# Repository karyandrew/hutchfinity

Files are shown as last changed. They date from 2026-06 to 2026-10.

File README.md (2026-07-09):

---
sensitivity: public
version: 1.0.0
---

# hutchfinity

A parametric, modular drawer chest system built around gridfinity-extended tubs at **half-pitch**.

## What

- **Tubs** = drawer pans, sized in cells (X × Y × Z) at user-chosen pitch
- **Casings** = single-piece enclosures that house one tub each; back + sides + top, no bottom, no front
- **Pegs** = press-fit dowels that link stacked casings vertically
- **Knobs** = optional glue-on pulls with broad, thin glue bases
- **Magnets** = optional press-fit retention + extended-warning detent

Tubs slide drawer-style on the top of the casing below (or on a footer / tabletop for the bottom-most). Casings stack into chests of arbitrary height. Same flat casing footprint = stackable; varying heights are fine. Multi-column chest assembly is a v2 goal.

## Why half-pitch

Gridfinity's standard pitch (42mm XY, 7mm Z) is too coarse for many small-parts organization use cases. The hutchfinity system uses **21mm XY / 3.5mm Z** — half of standard on each axis — for denser packing of small bins while preserving compatibility with standard gridfinity bin foot geometry. Bins printed for one pitch system can sit alongside bins printed for the other.

## Status

Pre-1.0. Architecture spec converged; SCAD and STL deliverables are being authored.

- **License**: GNU GPL v3.0 only; see `LICENSE` and `THIRD_PARTY_NOTICES.md`
- **Source**: OpenSCAD, built on top of [Gridfinity Extended OpenSCAD](https://github.com/ostat/gridfinity_extended_openscad)

## Credits

Gridfinity was created by **Zack Freedman** ([Hack Smith Industries](https://hackaday.io/project/180371-hack-smith-industries)). This project extends the gridfinity ecosystem; it isn't affiliated with the original creator.

## Contributing

Issues and PRs welcome.

## Repository map

- `wiki/` - evergreen implementation notes and validated recipes.
- `adr/` - architecture decision records.

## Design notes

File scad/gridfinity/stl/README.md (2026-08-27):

# Gridfinity STL files

For new tub and baseplate prints, use:

- `tub-mini.stl`
- `tub-regular.stl`
- `tub-mega.stl`
- `baseplate-mini.stl`
- `baseplate-regular.stl`
- `baseplate-mega.stl`

## Deprecated cropped baseplates

The following files are retained for historical comparison only and are not part of the current print set. Do not use them for new prints:

- `baseplate-mini-cropped.stl`
- `baseplate-regular-cropped.stl`
- `baseplate-mega-cropped.stl`

Height-specific tub variants and bin STLs elsewhere in this directory are unaffected by this deprecation.

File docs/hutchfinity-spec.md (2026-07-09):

---
version: 0.18.7
sensitivity: public
---

# Hutchfinity system spec

This technical spec translates `docs/chest-prd.md` into module contracts for the authored Hutchfinity SCAD parts. The chest PRD remains the product authority; this page defines the first casing interface so `casing.scad` can exist without silently deciding the provisional magnet and peg recipes.

## Casing contract

`scad/casing.scad` emits one drawer-slot casing in print orientation: the casing top is on the build plate and the side/back walls rise upward. The physical part has a top, left side, right side, and back; it has no front and no bottom. The current prototype cuts flat-wall stack sockets and provisional casing-side magnet wells by default.

The casing module is tub-agnostic. It accepts direct slot dimensions rather than importing `tub.scad` or deriving from tub cell count, pitch, or wall thickness. Assembly-level files such as `scad/hutchfinity-assembly.scad` choose casing slot dimensions that match a tub or preview target.

The target enclosed slot range is 200-450mm wide, 200-450mm deep, and 25-450mm tall. The current representative casing uses width for left/right across the drawer opening and depth for front/back drawer travel. For the regular tub, casing width spans the tub width, while casing depth uses the shared 16-cell front-to-back tub dimension. Stacked casings use the same flat casing footprint and prototype peg/socket geometry.

## Files

| File | Role |
|---|---|
| `scad/casing.scad` | Standalone casing shell with flat-wall stack peg sockets and provisional casing magnet wells. No tub import, no footer mode. |
| `scad/tub.scad` | Mini/regular/mega tub wrappers that import the current tub STLs and cut provisional bottom magnet wells. |
| `scad/peg.scad` | Prototype laid-down hex peg. |
| `scad/knob.scad` | Optional glue-on tub pull with a broad, thin flared base. |
| `scad/hutchfinity-assembly.scad` | Preview/assembly caller that can place casing, tub, knob, and pegs together. |
| `scad/casing-fit-test.scad` | Fit-test caller that maps current tub-source dimensions and named clearance candidates to a casing slot. |
| `scad/testbed/peg_socket_fit_testbed.scad` | Cheap coupon for provisional peg/socket clearance and chamfer checks. |
| `scad/testbed/hex_peg_set.scad` | Seven loose hex pegs for one representative casing stack interface. |
| `scad/testbed/peg_stack_interface_testbed.scad` | Rejected stack-land coupon retained only as a failed design reference. |
| `scad/testbed/casing_mouth_fit_gauge.scad` | Shallow front-mouth gauge for checking tub entry and top clearance before printing a full casing. |
| `scad/testbed/full_magnetic_drawer_inspection_set.scad` | Installed-coordinate inspection exports for aligned casing/tub magnet-interface and slot-fit checks. |
| `scad/testbed/magnet_well_shape_inspection.scad` | Real-CAD face coupons showing the current 5mm tub and 6mm casing magnet-well profiles. |
| `scad/testbed/mini_regular_mega_print_set.scad` | Selector source for the mini/regular/mega casing, magnetic tub, knob, and peg print packet. |
| `scad/testbed/build-mini-regular-mega-print-set.sh` | Builds the mini/regular/mega print packet and copies the matching committed grid baseplates. |
| `scad/testbed/casing-fit-trial-01.md` | Planned physical validation log for the #20 casing fit and peg/socket coupon print. |

No shared `hutchfinity-dimensions.scad` file is part of this pass.

## Coordinate convention

| Axis | Meaning |
|---|---|
| X | Left/right across the drawer opening. |
| Y | Front/back; `Y=0` is the open front, the back wall is at maximum Y. |
| Z | Print Z. `Z=0` is the bed-facing top surface; walls rise in +Z from the top slab. |

This convention keeps the STL in the intended no-support print orientation. In installed use, the bed-facing slab is the upper riding surface and the open side opposite it is the missing bottom. Documentation should name whether a dimension is a print-coordinate value or an installed-use value when ambiguity matters.

Socket face naming is deliberately explicit: installed-top sockets open on print `Z=0` through the top slab, while installed-bottom sockets open on the print `Z=print_z` wall-foot faces. The casing still has no bottom plate.

The PRD requires flat side and back exterior faces. External stack lands, pads, bosses, lugs, ribs, or other protrusions on the casing sides/back are rejected even if they would give peg sockets more material.

## Dimensional formulas

Default values are intentionally conservative fit-test numbers, not final ergonomic values. The current representative XY target is a thick-wall regular 12 x 16 tub with `256.4mm` left/right width and `340.4mm` front/back length from `docs/gridfinity-system-prd.md`. The fit-test caller maps that tub to a `258.4 x 340.9 x 85.24mm` slot: `1.0mm` side clearance per side, `0.5mm` closed-back clearance, and `1.0mm` top clearance. The current source tub height is 23u body height, so the tub exterior height is `23 * 3.5 + 3.74 = 84.24mm`, matching the rounded `84.2mm` total Z listed in `docs/gridfinity-system-prd.md`. The earlier PR #19 `73.74mm` value was a 20u representative casing target, not the current regular tub source height.

Thickness requirements are not finalized here. The printed part will not behave like a solid-wall analytical beam: slicer wall loops, sparse infill density/pattern, material, nozzle, and layer height all matter. This spec therefore keeps thicknesses as named prototype parameters rather than deriving them from a structural formula.

`scad/casing-fit-test.scad` is the physical-fit caller for issue #20. It separates three concepts that should not be conflated:

| Concept | Where it belongs | Notes |
|---|---|---|
| Tub source dimensions | `docs/gridfinity-system-prd.md` and tub build scripts | Current regular tub source is 23u total height with `2.2mm` walls, not the PR #19 20u casing target. |
| Casing slot clearance | `scad/casing-fit-test.scad` / assembly mapping | Geometry clearance around the printed tub; side, back, and top clearances are named separately. |
| Slicer contour compensation | Slicer/process profile and trial notes | The observed `+0.6mm` contour-compensation result was tub-print process evidence. It is not a casing wall-thickness formula. |

| Term | Formula / default | Notes |
|---|---|---|
| `slot_width` | `258.4mm` in the fit caller | Direct enclosed slot width: left/right across the drawer opening; tub width plus side clearance. |
| `slot_depth` | `340.9mm` in the fit caller | Direct enclosed slot depth: front/back drawer travel; shared tub front/back length plus closed-back clearance. |
| `slot_height` | `85.24mm` in the fit caller | Direct enclosed slot height for the current 23u source tub plus top clearance. |
| `outer_x` | `slot_width + 2 * side_thickness` | Includes left and right walls. |
| `outer_y` | `slot_depth + back_thickness` | Includes back wall; no front wall. |
| `print_z` | `top_thickness + slot_height` | Top slab plus wall height in print orientation. |
| `peg_axis_intervals_between` | `max(1, ceil((end - start) / peg_spacing))` | Derived; not an argument. |
| `peg_count` | length of perimeter socket positions | Derived from one `peg_spacing`; not an argument. |

There is no `bottom_thickness` term. The casing has no floor/bottom plate.

## Parameters

| Parameter | Default | Status |
|---|---:|---|
| `slot_width`, `slot_depth`, `slot_height` | `256.4, 340.4, 84.24` in `casing.scad`; `258.4, 340.9, 85.24` in the regular fit caller | Casing stays slot-dimension based; assembly/fit callers add tub clearance. |
| `side_thickness` | `25` | Prototype side wall value. |
| `back_thickness` | `25` | Prototype back wall value. |
| `top_thickness` | `10` | Prototype ceiling/riding surface; bed-facing in print orientation. |
| `peg_spacing` | `190` | Single target spacing. Count is derived per side and positions divide evenly between derived end insets. |
| `peg_diameter`, `peg_clearance` | `8, 0.45` | Prototype peg/socket fit values. |
| `peg_socket_depth`, `peg_chamfer` | `10, 2.5` | Prototype top-slab through-sockets and wall-foot sockets with generous chamfers at both ends. |
| `peg_socket_edge_land` | `4.0` | Minimum material land used when checking socket chamfer clearance. |
| `enable_peg_holes` | `true` | Cuts prototype top-slab sockets and matching wall-foot receiver sockets into the flat side/back wall footprints. |
| `enable_magnet_holes` | `true` | Cuts provisional casing magnet wells into the installed top surface. |
| `casing_magnet_bore_diameter`, `casing_magnet_rib_tip_diameter` | `6.40, 6.10` | Current 6mm magnet press-fit candidate. |
| `casing_magnet_well_depth`, `casing_magnet_chamfer` | `1.60, 0.30` | Current 6mm magnet pocket depth, `0.4mm` shallower than the 2.0mm recovery-sled pocket family. |
| `casing_magnet_fore_aft_inset` | `8.0` | Magnet center inset from the front/back travel edges. |
| `casing_magnet_paramedian_offset` | `21.0` | Lateral offset for the optional paramedian columns around the centerline. |
| `extended_warning_travel_fraction` | `0.75` | Places the rear-pair warning detent wells at 75% drawer travel. |
| `show_debug_markers` | `false` | Optional reference-point markers only when peg holes are disabled. |

Not casing arguments: tub cell counts, pitch values, tub wall thickness, tub-to-slot clearance, bottom thickness, footer/base controls, `peg_count`, and `peg_edge_margin`. Those belong to tub generation, assembly mapping, a future footer/base design, or a future validated interface.

## Provisional interfaces

Magnet dimensions are not final in this spec. `wiki/magnet-press-fit.md`, hutchfinity#7, and PR #13 remain the live sources for magnet press-fit validation.

The casing module now cuts nine provisional magnet wells into the installed top surface, which is print `Z=0`: six closed-position wells in two front/back rows and three lateral columns, plus three rear-magnet wells at 75% drawer travel as an extended-warning detent. The lateral columns are median and paramedian, centered on the drawer midline with `21mm` offsets. The current casing recipe is an 8-rib bore-minus-notch well: `6.40mm` bore, `6.10mm` rib-tip diameter, `1.60mm` deep, with a `0.30mm` chamfer.

`scad/tub.scad` wraps the current mini, regular, and mega tub STLs and cuts six bottom magnet wells in two front/back rows and three median/paramedian lateral columns. The current tub recipe is an 8-rib bore-minus-notch well: `5.40mm` bore, `5.25mm` rib-tip diameter, `1.10mm` deep, with a `0.30mm` chamfer. These wrappers do not make `casing.scad` depend on the tub model.

The casing module cuts prototype peg sockets by default. The stack is casing-to-casing: the bottom wall feet of an upper casing sit on the top slab of the casing below, and pegs register that pair. The open front span has no sockets because there is no front wall-foot receiver in the casing above.

The external stack-land approach tested in the previous model is rejected by the flat side/back requirement. Current casing sockets are centered in the 25mm side/back wall footprints and spaced from the open front and rear edges by the derived socket end inset.

Peg sockets use generous 2.5mm chamfers at their openings and deepest ends. `scad/peg.scad` uses a laid-down hex profile with no crush ribs. The default printable peg is 8.45mm point-to-point, matching the current `8.0mm` nominal socket plus `0.45mm` prototype socket clearance. The module `hutchfinity_peg()` still models the installed vertical peg for assembly use; `hutchfinity_peg_print_layout()` rotates it onto a flat-friendly face for standalone/testbed printing. The casing stack interface remains provisional until tested on an actual casing pair.

`scad/testbed/peg_socket_fit_testbed.scad` renders a small clearance sweep using the same socket cutter and laid-down hex peg print module: `0.30`, `0.45`, and `0.60mm` socket clearance around the 8mm nominal socket diameter, tested against an 8.45mm point-to-point hex peg. The raised index marks count from left to right. This coupon is a physical validation aid, not a locked press-fit recipe.

Footer behavior is outside `casing.scad`. A footer, tabletop, or future base/riser belongs in assembly-level design, not in the casing module argument surface.

## Render checks

Minimum first-pass check:

```bash
openscad -o preview/casing-representative.stl scad/casing.scad
```

Generated review artifacts should live under `preview/<issue-or-head>/` or another explicit trial directory. Avoid suffixes such as `final`; they do not say what changed or what commit produced the file.

Fit-test caller check:

```bash
openscad -o preview/casing-fit-trial-01/casing-fit-regular-23u.stl scad/casing-fit-test.scad
openscad -o preview/casing-fit-trial-01/fit-pr19-20u-check.stl -D FIT_TUB_HEIGHT_U=20 scad/casing-fit-test.scad
```

Peg/socket coupon check:

```bash
openscad -o preview/casing-fit-trial-01/peg-socket-fit-testbed.stl scad/testbed/peg_socket_fit_testbed.scad
openscad -o preview/casing-fit-trial-01/hex-peg-set-7.stl scad/testbed/hex_peg_set.scad
openscad -o preview/casing-fit-trial-01/tub-regular-magnetic.stl scad/tub.scad
```

Do not render or print `scad/testbed/peg_stack_interface_testbed.scad` for the current validation pass. It is retained only as a failed reference for the rejected external stack-land approach.

Assembly caller check:

```bash
openscad -o preview/casing-fit-trial-01/assembly-check.stl scad/hutchfinity-assembly.scad
openscad -o preview/casing-fit-trial-01/hex-peg-check.stl scad/peg.scad
openscad -o preview/casing-fit-trial-01/knob-check.stl scad/knob.scad
```

Physical validation packet:

```bash
openscad -o preview/casing-fit-trial-01/casing-mouth-fit-gauge.stl scad/testbed/casing_mouth_fit_gauge.scad
openscad -o preview/casing-fit-trial-01/casing-fit-regular-23u.stl scad/casing-fit-test.scad
openscad -o preview/casing-fit-trial-01/tub-regular-magnetic.stl scad/tub.scad
openscad -o preview/casing-fit-trial-01/peg-socket-fit-testbed.stl scad/testbed/peg_socket_fit_testbed.scad
openscad -o preview/casing-fit-trial-01/hex-peg-set-7.stl scad/testbed/hex_peg_set.scad
scad/testbed/build-mini-regular-mega-print-set.sh
```

Aligned inspection packet:

```bash
openscad -o preview/casing-fit-trial-01/aligned-inspection/casing-installed.stl -D INSPECTION_PART=1 scad/testbed/full_magnetic_drawer_inspection_set.scad
openscad -o preview/casing-fit-trial-01/aligned-inspection/tub-on-casing-top-closed.stl -D INSPECTION_PART=2 scad/testbed/full_magnetic_drawer_inspection_set.scad
openscad -o preview/casing-fit-trial-01/aligned-inspection/tub-in-slot-closed.stl -D INSPECTION_PART=4 scad/testbed/full_magnetic_drawer_inspection_set.scad
openscad -o preview/casing-fit-trial-01/aligned-inspection/pegs-installed.stl -D INSPECTION_PART=6 scad/testbed/full_magnetic_drawer_inspection_set.scad
```

Record the physical result in `scad/testbed/casing-fit-trial-01.md`. Casing and mouth-gauge artifacts print inverted; flip them into installed orientation for fit testing, with the slab above the tub and the walls down. The mouth gauge is a cheaper entry/ceiling check only; it does not replace full-depth casing slide validation. The current regular trial uses `1.0mm` side clearance per side, `0.5mm` at the closed back, and `1.0mm` above the tub.

For visual review, render a PNG from the same file when OpenSCAD is available. If OpenSCAD is unavailable, static syntax and parameter review are still required, and the missing renderer is reported in the PR.

## Acceptance criteria

- Casing dimensions are direct slot parameters, not coupled to tub internals.
- The casing has no front and no bottom.
- Same flat casing footprint casings cut a prototype two-ended peg/socket interface for vertical stacking.
- Tub body geometry is not rewritten to create the slide path.
- Optional knob geometry has a broad, thin glue base for tub attachment.
- Magnet geometry is present in the casing and mini/regular/mega tub wrappers, and stays explicitly provisional until physical validation closes the dependency.

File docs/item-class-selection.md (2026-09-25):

---
sensitivity: public
version: 1.1.0
---

# Neutral item-class selection

The selection contract maps generic geometry and handling needs to the existing half-pitch bin catalog. It deliberately separates three evidence levels:

1. Current-source geometry gives wall span, floor shape, and open-top height.
2. A rendered STL supplies an exact artifact hash and mesh bounding box.
3. Independently trusted physical and lane evidence supplies actual load, retrieval, base-engagement, and handling evidence.

Only the third level can support `ACCEPTED`. The first two remain `PROVISIONAL` even when every calculated margin is positive.

## Current catalog inventory

The generated inventory contains 126 tracked bin STLs:

- 22 are named by the current build script and are eligible for selection;
- 104 are tracked but unmanaged by the current build script, are marked `stale`, and are excluded; and
- 0 currently have a reproduced current-source-to-output byte link.

Each record includes the last commit touching the bound source/artifact paths (so committing this catalog or unrelated documentation does not invalidate it), SHA-256 hashes for the build recipe and vendored cup source, the exact STL SHA-256 and byte count, and parsed mesh AABB, volume, and triangle count. The mesh metrics are inventory and ranking evidence only.

The current official OpenSCAD snapshot can parse and render the unchanged source, so the historical OpenSCAD 2021 parser failure is obsolete. The selected current-source renders are geometrically consistent with the tracked artifacts by bounding box and rounded volume but are not byte-identical. No tracked STL is replaced here, and every source/output link remains `unverified`.

For current 21 mm-pitch, minimum-lip bins, the source-derived dimensions are:

```text
wall thickness = 0.95 mm below 6h, 1.2 mm below 12h, otherwise 1.6 mm
wall span XY   = cells × 21 − 0.5 − 2 × wall thickness
floor height   = 5.7 mm
open-top Z     = height_units × 3.5 + 3.74 − 5.7
floor radius   = 3.75 − wall thickness
flat-floor span XY = wall span − 2 × floor radius
```

The wall span is larger than the conservative full-footprint span because the cavity has rounded floor edges. That distinction matters for rigid flat objects and prevents a mesh or wall bounding box from being presented as a fit oracle.

## Deterministic selection

For every allowed orientation, the selector:

- rotates item dimensions, uncertainty, and requested grab clearance together;
- forms a required envelope by adding dimension + uncertainty + clearance on each known axis;
- rejects negative wall-span margins and rounded-corner conflicts;
- applies minimum long-axis, unobstructed-top, quantity, and flat-floor constraints;
- treats missing axes and a wall-pass/floor-fail split as `inconclusive`;
- rejects unsupported compartment, visibility, and retrieval-mode requirements;
- ranks passing build-managed SKUs by footprint, then height, parsed material-volume proxy, and wasted source-derived volume; and
- reports one next sufficient candidate when one exists.

A negative margin is a failure, never a “tight” pass. `CUSTOM_SKU_REQUIRED` is emitted only when a fully dimensioned class has no passing current candidate and no named inconclusive physical-fit target.

The numeric uncertainty and clearance values in `item-classes.json` are public v1 selection-policy inputs, not physical measurements or private quantities. Changing one changes the item-class hash and invalidates receipts bound to the prior revision.

## Initial mapping result

| Neutral class | Preferred target | Fallback | Source result |
|---|---|---|---|
| `long-rod-178` | `bin-2x9x10h` | `bin-2x10x10h` | Inconclusive: long-axis margin is 2.8 mm after uncertainty and grab clearance; cross-section and Z are intentionally unknown. |
| `square-stack-49` | `bin-3x3x10h` | `bin-3x5x10h` | Calculated pass: wall margins 5.6 × 5.6 × 0.54 mm; conservative flat-floor XY margins 0.5 × 0.5 mm. |
| `short-roll-40x15` | `bin-2x4x10h` | `bin-2x5x10h` | Calculated pass: the 81.1 mm wall span satisfies the 80 mm long-axis constraint; conservative clearance-envelope capacities are 2 and 4. Desired private capacity remains external. |
| `flat-185x82x13` | `bin-5x9x5h` | none | Inconclusive: positive wall margins include 0.6 mm on the long axis, but conservative flat-floor long-axis margin is −5.0 mm. Physical sampling is mandatory. |

All four rows remain `PROVISIONAL`: no exact artifact/item-class physical fit was run. The two calculated passes are geometry/handling calculations, not physical acceptance.

## Software checks, physical evidence, and downstream demand

The CLI now schema-checks closed dataset wrappers, records, demand requests, and generated output with date-time format enforcement. It resolves mappings against the repository's authoritative class set and catalog, recomputes class hashes and selections, and verifies current source and selected artifact bytes. A local physical-receipt claim is checked against the authoritative class envelope, minimum quantity, exact STL hash, lane fields, six physical checks, and workaround prohibition.

Those checks prove software structure, byte binding, and internal consistency only. Local caller-controlled JSON cannot prove that a sample was measured, an artifact was printed, a lane receipt came from an independent authority, or any physical check occurred. With no independently trusted physical/lane evidence configured, the CLI refuses every `ACCEPTED` claim and therefore refuses accepted-demand promotion. It does not create a signer or trust anchor from its own output.

The useful software residue is the closed neutral contract, authoritative binding, deterministic fit calculations, strict quantity/date handling, and fail-closed non-authorizing demand boundary. The remaining acceptance work is physical: preserve independently trusted lane evidence, print the exact artifact, bind a representative sample or surrogate, perform all fit and handling checks, and resolve the long-rod unknown axes and flat-object floor conflict. All four current mappings remain `PROVISIONAL/not_run`, and production authorization remains outside this interface.

## Local use

Use Python 3.10+ and `jsonschema` 4.x. The catalog is generated with
`python3 scripts/hutchfinity_catalog.py build-catalog --output catalog/bin-skus.json`.
Then run `select` with `--catalog catalog/bin-skus.json`,
`--classes catalog/item-classes.json`, and `--output catalog/item-class-map.json`.
Run the owned suite with `python3 -m unittest discover -s tests -v`.

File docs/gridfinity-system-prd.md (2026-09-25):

---
sensitivity: public
version: 5.1.3
---

# Gridfinity System PRD — Dental Practice Organization

**Audience:** agents drafting and testing SCAD models for the dental gridfinity system. Read this before designing or modifying any tub / baseplate / bin config. It's the owner's north star — your work points at it.

This is a PRD, not an SOP. It captures intent. The inventory operating manual lives at [`kary-dental/docs/dental_office_inventory_guide.md`](https://github.com/karyandrew/kary-dental/blob/main/docs/dental_office_inventory_guide.md); category and material inventory by operatory specialty lives in the "Dental Armamentarium" gdoc (planned for ingest into kary-dental).

## What you're building

Three printable artifact types, all at Gridfinity Extended (half pitch — 21mm XY, 3.5mm Z) — a deliberate variant of stock Gridfinity, not interoperable with 42mm parts.

| Artifact | Role |
|---|---|
| **Tubs** (3 SKUs: mini, regular, mega) | Bounding containers that sit in operatory drawers or on shelves/counters. PETG. Implemented as 1×1 Gridfinity Extended cups at custom pitch — walls and lip live outside the cell grid. Same model printed in different colors per operatory specialty. |
| **Internal baseplates** (3 sizes, one per tub) | Vanilla Gridfinity grid plate (just a grid — no clips, no locks). Drops into a tub at standard 21mm pitch. Bins sit on it via standard Gridfinity foot pattern. |
| **Bins** | Standard Gridfinity cups at 21mm pitch with foot pattern. Mix-and-match across all tubs. Color-coded per inventory category. Staff-printable. |

## Hard requirements (owner-stated)

| # | Requirement | Rationale |
|---|---|---|
| HR-1 | **Tubs stack on each other** (drawer + shelf use). Lip of lower tub seats the flat base of upper tub. Stackability is per-pitch — same-size tubs stack; mixed sizes do not. | Drawer is primary; shelf storage is real and frequent. Without stackability the system breaks for shelf use. |
| HR-2 | **Bins sit on the baseplate via standard Gridfinity foot pattern.** No clip, no lock — gravity + foot fit. | Baseplate is a vanilla gridfinity grid. Standard part. Don't invent locking mechanisms. |
| HR-3 | **Tubs and bins are portable; bins mix-and-match across tubs.** | Same internal grid pitch (21mm) everywhere = bins move freely between any tub without re-fit. |
| HR-4 | **Constrained model catalog.** All tubs share Z and depth (Y); only width (X) varies — 3 SKUs total. Bin sizes drawn from a small standard set. Don't spawn a new model per quirk. | Production sanity, visual consistency, learnable system. |
| HR-5 | **Easy to print, cheap to replace.** Bins must be staff-printable on a Bambu (no manual supports, no exotic settings, predictable). PETG, normal layer heights, no orientation tricks. | Replacement is routine, not engineering. Staff is not Andrew. |
| HR-6 | **Items retrievable by finger or college plier.** Bin geometry must permit one-handed access during procedures. | Point-of-use clinical work. No tool-fetching to retrieve. |
| HR-7 | **Color codes the operatory specialty (tub) and inventory category (bin).** | Glance-to-find is the primary navigation system. Labels are SKU-level (required); color is category-level (convenience). |
| HR-8 | **Label-bearable surface on every bin.** Brother P-Touch labels (12mm or 24mm with QR) adhere to bin walls, floors, or undersides. | Item ID labels are required (line in inventory guide). No special label holders — use existing bin geometry surfaces. |
| HR-9 | **No captured crevices.** Tub, baseplate, and bins are independent pieces that separate cleanly for cleaning. | Clinical setting; biofilm and disinfectant residue trap in crevices. |
| HR-10 | **Single-piece tub at all standard sizes (≤500mm bed).** | Seams capture debris. SV08 MAX is 500×500×500mm; mega tub fits as one piece. |
| HR-11 | **PETG body** (tubs, baseplates, bins). Autoclavable parts (cassettes, bur blocks) are a separate workstream on X2D / PPA-GF — not this PRD. | PETG: tough, dishwasher-tolerant, printable on the fleet, cheap. Autoclave-grade is overkill for organizers. |
| HR-12 | **Walls and lip live outside the cell grid.** Tub internal cavity is exactly `N × 21mm` (X) × `M × 21mm` (Y) so the internal baseplate at standard 21mm pitch fits natively. | Inverts the v2.0.0 architecture (tub-as-scaled-bin); the baseplate seats into a cell-grid-sized cavity rather than a wall-eaten cavity. |
| HR-13 | **No magnet holes, no label holders, no scoops on any bin** — for the whole catalog lineage, including prototypes, until owner reverses. Labels adhere directly to bin geometry per HR-8. | Tactile cleanliness, print simplicity, fewer crevices. Reinforces HR-9 (no captured crevices) and HR-5 (staff-printable, predictable). |

## Color codes

Each operatory specialty maps to a color. Tubs are printed in that color; bins per category in that operatory may further encode item type (sub-color or hue variant — TBD).

| Color | Category | Mnemonic source |
|---|---|---|
| Green | Hygiene | Cavitron tip, mint toothpaste |
| Blue | Endo & IVS | Blu Core |
| Pink | Removable | Denture acrylic |
| Gray | Ortho | Brackets |
| Yellow | Restorative | Bonding agent |
| Orange | Fixed + Crown + Implant pros | Rely-X Universal; revised from Black to free Black for Records/Eval. Crown is the most common subset of Fixed → shares. Implant pros is fixed-prosth-on-implants → same logic, shares. |
| Black | Records/Eval | X-ray |
| Purple | Perio | (perio = purple by convention) |
| Red | Surgery / Exo | Bloody socket |
| Brown | General consumables | Weak alliteration ("Brown" / "Basic"). Brown items show up across many specialties — basic exam kit (mirror, explorer, cotton tweezers, 11/12 explorer), anesthesia carpules, chairside disposables (microbrushes, air/water tips). |
| (no specialty color) | Anesthesia & Sedation | Cart-level supply rather than a specialty workflow — staff goes to the cart, not the color. Default un-coded PETG. |
| N/A | Pedo, Cosmetic/Bleaching, Photography | Not in current practice scope. |

**Color rules:**
- **White is the wildcard** — allowed on any tub or bin, but **cannot be assigned to a specialty**. Assigning white to a category would break glance-to-find: any uncoded white piece would falsely signal that category. White means "nonspecific," everywhere.
- Orange / Yellow proximity is acceptable — Fixed and Restorative share a lot of workflow; confusing the two is harmless.
- Color stability is load-bearing — once staff learns "green = hygiene," reassigning the color burns trust. Color → category mapping changes go through Andrew, not the agent.

## Drawer compatibility

Tub catalog must serve this drawer set:

| Drawer | H × W × D interior (mm) | Plan | Slack W × D (mm) | H slack (mm) |
|---|---|---|---|---|
| Cart shallow | 74 × 318 × 419 | **excluded** (tub Z 84.2 > 74) | — | −10.2 |
| Cabinet narrow | 89 × 305 × 381 | 1× regular | 49.8 × 41.8 | 4.8 |
| **Cabinet med** (15"=381 wide; dominant) | 89 × 381 × 381 | 1× regular + 1× mini | **−3.4 × 41.8** (W interference; v5.0.0 marginal — physical drawer test gates validation) | 4.8 |
| Cabinet x-wide (24") | 89 × 610 × 381 | 1× mega + 1× mini *or* 2× regular | 99.6 × 41.8 (M+m) / 99.6 × 41.8 (2R) | 4.8 |
| Cart standard | 89 × 318 × 419 | 1× regular | 62.8 × 79.8 | 4.8 |
| Cart medium | 114 × 318 × 419 | 1× regular; items extend above tub | 62.8 × 79.8 | 29.8 |
| Cart deep | 140 × 318 × 419 | 1× regular; items extend above tub | 62.8 × 79.8 | 55.8 |
| Counter | TBD | 1× mega | TBD | TBD |

**Key principle:** items / bins may stick up above the tub Z. Tub height isn't sized to fill the drawer — only to retain bins, give structural rigidity, and provide the stacking lip. Bins are flexible (fast to reprint, waste OK). Tub catalog stays small (3 SKUs).

**Mini's two pairing roles:**
1. Alongside regular in cabinet med (binding constraint; pinned mini width to 5 cells in v3.x at W=2.625, bumped to 6 cells in v4.0.0 at W=1.6 — fit becomes marginal, gated on physical drawer test).
2. Alongside mega in cabinet x-wide.

## Architecture

Tubs are implemented as **1×1 Gridfinity Extended cups at custom pitch**, not as N×M bins. The cell-grid pitch (21mm) is unchanged; what changes per tub size is the cup's outer pitch.

```
pitch_xy = N × 21 + 2W + C   // C = library cup-outer clearance — see Tolerances
width = [1, 0]
depth = [1, 0]
height = [23, 0]              // body 23×3.5 = 80.5mm; sized so a 20h max bin's lip top
                              // does not exceed lower body top → upper tub bottom clears
                              // bin lip when tubs stack (see Vertical stack-fit section)
wall_thickness = W
floor_thickness = 1.2         // vendor default (was 3.5 in v3.x)
lip_style = "minimum"
flat_base = "gridfinity"      // stackable via lip on tubs of same pitch
```

Cavity (actual) = `pitch_xy − C − 2W` per library at `gridfinity_basic_cup.scad:798` (`container_width = num_x × pitch − clearance − 2 × wall_thickness`). With `pitch_xy = N × 21 + 2W + C`, cavity = `N × 21` exactly. Internal baseplate exterior renders at `N × 21` exactly — the library does NOT apply outer clearance to baseplates; the `clearance` parameter in `gridfinity_baseplate.scad` affects internal pocket sizing, not the outer envelope. Cavity and baseplate are the same `N × 21` dimension by construction; design clearance is zero. PETG dimensional variance (~±0.2mm typical) provides the natural play that lets the baseplate seat without binding.

Same-size tubs stack on each other (shared pitch_xy → matched lip pattern). Mixed-size tubs do not stack.

### Wall thickness

**W = 2.2mm** — explicit tub wall value. This is the CAD replacement for the `+0.6mm` slicer contour-compensation hack that improved printed tub stacking and strength; do not carry that compensation into casing wall thickness.

Tubs retain bins and provide the stacking lip, but the earlier `1.6mm` wall setting was too weak in physical prints. The prior v3.x value of 2.625mm (= 21/8 — "pitch elegance") is still rejected as cosmetic; `2.2mm` is the current physical-fit compromise. Cup walls are independently set by the cup library default of 1.2mm at h<16u; tubs and cups don't need to match.

Floor thickness `floor_thickness=1.2mm` follows the same logic — vendor `default_floor_thickness` (line 518). Prior 3.5mm "floor sandwich" was over-spec; thinner floor + same body height grows the cavity Z. Z is just `Nu body`, and cavity Z is whatever's left after `floor_thickness`. v5.0.0 sets body height to **23u** (was 21u in v4.x) — sized so a 20h max bin's lip top sits at or below the lower body top, allowing tub-on-tub stacking without the upper tub crashing into bin lips. See [Vertical stack-fit](#vertical-stack-fit-half-pitch-correction) for the geometry derivation.

## Stock Gridfinity baseplate compatibility

Half-pitch (21mm) cells preserve a real backward-compat surface to stock 42mm Gridfinity baseplates: **any 2×2-or-larger arrangement of half-pitch bins mates a stock 42mm baseplate** (verified in hand). 1×1 half-pitch bins do NOT — the half-scaled foot is too small for the stock pocket and rattles. Footprint commensurability (2 half-pitch cells = 1 stock cell) plus the library-canonical foot pattern is what makes the mate work.

This compatibility constrains foot/lip geometry choices going forward:

- **Slimmer half-pitch feet** would mitigate the half-pitch sandwich math (recovering ~7mm of tub Z by reducing the foot+lip+floor sandwich consumption) but **would also erode the stock-baseplate mate.** Foot-to-pocket lock relies on chamfer engagement, and chamfer geometry is foot-height-dependent — shorter foot = different chamfer profile = degraded engagement to stock pockets. The stock-baseplate compat is tested-and-valued, so slim-foot proposals are blocked unless the export-compat is explicitly waived.
- **Importing stock 42mm community designs** is independent of foot height — boolean surgery (strip stock foot, add half-pitch foot pattern) works regardless of slimming choices. Slim feet would only break the *export* direction (half-pitch arrangement → stock baseplate), not the import direction.

Considered and rejected: switching to 25mm pitch (Nested Tub System PRD 1.0.0 candidate, archived 2026-05-13 at [`docs/archive/nested-tub-system-prd.md`](archive/nested-tub-system-prd.md)). 25mm forfeits stock-baseplate mate entirely with no offsetting concrete benefit. Per-axis rationale at [`docs/archive/prd-decision.md`](archive/prd-decision.md).

## Tolerances

All multi-part fits are tracked here as named terms. PRD edits that change any tolerance update both this table and the architecture math, in the **same PR as the SCAD/STL change** they affect. Tribal knowledge ages out; the PRD is the contract.

| Term | Value | Where it lives | What it does |
|---|---|---|---|
| `C` (library cup-outer clearance) | 0.5mm total (= 0.25/side) | Library default, applied automatically to cup outer: lip extent = `pitch_xy − C`. Not a tunable knob in wrappers. | Spaces adjacent same-pitch tubs apart so 2× regular in cabinet x-wide sit with ~0.25mm/side between them. |
| Tub cavity ↔ baseplate | 0mm design clearance (snug; PETG variance is the slop) | Tub `pitch_xy` formula sets cavity = `N × 21` = baseplate exterior. | Baseplate seats on tub floor without rattle. Not a sliding fit — installed once. |
| Bin foot ↔ baseplate pocket | 0.5mm total (Gridfinity standard) | Library default in cup foot vs baseplate cell math. | Bins drop in/out of pockets one-handed. |
| Tub exterior ↔ drawer | per-drawer slack column in Drawer compatibility table (smallest = **−3.4mm interference**, cabinet med — v4.0.0 marginal, validates by physical print) | Drawer compatibility table. | Finger access; survives temperature/humidity expansion. |
| Tub stack mate | 0 (gridfinity foot ↔ lip is intentionally snug) | Library `flat_base = "gridfinity"`. | Two same-size tubs lock by foot/lip geometry, not by clearance. |

## Vertical stack-fit (half-pitch correction)

Standard gridfinity assumes "tub of N units holds bin of (N − 1) units" — at full pitch (1u = 7mm), the floor + bin foot + bin lip sandwich consumes ~1u of vertical space and the rule works. **At half-pitch (1u = 3.5mm) the lib does NOT scale the cupbase / lip / floor constants down**, so the sandwich consumes more than 1u and the rule breaks.

### Empirical geometry (mini tub, half-pitch)

Verified by spot-probing the rendered STLs at cell centers:

| Surface | Z (mm) | Notes |
|---|---|---|
| Tub foot pattern bottom | 0 | external |
| Tub foot pattern top | 4.75 | = `gf_cupbase_*_taper_height` sum (NOT `gf_base_grid_clearance_height`) |
| **Tub interior cavity floor** | **4.75** | floor sits on top of foot pattern; `floor_thickness=1.2` is in addition but is "inside" the body Z |
| Baseplate (sitting on cavity floor) | 4.75 → 8.75 | 4mm thick |
| **Bin Z=0 (= foot bottom)** | **4.75** | baseplate pocket is open through, so foot rests at pocket-bottom = baseplate bottom |
| Bin lip top | 4.75 + N×3.5 + 3.74 | lip = 3.74mm constant |
| Tub body top | N_tub × 3.5 | |
| Tub rim (= body top + lip) | N_tub × 3.5 + 3.74 | |

### Stack-fit invariant

When two same-size tubs stack, the upper tub's external bottom seats at the lower tub's body top (= `N_tub × 3.5`). For the upper tub bottom to NOT crash into bin lip tops in the lower tub:

```
bin lip top ≤ lower tub body top
4.75 + N_bin × 3.5 + 3.74 ≤ N_tub × 3.5
8.49 + N_bin × 3.5 ≤ N_tub × 3.5
N_bin ≤ N_tub − 2.43

→ rule (rounded for clearance):  N_bin ≤ N_tub − 3
```

So at half-pitch a **23h tub holds a 20h max bin** with 2.01mm clearance below the upper tub bottom when stacked. v4.x's 21h tub left a 20h bin protruding 2.96mm above the rim — broke HR-1.

### Off-by-one history

- Initial v5.0.0 attempt bumped 21h → 22h, but bin lip top still exceeded body top by 1.49mm. The half-pitch sandwich is ~3h, not the standard ~1h.
- Discovered by building an empirical assembly (tub + baseplate + bins + stacked upper tub) in OpenSCAD and bbox-probing each component's Z extent.
- Methodology: render each isolated piece (`probe-1h-lipnone.stl`, etc), spot-probe at cell centers via `intersection() { import(stl); cube at (X, Y, Z); }`, find the Z transition where solid → cavity.
- Closes [#146](https://github.com/karyandrew/3d-printing/issues/146).

## Tub catalog

Three SKUs. Identical Z and depth (Y); only width (X) varies.

| Tub | Cells (W × D × H) | pitch_xy (X × Y mm) | Cavity W × D (mm) | Cavity Z (mm) | Exterior W × D (mm) (= pitch_xy − C) | Total Z incl lip (mm) |
|---|---|---|---|---|---|---|
| Mini | 6 × 16 × 23  | 130.9 × 340.9 | 126 × 336 | 79.3 | 130.4 × 340.4 | 84.2 |
| Regular | 12 × 16 × 23 | 256.9 × 340.9 | 252 × 336 | 79.3 | 256.4 × 340.4 | 84.2 |
| Mega | 18 × 16 × 23 | 382.9 × 340.9 | 378 × 336 | 79.3 | 382.4 × 340.4 | 84.2 |

Mini bumped 5→6 cells X in v4.0.0; H bumped 21→23 in v5.0.0 (see Vertical stack-fit section).

Lip protrusion above body ≈ 3.74mm (constant — does NOT scale with pitch_z). Cavity Z = body − floor_thickness = 80.5 − 1.2 = 79.3mm.

| Param | Value (all 3 SKUs) |
|---|---|
| Pitch (cell grid) | 21 × 21 × 3.5mm |
| Wall thickness | 2.2mm |
| Base | Flat (`flat_base="gridfinity"`) |
| Lip | `lip_style="minimum"` |
| Floor | 1.2mm (vendor default) |
| Material | PETG |
| Printer | SV08 MAX |
| Nozzle / layer | 0.6mm / 0.3mm |

## Baseplate specs

Three baseplates, one per tub size. Standard 21mm Gridfinity pitch. Exterior = `N × 21` exactly — library does NOT apply outer clearance to baseplates (`clearance` in `gridfinity_baseplate.scad` affects internal pocket sizing, not the outer envelope). Cavity = `N × 21` by construction (see Architecture); design clearance is zero.

| Baseplate | Cells (W × D) | Exterior W × D (mm) | Tub cavity | Design clearance |
|---|---|---|---|---|
| Mini | 6 × 16  | 126 × 336 | 126 × 336 | 0 (snug) |
| Regular | 12 × 16 | 252 × 336 | 252 × 336 | 0 (snug) |
| Mega | 18 × 16 | 378 × 336 | 378 × 336 | 0 (snug) |

All single-piece printable (largest = 378mm < SV08 500mm bed).

| Param | Value (all 3) |
|---|---|
| Pitch | 21 × 21mm (standard Gridfinity) |
| Z thickness | ~4mm |
| Pattern | Vanilla Gridfinity grid (through-pockets, one per cell) |
| Material | PETG |
| Printer | SV08 MAX, single piece |

No clips, no special locks. Baseplate sits in the tub bottom, bins drop in via foot pattern.

## Bin specs

Standard bin set — keep tight. Add only when inventory→bin mapping forces it.

| Param | Value |
|---|---|
| Pitch | 21 × 21 × 3.5mm |
| Base | Foot pattern (`flat_base="off"`) |
| Lip | `lip_style="minimum"` (note: reduced lip on small bins is a derived spec to preserve interior volume + finger access — not a separate requirement) |
| Compartments | Single (`vertical_chambers=1`, `horizontal_chambers=1`) baseline; multi-compartment as inventory demands |
| Color | Per inventory category (see Color codes table) |
| Material | PETG (default) |
| Printer | X2D primary bin/cup lane under the matching current #37 validation receipt; SV08 only under its own matching validated lane; no retired-printer dependency |
| Nozzle / layer | 0.4mm / 0.2mm |
| Print constraint | No manual supports. No orientation tricks. Predictable for staff to run. (HR-5) |

Two physical instances of each bin per item per operatory (front = active, back = reserve — 2-bin pattern from inventory guide).

**Foot-pattern gotcha (read before editing `dental/build-stl.sh`):** bins MUST use `flat_base="off"` (library default) so the cup gets N×M individual feet at the cell pitch and mates baseplate pockets. Do NOT copy `flat_base="gridfinity"` from `TUB_FLAGS` — that collapses the entire N×M footprint to ONE big pad (per `pad_copy` logic in `scad/gridfinity/vendor/extended/gridfinity_basic_cup.scad:7801`). The `gridfinity` value is only correct for tubs because tubs stack on each other lip-to-foot; bins sit IN baseplates. Tripped on first bin build (rebuilt as commit `eb24396`).

**HR-13 reminder (cross-reference):** no magnets, no label holders, no scoops on bins. `BIN_FLAGS` sets `enable_magnets=false`, `enable_screws=false`, `label_style="disabled"`, `fingerslide="none"` explicitly so the rule is visible at the build call site even though the library defaults already match.

## Owner success criteria

System works when all hold:

1. **Drawer fit.** Each tub size seats in its target drawer (per Drawer compatibility table). Closes and opens without binding. Finger-access clearance preserved.
2. **Stackability.** Two same-size tubs stack stably on a level surface; lift the upper tub from the lip without lower tub coming with it under <500g vertical force.
3. **Baseplate seat.** Baseplate sits flat on the tub floor at 0mm nominal design clearance; any observed slack comes from print variance. It doesn't lift when bins are removed.
4. **Bin retrieval.** Items in any bin can be picked with a college plier or a finger; one-handed; no tools to extract the bin itself.
5. **Mix-and-match.** Bins move from any tub to any other tub and seat correctly without re-fitting.
6. **Staff-printable.** A trained assistant prints a replacement bin from STL → slicer → printer → done. No agent intervention.
7. **Glance-to-find.** Person who's seen the color legend once can locate the tub for a category in <3s on a shelf or in an open drawer.
8. **2-bin operatory pattern.** Empty back-position is visible at a glance; restock between patients.
9. **Subjective.** Team reaction is "holy shit this is sweet," not "what the fuck is this mess." Owner judges; agents don't override.
10. **Artifact- and printer-lane validation gate.** Before production, the exact artifact family and printer/profile/material tuple must have a current matching #37 `PASS_CURRENT_PROFILE` receipt that remains valid under #37's invalidation rules. Large tubs/large parts use the SV08 large-part lane; bins/cups use the X2D bin/cup lane by default. #38 may start only the matching production run; a pass in one lane does not authorize another.

## Open items (do NOT silently decide)

When you hit one of these, surface as a blocker — don't pick.

The production split is no longer open: #37/#38 assign large tubs and large parts to the SV08 MAX lane and bins/cups to the X2D lane by default. Any substitution requires its own matching validation receipt and run manifest.

| # | Item | Blocker |
|---|---|---|
| 1 | Bin sub-color within a tub (item type vs whole-tub-uniform) | UX question — owner |
| 2 | Standard bin size set (final) | Inventory→bin mapping; expected to evolve months 1–2 of practice operation per inventory guide |
| 3 | Counter-use megatub footprint (when counter dimensions need a bigger SKU than 18×16) | Counter measurement; current mega is locked to 18×16 for cabinet x-wide compatibility |

## Implementation guidance

**File paths:**
- Vendored library: `scad/gridfinity/vendor/<lib>/` + `VENDOR.md` (SHA + provenance)
- Dental build script: `scad/gridfinity/dental/build-stl.sh`
- Rendered STLs: `scad/gridfinity/stl/`
- Bins (when introduced): `scad/gridfinity/dental/bin-{X}x{Y}x{Z}.scad` — cells X × Y × cell-height Z. Build mechanism for bins is TBD (likely added as a second pass in `build-stl.sh` once bin work starts).

**Build pattern:** `dental/build-stl.sh` is a plain bash script that invokes the vendor combined file directly via `openscad -D <var>=<value>` flags. Project-level constants (wall thickness, lip style, floor thickness, chambers, magnets/screws) live in `TUB_FLAGS` / `BASEPLATE_FLAGS` arrays at the top of the script. Per-SKU params (pitch X for tubs; Width for baseplates) inline per invocation line. Adding a SKU = one new line. **Do not introduce per-SKU wrapper `.scad` files**; the WET wrapper pattern was the v3.0.0/v3.1.0 architecture and was retired in v3.2.0 (see Anti-patterns).

**STL naming:** `tub-{mini,regular,mega}.stl`, `baseplate-{mini,regular,mega}.stl`.

**Library:** Gridfinity Extended ([ostat/gridfinity_extended_openscad](https://github.com/ostat/gridfinity_extended_openscad)) at SHA `8b3a6c570c40ec1501ed61bc958835c06ffb7b8c`. **Don't change the library or the SHA without owner sign-off.**

**Toolchain:** OpenSCAD snapshot ≥ 2023.x (Extended uses trailing-comma syntax that 2021.01 stable rejects). Verified with 2026.04.26 snapshot.

**Each new SKU commit must include:**
- New invocation line in `dental/build-stl.sh`
- Rendered STL in `stl/`
- Bounding-box dimensional check vs spec (in PR description or commit message)
- OpenSCAD manifold check (`Status: NoError`, expected genus)
- One-PR-per-validation-gate for novel architectures; multiple SKUs may ship in one PR when they share architecture and differ only in param values (the v3.2.0 refactor PR shipped all 3 tubs + 3 baseplates because they're geometrically identical except for axis params).

## Anti-patterns

- Picking a different library or pitch.
- **Modeling tubs as scaled-up N×M bins** — walls eat the cell-grid cavity. Tubs are 1×1 cups at custom pitch; cell grid lives in the internal baseplate (HR-12).
- **Re-introducing per-SKU wrapper `.scad` files** when adding a SKU. The v3.0.0/v3.1.0 wrapper pattern was three near-identical files per family differing in 1–2 params; v3.2.0 retired it for `dental/build-stl.sh`. Add a line, not a file.
- Silently filling in an open item.
- Bundling tubs + baseplates + bins in one PR before the tub validates.
- Skipping pre-print validation (manifold, bounding box, visual).
- Adding a new tub size when an existing one almost works.
- Designing a special label holder. Use bin walls/floors/undersides.
- Inventing "clip" or "lock" mechanisms on the baseplate. It's just a grid.

## References

- Inventory operating system: [`kary-dental/docs/dental_office_inventory_guide.md`](https://github.com/karyandrew/kary-dental/blob/main/docs/dental_office_inventory_guide.md)
- Category and operatory armamentarium: "Dental Armamentarium" gdoc (planned for ingest)
- Design execution tracker: [3d-printing#105](https://github.com/karyandrew/3d-printing/issues/105)
- v3.0.0 architecture rewrite: [3d-printing#139](https://github.com/karyandrew/3d-printing/issues/139)
- v3.0.0 doc-cleanup precursor (folded in): [3d-printing#138](https://github.com/karyandrew/3d-printing/issues/138)
- Upstream ask: [kary-dental#52](https://github.com/karyandrew/kary-dental/issues/52)
- Library: [Gridfinity Extended](https://github.com/ostat/gridfinity_extended_openscad) (vendored at `scad/gridfinity/vendor/extended/`)
- Production validation lanes: [hutchfinity#37](https://github.com/karyandrew/hutchfinity/issues/37)
- Production runs: [hutchfinity#38](https://github.com/karyandrew/hutchfinity/issues/38)
- Sensitivity / HIPAA: bins do not store PHI. Patient data lives only in HIPAA-regulated systems per [`second-brain/.claude/rules/sensitivity.md`](https://github.com/karyandrew/second-brain/blob/main/.claude/rules/sensitivity.md).
- Autoclavable workstream (separate PRD): [3d-printing#61](https://github.com/karyandrew/3d-printing/issues/61), [3d-printing#122](https://github.com/karyandrew/3d-printing/issues/122)

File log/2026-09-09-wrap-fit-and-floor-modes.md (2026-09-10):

---
type: log
sensitivity: public
date: 2026-09-09
status: shelved
branch: chatgpt/wrap-2026-09-09-fit-and-floor-modes
issues:
  - https://github.com/karyandrew/hutchfinity/issues/20
  - https://github.com/karyandrew/hutchfinity/issues/29
  - https://github.com/karyandrew/hutchfinity/issues/30
---

# Wrap: Hutchfinity fit, magnet, and low-floor experiments

## Summary

This session preserved three connected prototype results without promoting untested conversation-generated geometry into production source.

The 10×10×10h tub slid successfully in its matching direct-parametric casing, the current hex pegs fit well, and magnetic attraction across the assembled interface was good. The glue-on pull remains a drawer pull; its long-term bond is untested, and the selected alignment aid is a shallow outline immediately outside the flange.

The dual-face magnet matrix failed as a transferable production recipe. Most long-rib candidates on the fine-profile print were too tight, while every new long-rib candidate on the coarse high-flow print had clearance and was far too loose. The unchanged 8B control remained the best coarse-process result, but one fine-profile control was itself too tight. The next bounded experiment is a plain round-bore dual-face coupon, not another rib-count search.

The Regular tub direction is now a thin mostly-flat floor, a shorter shell that preserves the existing clearance above the tallest intended inserts, and three floor modes: plain, integral grid, and a plain tub with a removable open-bottom grid. The removable insert keeps printable sloped perimeter rail ends while removing only unsupported bridging membranes. A current integral-grid slice was reported at approximately 3.5 hours versus approximately 5.5 hours for the former tub-plus-separate-grid workflow, with less filament and less handling.

No production SCAD or STL was committed in this wrap. Draft PR #31 remains unmerged because the current eight-rib magnet recipe is not yet a satisfactory cross-process production fit.

## Knowledge enumeration

| # | Category | Preserved result or decision | Durable record |
|---:|---|---|---|
| 1 | Physical fit | The 10×10×10h tub slides in its matching casing; the current hex pegs fit well. Validation is limited to the small prototype. | [Issue #20 physical-result comment](https://github.com/karyandrew/hutchfinity/issues/20#issuecomment-5612514760) |
| 2 | Pull alignment | Keep the broad glue-on pull flange and add a shallow outline immediately outside it; do not place a raised pad under the bond. Long-term bond durability remains unknown. | [Issue #20 physical-result comment](https://github.com/karyandrew/hutchfinity/issues/20#issuecomment-5612514760) |
| 3 | Magnet matrix | Fine-profile candidates were mostly too tight; coarse high-flow candidates all had clearance and were far too loose. The failed coarse candidates did not contact the magnet, so compliance does not explain that result. | [Issue #30 matrix-result comment](https://github.com/karyandrew/hutchfinity/issues/30#issuecomment-5612522876) |
| 4 | Magnet control | Magnets seat fully at 2.30 mm depth and attraction is good, but one fine-profile 8B control was too tight and insertion friction is marginally excessive. | [Issue #30 matrix-result comment](https://github.com/karyandrew/hutchfinity/issues/30#issuecomment-5612522876) |
| 5 | Next magnet experiment | Use one dual-face plain round-bore coupon sweeping 5.90–6.30 mm in 0.05 mm increments, plus unchanged 8B; retain 2.30 mm depth and 0.30 mm lead-in. Select the largest bore that reliably retains across intended processes. | [Issue #30 matrix-result comment](https://github.com/karyandrew/hutchfinity/issues/30#issuecomment-5612522876) |
| 6 | Regular tub architecture | Preserve approximately 2.2 mm structural walls, use a thin mostly-flat floor with only local stacking-foot accommodation, and shorten the shell rather than preserving unused Z. Default Regular tubs need not carry magnet wells. | [Issue #29 floor-mode comment](https://github.com/karyandrew/hutchfinity/issues/29#issuecomment-5612528258) |
| 7 | Floor modes | Support plain/no-grid, integral-grid, and plain-plus-removable-grid modes. The removable insert has no backing floor; cells open to the tub floor. Retain sloped perimeter rail ends and remove only portions that would bridge across edge cells. | [Issue #29 floor-mode comment](https://github.com/karyandrew/hutchfinity/issues/29#issuecomment-5612528258) |
| 8 | Production economics | The current integral-grid slice was reported at about 3.5 hours versus about 5.5 hours for the old tub plus separate grid, while also using less filament and eliminating a separate handling/installation operation. | [Issue #29 floor-mode comment](https://github.com/karyandrew/hutchfinity/issues/29#issuecomment-5612528258) |
| 9 | Prototype identity | 10×10×10h Print 02: `1a2ab09b70989dbb174f9cf0d2a9da5fad26be29a2bdafe6da010a61226957e1`; dual-face rib matrix: `e6eed5c62a8ff23b83302ba2b438192a3282b1df2c32aa531314af69b80101d6`; Regular floor modes revision 05: `d51ba7e090503f02a584c3c4beb71f346adf040f9ec285fce5630111a343e9a3`. | The three issue comments above |

## V&V

Verification:

- Read the current Hutchfinity governing instructions, Gridfinity system PRD, issues #20, #26, #29, and #30, and draft PR #31 before preservation.
- Posted and fetched back the three issue comments listed above.
- Replaced each owning issue's stale top-level `next-route` / `next-action` pair and fetched the resulting issue body back from GitHub.
- Issue #20 now routes canonical reconciliation of the successful small casing/tub and peg results to an agent.
- Issue #29 now identifies a physical `LIVE_TEST` operator action rather than an Owner Queue judgment.
- Issue #30 now routes the plain round-bore coupon build to an agent and explicitly leaves draft PR #31 unchanged pending physical evidence.
- No production SCAD, STL, slicer profile, or active implementation PR was changed by this knowledge harvest.
- No local OpenSCAD, slicer, mesh, or repository-hook command ran in this connector-only wrap. Geometry claims about the unprinted removable insert remain provisional.

Validation status: established

Evidence type: independent-non-behavioral

Evidence: operator-message: first-party physical observations and slicing times in the current session, preserved verbatim in the linked issue comments

Qualification: The operator observations directly test insertion, fit, retention, and print-time behavior of the named physical prototypes. GitHub readback establishes preservation fidelity. This evidence does not validate unprinted geometry, long-term glue durability, furniture-scale strength, or a final production magnet recipe.

Observation: The durable issue records preserve the reported successes, failures, corrections, and open gates without converting prototypes into accepted production source.

Falsifier: A direct operator correction showing that a recorded physical result is wrong, a hash mismatch for a named prototype packet, or later physical testing that contradicts a design proposal would require a corrective record and renewed validation.

Result: pass

## Step matrix

| Step | Result |
|---|---|
| Governing repository and issue state read | ✅ |
| Issue #20 physical result preserved and routing repaired | ✅ |
| Issue #29 low-floor/floor-mode direction preserved and routed to physical test | ✅ |
| Issue #30 magnet result preserved and routed to round-bore coupon | ✅ |
| Draft PR #31 merged or promoted | ⏭️ No — intentionally left draft and unmerged |
| Production SCAD/STL integration | ⏭️ No — physical gates remain |
| Local geometry/slicer checks during wrap | ⏭️ Unavailable on this connector-only surface |
| Public wrap archive | ✅ This file |
| Final carrier merge receipt | Recorded on the wrap carrier PR after landing |

## Verdict

Safe to close · 🅿️ Shelved

The session's useful knowledge and routing are preserved. Implementation is intentionally incomplete because the round-bore coupon, low-floor integral tub, and removable open-bottom insert still require physical validation.

## Reopen criteria

Validator: operator physical testing, followed by deterministic geometry and slicer checks during canonical source integration.

Gating condition: obtain the plain round-bore coupon results; test cup seating, stacking clearance, floor stiffness, and print quality on the low-floor integral-grid tub; test drop-in/removal and edge-cell behavior of the open-bottom sloped-edge insert; then reconcile the winning geometry into canonical source.

Work-state pointer: issues #20, #29, and #30; draft PR #31 remains the unmerged eight-rib carrier pending the magnet decision.

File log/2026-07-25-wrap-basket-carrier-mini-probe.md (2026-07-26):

---
sensitivity: public
date: 2026-07-25
branch: codex/basket-carrier-mini-probe
pr: https://github.com/karyandrew/hutchfinity/pull/27
issue: https://github.com/karyandrew/hutchfinity/issues/26
---

# Wrap: Mini Basket/Carrier comparison probe

## Summary

Completed the CAD-only Mini Basket/Carrier comparison slice from issue #26. The change vendors the pinned MIT-licensed Gridfinity Basket source, adds a general half-pitch parameterized probe with plain, integral-grid, and removable-grid modes, and records reproducible comparisons against the current Mini tub. The evidence supports keeping the candidate as a parallel experimental module rather than subsuming the existing tub. PR #27 merged the work into `main`; physical printing and live-device work were deliberately excluded and remain future validation.

## Knowledge enumeration

| # | Category | Item | Durable artifact |
|---|---|---|---|
| 1 | Geometry comparison | With matched parameters, the candidate and current Mini tub share a `130.40 × 340.40 × 84.24 mm` envelope and approximately 98.5% volumetric intersection-over-union. | `scad/testbed/basket-carrier-mini-probe.md` |
| 2 | Datum clarification | Center-floor probes put the usable cavity spans within `0.003059 mm`; the older `79.30 mm` figure uses a different measurement convention and is not a like-for-like cavity datum. | `scad/testbed/basket-carrier-mini-probe.md` |
| 3 | Interface finding | The removable grid still has `6.370681 mm³` of direct intersection after a `0.01 mm` lift, exposing unresolved zero-clearance XY boundaries that need an intentional clearance contract. | `scad/testbed/basket-carrier-mini-probe.md` |
| 4 | Product direction | The candidate should remain a parallel experimental Basket/Carrier module until physical fit, handling, and removable-grid behavior are validated. | `scad/testbed/basket-carrier-mini-probe.md` |
| 5 | Reproduction pattern | Vendoring the pinned upstream source and rendering the plain candidate through the adapter produces a mesh identical to the directly rendered pinned source. | `scad/gridfinity/vendor/basket/VENDOR.md`; `scad/testbed/build-basket-carrier-mini-probe.sh` |

## V&V

Planned acceptance criteria came from issue #26's “Acceptance for this slice” section and its pre-implementation first execution slice.

Verification:

- The pinned upstream source and MIT license match the recorded upstream revision byte-for-byte.
- `bash -n scad/testbed/build-basket-carrier-mini-probe.sh` passed.
- `scad/testbed/build-basket-carrier-mini-probe.sh` rendered every comparison artifact and ended with `Verification gates passed`.
- The build asserted the matched Mini envelope, cavity floors, stack witness, casing witness, magnet variants, removable-grid evidence, and a non-Mini parameter smoke case.
- `git diff --check` and the staged diff check passed.
- A public-safety scan found no personal names, local paths, private-repository references, device context, or provider-specific workflow text.
- An independent Codex review rechecked the corrected cavity comparison and returned PASS.

Validation:

- The CAD slice answers its decision question: preserve the Basket/Carrier candidate as a parallel experiment rather than replacing the current tub.
- The representative Mini evidence is reproducible from source and identifies the removable-grid clearance question instead of hiding it.
- Physical printing was outside the authorized slice, so issue #26 remains open for that validation and any later adoption decision.

Post-hoc audit:

- PR #27 merged into `main` as `d15d1f0806f62351136273b246e58979e9da331e`.
- Issue #26 remains open.
- The implementation worktree was clean after merge.
- No printer or live device was contacted.

## Step matrix

✅ Upstream provenance: pinned source, MIT license, and vendor metadata preserved
✅ Candidate source: general parameterized Basket/Carrier probe added
✅ Mode boundary: plain, integral-grid, and removable-grid directions exposed
✅ Comparison evidence: envelope, cavity, magnets, rim, floor, stack, and casing recorded
✅ Reproduction: full OpenSCAD comparison build passed
✅ Public safety: committed surfaces reviewed and clean
✅ Independent review: Codex-only final review passed
✅ PR #27: merged to `main`
⏭️ Issue #26 closure: N/A — physical validation and final adoption remain open
⏭️ Printer/device work: N/A — explicitly outside scope
✅ Wrap log: `log/2026-07-25-wrap-basket-carrier-mini-probe.md`
⏭️ Worktree teardown: external after task exit

## Verdict

Safe to close · ✅ Complete

The authorized CAD-only Mini comparison slice is complete. The broader issue remains open at its explicit physical-validation boundary.

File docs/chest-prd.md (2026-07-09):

---
sensitivity: public
version: 1.4.0
---

# Hutchfinity Chest PRD

**Audience:** agents and contributors drafting the Hutchfinity chest SCAD modules. Read this before designing or modifying `tub.scad`, `casing.scad`, `knob.scad`, or `peg.scad`.

This is a PRD, not a build guide. It captures the product contract for the modular drawer chest architecture. Implementation details that are still under physical validation are called out as open dependencies, not silently decided here.

## What you're building

Hutchfinity is a parametric, modular drawer chest system built around Gridfinity Extended at half pitch: 21mm XY and 3.5mm Z by default.

The system has four authored SCAD parts plus the underlying grid library:

| Part | Role |
|---|---|
| `tub.scad` | Drawer pan. Parametric on grid cell count and pitch. Slides in and out of a casing. |
| `casing.scad` | One-slot enclosure: back, sides, and top only. No bottom and no front. Stacks vertically. |
| `knob.scad` | Optional glue-on pull for the tub front. Kept separate so tubs remain backward-compatible. |
| `peg.scad` | Press-fit dowel that registers and retains vertically stacked casings. |
| Gridfinity Extended | Source geometry for half-pitch grid conventions and tub/bin compatibility. |

A single drawer slot is one tub plus one casing, with an optional knob. Chests gain height by stacking casing modules vertically, not by adding a `drawer_count` parameter to one monolithic model.

## Hard requirements

| # | Requirement | Rationale |
|---|---|---|
| HR-1 | **One drawer slot is one module.** The module consists of one tub plus one casing; knob is optional. | Keeps the system composable. Users can print, replace, and rearrange one slot at a time. |
| HR-2 | **Multiplicity comes from stacking, not a drawer-count parameter.** | A single parametric casing stays simple; tall chests are assemblies, not special-case models. |
| HR-3 | **Casing has back, sides, and top only.** No bottom, no front. | No front means there is an opening for the drawer. No bottom keeps the model simpler to print and lets each drawer ride on the top of the casing below, footer, or tabletop. |
| HR-4 | **Casing prints inverted with the top on the bed.** | Sides and back rise as vertical perimeters; the model should avoid bridges and manual supports. |
| HR-5 | **The bottom-most drawer can ride on a footer or tabletop.** Footer/base behavior is outside `casing.scad`. | Keeps the casing module a single supportless shell while leaving bottom support and robot-vacuum clearance to assembly-level design. |
| HR-6 | **Tub geometry remains compatible with the existing tub catalog.** The lip stays; optional magnet wells and glue-on knob bases must not break stacking or basic tub use. | Hutchfinity should extend tubs into drawers without making every tub a one-off chest-only part. |
| HR-7 | **Sliding interface is tub-on-casing-top.** Each tub rides on the top of the casing below; the bottom tub rides on the footer top or tabletop. | No rails, tracks, or drawer hardware in v1. |
| HR-8 | **Drawers are fully removable.** No pull-out stop in v1. | Clean removal is simpler, easier to print, and easier to inspect. |
| HR-9 | **Pegs register and retain vertical casing stacks.** Side-by-side and multi-column linking are v2. | v1 solves vertical chest assembly first. Lateral assemblies add another fit problem and should not block the single-column chest. |
| HR-10 | **Magnets provide closed retention and an extended-warning detent.** Magnet wells must not protrude into tub storage volume or interfere with mating surfaces. | Drawers should feel intentional in the closed position and warn before accidental over-extension. |
| HR-11 | **Press-fit dimensions are provisional until physical validation lands.** Use the current crush-rib testbed and magnet wiki as the live recipe source. | Trial-01 was PHATTY-process evidence; standard-settings validation is still pending. |
| HR-12 | **All XY dimensions derive from tub cell count and pitch.** | Parametric source stays the contract; manually tuned outer dimensions are drift magnets. |
| HR-13 | **v1 is general-purpose.** No domain-specific assumptions, labels, colors, storage categories, or workflow content belong in the chest architecture. | This repo is public OSS and the chest is a general organizer system. |
| HR-14 | **Back and side exterior faces stay flat.** No external stack pads, lugs, bosses, ribs, lands, or other protrusions on the casing sides or back. | Flat sides/back keep modules visually clean, easy to place against each other or other objects, and true to the simple shell architecture. Stack registration must be solved without changing the exterior side/back planes. |

## Architecture

### Module stack

Each drawer slot is a casing with a matching tub and optional knob:

```
top casing
  tub rides on top surface of casing below
middle casing
  tub rides on top surface of casing below
bottom casing
  tub rides on footer top or tabletop
footer or tabletop
```

Casings with the same XY footprint stack vertically. Heights may vary as long as the peg/socket pattern and tub clearance remain compatible.

### Casing

The casing is a single-piece inverted print:

- Top face on the build plate.
- Back and side walls print as vertical perimeters.
- Back and side exterior faces remain flat planes.
- No bottom face.
- No front face.
- Peg interface reference points are reserved for vertical stacking; final socket geometry remains testbed-gated and must not add side/back protrusions.
- Magnet wells for the tub above are reserved, but their casing-side orientation is an implementation risk: blind wells opening on the final top surface may conflict with top-on-bed printing. Validate whether they print cleanly as bed-side features, move the wells to an insert/post-process operation, or revise the casing orientation before locking `casing.scad`.

The inverted orientation is part of the product contract. If an implementation requires support material or bridges for the casing shell, it is violating the v1 intent.

### Footer

Footer/base behavior is outside `casing.scad`. The bottom drawer can ride on a tabletop, a future footer, or a future base/riser, but the casing module does not expose footer mode, footer threshold, or robot-vacuum policy parameters.

Default robot-vacuum clearance remains an assembly-level heuristic, not a casing rule. The current design assumption is a robot-vacuum navigation envelope around 450mm: roughly a 350mm round vacuum plus about 50mm of side clearance. Treat that as a heuristic comment in assembly/base design, not a fixed casing standard.

### Tub

The tub is the drawer pan. v1 tub requirements:

- Parametric on grid cell count and pitch.
- Retains the existing lip.
- Can receive optional magnet wells inside the existing foot envelope.
- Can receive an optional glue-on knob base.
- Does not require rails, rollers, or extra slide hardware.
- Remains useful as a tub outside the chest.

The available foot-envelope budget for tub magnets is about 4.75mm Z. The magnet design must not touch the 1.2mm floor above that envelope.

### Knob

The knob is a separate glue-on pull. It uses a broad, thin, flared base so it can be glued to the tub front without making the tub geometry chest-only.

v1 does not require snap-on or fastened knobs. Those can be future variants if glue-on knobs fail in use.

### Pegs

Pegs are mass-printable dowels for vertical casing stacks:

- Press-fit is the v1 target.
- Slip-fit plus glue is rejected for v1 because it gives weaker reversible registration.
- Snap-fit pegs are deferred.
- Pegs register and retain casing-to-casing stacking.
- Side-by-side casing linking is out of scope for v1.
- Compliant male geometry is an explicit exploration path: crush ribs, hollow/concave profiles, star-like polygons, or other shapes that make the peg deform more tolerantly than a solid cylinder.
- Candidate peg shapes should be validated in the print orientation that best preserves lengthwise strength and compliant fit. The current prototype prints laid down, then installs vertically as a stack connector.

Peg dimensions should use the same press-fit discipline as magnets: testbed first, then lock the recipe.

## Magnet and crush-rib requirements

Magnets are optional hardware, but the architecture reserves for them:

| Magnet role | Location | Intended function |
|---|---|---|
| Tub magnet array | Tub foot envelope | Moves with the drawer. |
| Casing closed-position array | Top of casing below | Retains the drawer closed. |
| Casing extended-warning array | Top of casing below, about 75% extended | Gives tactile warning before full removal. |

The current magnet sizes in use are:

| Size | Intended location | Status |
|---|---|---|
| 5x1mm disc | Tub foot wells | Pending standard-settings validation. |
| 6x1.5mm disc | Casing arrays | Tentative PHATTY result exists; standard-settings validation still required. |

Current non-dimensional crush-rib constraints:

| Parameter | Current direction |
|---|---|
| Rib count | 8 axial ribs |
| Rib spacing | 45 degrees |
| Rib pattern | Bore-minus-notch, so plate material protrudes inward |
| Chamfer | 0.3mm lead-in |
| Well depth | Prefer shy over proud; deeper wells are safer than protruding magnets |

Dimensional recipe authority lives in `wiki/magnet-press-fit.md` and the active crush-rib testbed. Do not use the older 3-rib recipe or the old `part OD + 0.1mm` / `part thickness + 0.1mm` dimensions as final chest requirements. Trial-01 showed that PHATTY settings distorted shallow wells and small bores enough to make that recipe unreliable.

## Parameters

| Parameter | Meaning | v1 guidance |
|---|---|---|
| `slot_width`, `slot_depth`, `slot_height` | Casing enclosed slot size | Direct casing inputs. Assembly may derive them from a tub, but `casing.scad` stays tub-agnostic. |
| `side_thickness`, `back_thickness`, `top_thickness` | Casing shell thicknesses | Implementation values TBD; must print cleanly and resist normal drawer use. There is no bottom thickness. |
| `peg_spacing` | Vertical stack reference spacing | Single casing input; peg count is derived by indexing corners and evenly dividing each side. |
| `pitch_xy`, `pitch_z`, `cells_x`, `cells_y`, `cells_z` | Tub/assembly grid sizing | Default 21mm XY and 3.5mm Z remain system conventions, but they are not casing-module arguments. |
| Tub-to-slot clearance | Assembly clearance from tub exterior to casing slot | Assembly/tub-fit concern, not a casing-module argument. |
| `peg_profile`, `peg_diameter`, `peg_clearance` | Peg press-fit recipe | TBD by testbed/prototype; include compliant male profiles, not just solid cylinders. |
| `magnet_small`, `magnet_standard` | Disc magnet sizes | 5x1mm and 6x1.5mm currently available. |
| `magnet_recipe` | Bore, depth, and rib geometry | Provisional until trial-02 standard-settings validation. |
| `detent_position` | Extended-warning magnet position | Assembly/interface value; tune by prototype. |

## Out of scope for v1

| Item | Reason |
|---|---|
| Multi-column chest assembly | Side-by-side casing linking adds lateral registration and tolerance problems. Defer to v2. |
| Snap-fit pegs | Press-fit dowels are the simpler validation path. |
| Pull-out tilt stop | Drawers intentionally come out cleanly in v1. |
| Rail, slide, bearing, or roller hardware | Tub-on-casing-top sliding is the v1 mechanism. |
| External stack lands, pads, bosses, lugs, or ribs on casing sides/back | Violates the flat side/back casing requirement. |
| Domain-specific layouts, labels, colors, or workflows | Hutchfinity is a general-purpose public OSS system. |
| Final magnet and peg press-fit dimensions | Physical validation is still open. |

## Open dependencies

| Dependency | Effect on this PRD |
|---|---|
| Magnet crush-rib trial-02 | Locks or revises the provisional magnet well and rib recipe. |
| Casing-side magnet well printability | Decides whether casing wells can be blind bed-side features, need post-processing/inserts, or require a casing orientation revision. |
| Peg press-fit validation | Locks peg/socket dimensions and peg profile. Shape candidates should include compliant male geometry such as crush ribs, hollow/concave sections, and star-like polygons. |
| Tub XY formula updates | May change casing and array placement if the tub formula changes. |
| License decision | Required before release packaging and external contribution expectations are final. |

## Owner success criteria

System works when all hold:

1. **Single-slot printability.** A casing prints inverted without supports, bridging surprises, or fragile unsupported features.
2. **Drawer fit.** A matching tub slides in and out by hand without binding under ordinary FDM variance.
3. **Drawer retention.** Closed-position magnets hold the tub closed under normal handling but do not make the drawer annoying to open.
4. **Extended warning.** The detent near 75% extension is noticeable before full drawer removal.
5. **Full removal.** The drawer can be removed cleanly without tools.
6. **Vertical stack.** Two or more casings with the same XY footprint stack squarely using pegs.
7. **Footer behavior.** The bottom drawer rides cleanly on a footer or tabletop without needing a special bottom casing.
8. **Tub compatibility.** A tub with optional chest features remains usable as a normal tub and does not lose its lip/stacking behavior.
9. **General-purpose presentation.** The public repo describes a modular organizer system, not a private deployment context.
10. **Validation honesty.** Pending press-fit dimensions stay marked provisional until the physical test data exists.

## Implementation guidance

- Keep authored modules to `tub.scad`, `casing.scad`, `knob.scad`, and `peg.scad`.
- Do not add `drawer_count` to `casing.scad`.
- Keep magnet and peg recipes named and centralized so testbed results can update them without hunting through geometry.
- Keep `casing.scad` tub-agnostic; use `hutchfinity-assembly.scad` for fit previews that place casing beside tubs, knobs, pegs, or future footer/base geometry.
- Put hardcoded heuristic values behind named parameters and comments.
- Render and inspect single-slot prototypes before generating tall assemblies.
- Validate one casing/tub/peg/magnet combination before scaling to multiple heights or footprints.

## Anti-patterns

- Monolithic multi-drawer chest models.
- Hidden bottom plates in the casing.
- Front rails or captured drawer hardware in v1.
- External stack pads, lands, lugs, bosses, or ribs that break flat casing sides/back.
- Stale crush-rib dimensions copied from old issue text after newer trial data exists.
- Public docs that cite private planning sources or domain-specific deployment context.
- Adding lateral multi-column linking while the single-column vertical stack is still unvalidated.

## References

- `README.md` - project overview and public status.
- `wiki/magnet-press-fit.md` - current magnet press-fit recipe and trial status.
- `scad/testbed/trial-log-01.md` - PHATTY-process crush-rib trial data.
- `hutchfinity#2` - chest PRD issue.
- `hutchfinity#7` - crush-rib testbed iteration 2.
- `hutchfinity PR #13` - open draft PR for testbed v1.4.0 and trial-02 scaffold.

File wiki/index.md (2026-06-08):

---
sensitivity: public
---

# Hutchfinity wiki — index

| Page | Description |
|---|---|
| [magnet-press-fit.md](magnet-press-fit.md) | Crush-rib press-fit recipe for 5×1mm and 6×1.5mm disc magnets |

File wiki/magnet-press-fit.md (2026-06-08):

---
type: evergreen
sensitivity: public
version: 1.0.0
---

# Magnet press-fit — crush-rib recipe

Disc magnets in tub foot wells and casing arrays are retained by a crush-rib bore: the nominal bore is slightly undersized relative to the magnet, with inward-protruding ribs that compress on insertion to provide holding force.

**Preference: shy over proud.** Magnets must not protrude above their surface — they would interfere with mating geometry. Err on the side of wells that are slightly too deep over wells that are too shallow.

## Magnet sizes in use

| Size | OD | H | Application |
|---|---|---|---|
| Small | 5mm | 1mm | Tub foot wells |
| Standard | 6mm | 1.5mm | Casing arrays |

## Crush-rib geometry

| Parameter | Value | Notes |
|---|---|---|
| Rib count | 8 | FDM-validated; ≤5 → polygon bore, ≥30 → unprintable at 0.4mm nozzle |
| Rib spacing | 45° | Uniform; 8 × 45° |
| Rib width | 0.8mm | Base chord at bore wall |
| Chamfer | 0.3mm lead-in | 45° cone at well opening; aids centering, must not eat rib engagement depth |
| Rib pattern | Bore-minus-notch | Rib-shaped notches subtracted from bore cylinder; plate material protrudes inward |

The bore-minus-notch approach (subtract rib-notch polygons from the bore, so plate material protrudes) is the correct FDM pattern. Do not subtract ribs from the plate (that makes the bore larger, not smaller).

## Trial-01 results — PHATTY settings (2026-06-07)

Printer: Sovol SV08 MAX. Process: 0.6mm nozzle, 0.59mm layer, 1.4mm line width, 1 wall loop, 1.13 flow ratio. See `scad/testbed/trial-log-01.md` for full profiles.

| Magnet | Protrusion | Result |
|---|---|---|
| 5×1mm | 0.05mm (baseline) | Insertable only |
| 5×1mm | 0.10–0.30mm | Would not insert |
| 6×1.5mm | 0.05–0.20mm | Inserts, pulls out |
| 6×1.5mm | 0.25mm | ✅ Holds |
| 6×1.5mm | 0.30mm | ✅ Holds |

**All 6×1.5mm magnets sat proud** at PHATTY settings — first-layer over-extrusion (1.3× flow) raised the well floor.

**PHATTY is marginal for these features:** 0.59mm layer + 1.4mm width + 1.13 flow = ~2 layers total for a 1.1mm well, coarse bore geometry, reduced effective depth. Results characterize PHATTY settings specifically; standard settings (0.4mm nozzle / 0.2mm layer) are required for clean characterization.

## Tentative recipe (pending standard-settings validation)

| Magnet | Protrusion | WELL_R_ADD | WELL_D_ADD | Status |
|---|---|---|---|---|
| 5×1mm | TBD | TBD | ≥0.50mm | Pending iteration 2 — PHATTY bore too tight to characterize |
| 6×1.5mm | 0.25mm | 0.10mm | ≥0.50mm | Tentative (PHATTY); validate at standard settings |

**WELL_D_ADD must be ≥0.50mm** to ensure magnets sit shy at PHATTY settings. Iteration 1 used 0.10mm, which was insufficient.

## Testbed

`scad/testbed/magnet_crush_rib_testbed.scad` v1.3.0 — 6×2 grid sweeping rib protrusion 0.05–0.30mm for both magnet sizes. Print at target process settings to characterize per-printer recipe.

**Column 0 (0.05mm protrusion) is a zero-engagement baseline**, not a low-friction test: protrusion = WELL_R_ADD → net interference = 0. Useful as a reference for how the bore fits uncompressed.

## Open issues

- hutchfinity#7 — iteration 2: deeper wells, standard settings, 5×1mm bore fix

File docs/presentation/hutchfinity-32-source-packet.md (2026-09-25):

---
sensitivity: public
version: 0.1.1
---

# Hutchfinity deterministic source packet

This packet contains two geometry-authoritative OpenSCAD source renders for issue #32: a square single-slot hero and a portrait single-slot exploded view. Product geometry is frozen to commit `29273ab21605eba859088c18fd1bc50087d86709`. The presentation callers import the authored modules; they do not copy or alter casing, tub, knob, peg, magnet-well, or committed STL geometry.

## Product-truth ledger

| Product truth | Pinned authority | Packet consequence |
|---|---|---|
| One drawer slot is one casing plus one tub; the knob is separate and optional. | `docs/chest-prd.md` HR-1 and the pinned module files | Both scenes contain one casing and one regular tub. This packet includes one separate glue-on knob. |
| The casing has back, sides, and top only—no front and no bottom. | `docs/chest-prd.md` HR-3; `docs/hutchfinity-spec.md` casing contract | The caller imports `hutchfinity_casing()` unchanged. A front or bottom request is a hard reject. |
| The tub rides on the support below and remains fully removable. | `docs/chest-prd.md` HR-5, HR-7, and HR-8 | The hero shows the tub partially extended, with no rails, rollers, captured slide hardware, or pull-out stop. |
| Same-footprint casings stack vertically with pegs. | `docs/chest-prd.md` HR-9; `docs/hutchfinity-spec.md` provisional interfaces | The exploded scene includes all seven pegs derived by the pinned casing position functions. |
| Tubs remain independently usable and retain their lip. | `docs/chest-prd.md` HR-6 | The caller imports the committed lipped regular-tub STL through `hutchfinity_regular_tub()`. |
| Side and back casing exterior planes remain flat. | `docs/chest-prd.md` HR-14 | No external lands, pads, bosses, lugs, or decorative additions are introduced. |
| Current dimensions, arrays, sockets, clearances, and assembly coordinates come from pinned source. | `docs/hutchfinity-spec.md`; pinned SCAD modules | Presentation code transforms whole parts only. It applies no deformation and requires `PRODUCT_SCALE=1`. |
| The product remains pre-1.0 and some physical interfaces remain provisional. | `README.md`; `docs/chest-prd.md` HR-11; `docs/hutchfinity-spec.md`; archived fit observations | Packet readiness is `CONDITIONAL`; these images are concept/prototype source renders, not proof of final physical fit or durability. |

## Scene contract

`single-slot-hero` contains one casing, one regular tub extended 150 mm while still engaged, and one knob in its intended assembled orientation. `single-slot-exploded` contains the same casing, tub, and knob plus seven authoritative pegs. Exploded displacement uses translation only after placing each whole part in its intended installed orientation.

Colors are presentation colors, not semantic masks or product color requirements. The render background is opaque and clean. The PNGs contain no text, arrows, dimensions, legend, labels, or branding.

## Allowed downstream transformations

- Replace the background or environment.
- Change lighting, shadow, photographic finish, and benign surface appearance.
- Apply presentation polish that leaves silhouette, openings, part inventory, dimensions, clearances, interfaces, and relative positions inspectably intact.
- Add exact copy, arrows, labels, dimensions, legends, or branding later with a deterministic compositor outside these source pixels.

## Hard rejects

- Redrawing the product from prose or substituting geometry from outside the pinned commit.
- Adding or deleting parts, a casing front or bottom, rails, rollers, captured slide hardware, a pull-out stop, or a monolithic multi-drawer body.
- Rotating, scaling, deforming, or changing casing/tub geometry, drawer count, openings, clearances, magnet/peg features, or assembly relationships.
- Breaking the casing's flat side or back planes.
- Treating draft or uncommitted geometry as current product source.
- Baking generated text, labels, dimensions, arrows, logos, or exact copy into the source raster.
- Representing a provisional interface as physically proven.

## Reproduction and verification

Use OpenSCAD `2026.09.23`, then run:

```sh
OPENSCAD=openscad ./scripts/render-presentation-packet.sh
python3 ./scripts/test_presentation_packet_negative.py --openscad openscad
```

The renderer exports the exact pinned commit into an owned temporary tree, overlays only the presentation callers, renders both PNGs, and verifies the pin, consumed blobs, exact render-dependency allowlists, scene inventories, geometry summaries, minimum image margins, output dimensions, and output hashes before replacing checked outputs. The negative suite makes real front, bottom, and rail mesh changes and proves each changed geometry summary is rejected. The manifest records camera inputs and resolved camera values, transforms, colors, output digests, image bounds, and the complete consumed-blob ledger.

## Claim boundary

Classification: `CONDITIONAL`.

The packet is mechanically complete for a source-preservation experiment. It does not claim that magnet wells, peg/socket fit, drawer fit at full product scale, glue durability, or proposed future tub floor modes are physically final. It does not authorize an image-model call or publication of a downstream generated result.

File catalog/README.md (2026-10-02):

---
sensitivity: public
version: 1.2.0
---

# Neutral item-class catalog

This directory is the public, item-neutral boundary between Hutchfinity bin geometry and an external inventory system. It contains no item names, locations, production quantities, or production authorization.

## Artifacts

- `bin-skus.json` inventories every tracked bin STL. `build_managed` means the current build script names the output; `tracked_unmanaged` means the STL exists but the current script does not reproduce it. The latter is `stale` and is excluded from selection.
- `item-classes.json` contains the four initial public geometry/handling classes. Null dimensions are unknown, not zero.
- `item-class-map.json` is deterministic generated output. Every current mapping is `PROVISIONAL` and has `physical_fit_state: not_run`.
- `schemas/` contains closed JSON Schemas for item classes, bin SKUs, mappings, physical-fit receipts, demand requests, non-authorizing demand manifests, and each serialized dataset wrapper.

Regenerate and test from the repository root:

```sh
python3 scripts/hutchfinity_catalog.py build-catalog --output catalog/bin-skus.json
python3 scripts/hutchfinity_catalog.py select \
  --catalog catalog/bin-skus.json \
  --classes catalog/item-classes.json \
  --output catalog/item-class-map.json
python3 scripts/hutchfinity_catalog.py validate-maps \
  --catalog catalog/bin-skus.json \
  --classes catalog/item-classes.json \
  --maps catalog/item-class-map.json \
  --receipts-dir catalog/physical-fit-receipts
python3 -m unittest discover -s tests -v
```

Every CLI input and generated output is validated with Draft 2020-12 schemas and format checking. The CLI requires the repository's authoritative class set and catalog, recomputes class bindings, resolves selected SKUs, and hashes the referenced source and artifact files. The source/output hashes are exact SHA-256 values. `source_output_link_state: unverified` is deliberate: an existing STL proves that a render exists, but not that its bytes came from the current source revision. A source-only calculation and an STL bounding box are not physical-fit evidence.

## Acceptance and demand boundary

The same `consume-admission` decision path validates independently admitted lane and physical-fit evidence, accepted mapping claims, and demand handoffs. Real evidence defaults to `catalog/trust/production-admission.json`, a versioned repository-governed contract with `configuration: unconfigured` and empty profiles, lanes, and admissions. There is no enrolled real evidence. Unrun real mappings remain `PROVISIONAL/not_run`.

The trust grant comes from repository governance of the admission registry, **not** the receipt directory, a receipt PASS field, a signer label, or a matching hash. Deployments must protect the installed code and registry from evidence submitters and review registry changes independently of receipt submission. This is a bounded admission contract, not a signature service or a claim that a writable checkout authenticates its own evidence. Configuring production admission requires an independently governed enrollment decision and observed physical evidence; this change performs neither. No CLI argument or environment variable selects an alternative trust root.

Each admission pins receipt identities, paths, digests, exact neutral class revision, SKU, lane, profile identity/revision/content digest, and minimum representative sample count (at least two). Current governed profiles and lanes must exist and match exactly; revoked, stale, unknown, malformed, duplicate, or unconfigured states refuse. Admitted bytes still undergo semantic validation. Both receipts must bind the current source revision and content, selected output bytes, and the same lane/profile tuple. The lane must attest reproduced source/output linkage, both functional checks, all bin/cup representative checks, and output-bound smallest thin-wall, multi-cell, and tallest artifacts. This contract is scoped to bin/cup selection; it does not accept a large-part lane in its place.

Separate class/SKU admissions may share a lane receipt identity only when its path and digest are both identical. Conflicting path or digest bindings for that identity refuse the registry. Physical receipt identities remain unique across admissions, and every admission retains its exact class, SKU, source/output, lane, and profile checks.

Physical-fit v2 records require all six load, quantity, retrieval, adjacency, base-engagement, and handling checks, the exact selected orientation, sufficient samples and quantity, a known class envelope, and recorded uncertainty covering the required upper envelope without exceeding class uncertainty. Tested quantity cannot exceed calculated capacity. Failed, inconclusive, not-run, stale, incomplete, or workaround-dependent evidence refuses. Source-derived failed/inconclusive candidates cannot be accepted. Legacy v1 local receipts retain consistency diagnostics but confer no trust.

Demand validates the same admission again and preserves authority/revision, receipt, lane, and profile provenance. Every manifest carries `production_authorized: false` and `integrated_system_accepted: false`. Component lanes and fit receipts cannot satisfy the separate integrated artifact-set gate. That physical run remains required after both matching component lanes pass; this consumer does not implement or imply integrated acceptance.

## Synthetic controls and reproduction

`catalog/trust/synthetic-admission.json` is an explicitly isolated test authority. Its receipts are fabricated software fixtures, not observations. Profile and functional-artifact digests are test values. The synthetic mapping and demand request under `receipts/` are test inputs; the actual catalog, class set, and generated mappings remain unchanged. Test admission cannot cross into the real scope. Synthetic decisions say `SYNTHETIC_ACCEPTED`; synthetic manifests retain `evidence_scope: synthetic_test_only`.

From the repository root, with Python and the declared `jsonschema` dependency:

```sh
export PYTHONDONTWRITEBYTECODE=1
# Default real root: exit 2, unconfigured.
python3 scripts/hutchfinity_catalog.py consume-admission --admission-id synthetic-pair-v1
# Same consumer with isolated test enrollment: exit 0.
python3 scripts/hutchfinity_catalog.py consume-admission \
  --evidence-scope synthetic_test_only --admission-id synthetic-pair-v1
# Compatibility alias for the same synthetic consumer.
python3 scripts/hutchfinity_catalog.py consume-synthetic-admission
# Unknown test admission: exit 2.
python3 scripts/hutchfinity_catalog.py consume-admission \
  --evidence-scope synthetic_test_only --admission-id caller-created-pair
# Non-authorizing, synthetic-only demand; writes only a temporary output.
python3 scripts/hutchfinity_catalog.py build-demand \
  --catalog catalog/bin-skus.json --classes catalog/item-classes.json \
  --maps catalog/receipts/synthetic-maps.json \
  --request catalog/receipts/synthetic-demand-request.json \
  --receipts-dir catalog/receipts --evidence-scope synthetic_test_only \
  --output /tmp/hutchfinity-synthetic-demand.json
python3 -m unittest discover -s tests -p 'test_hutchfinity_catalog.py' -v
git diff --check
```

The suite copies the consumer and catalog into an isolated test checkout. It exercises both unadmitted caller changes and deliberately test-enrolled invalid evidence with matching admission digests, proving semantic refusals beyond the hash guard. A second admitted class/SKU pair checks generality and minimum-quantity semantics. Jointly enrolled class/SKU admissions also exercise consumption and combined demand through one exact shared lane receipt, with conflicting path/digest and reused physical receipt controls. No test configures real admission or creates purported real physical receipts.

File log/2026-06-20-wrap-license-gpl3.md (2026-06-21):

---
sensitivity: public
date: 2026-06-20
branch: codex/license-gpl3
pr: https://github.com/karyandrew/hutchfinity/pull/16
issue: https://github.com/karyandrew/hutchfinity/issues/1
---

# Wrap: GPLv3 License

## Summary

Resolved the repository license decision by adding GNU GPL v3.0 license text at the project root and documenting third-party license notices for the vendored Gridfinity Extended OpenSCAD source. The README now advertises the license and current upstream dependency accurately, and the vendor note no longer contains stale private-repo wording. PR #16 closes issue #1.

## Knowledge enumeration

| # | Category | Item | Durable artifact |
|---|---|---|---|
| 1 | License/source gotcha | The vendored Gridfinity Extended directory has repo-level GPLv3 text while some embedded utility snippets retain LGPL-3.0 notices; the project notice should preserve both instead of flattening them into one claim. | `THIRD_PARTY_NOTICES.md` |
| 2 | Public-safety cleanup | `VENDOR.md` contained stale private-repo wording adjacent to public license guidance. | `scad/gridfinity/vendor/extended/VENDOR.md` |

## V&V

Verification ran against the branch diff and PR metadata:

- `git diff --check` passed.
- Changed public docs were scanned for local paths, private-repo references, and domain-specific leakage.
- PR #16 was confirmed open, mergeable, non-draft, and linked to close #1.

Validation: Andrew explicitly said `ship it` after reviewing the drafted license change summary.

## Step matrix

✅ Wiki: no new Hutchfinity wiki page needed; license notes live in `THIRD_PARTY_NOTICES.md`
✅ Friction issues filed: none — no separate follow-up needed
⚠️ Friction judge: manual wrap review only — no delegated judge spawned from this Codex session
⚠️ Frontier judge: manual claim verification only — no delegated judge spawned from this Codex session
✅ Wrap log: `log/2026-06-20-wrap-license-gpl3.md` written
✅ Closure comment posted on #1: via PR body `Closes #1`
⏭️ claude-picked removed: N/A — no picked label applied in this session
⏭️ Family pickup: N/A — no absorbed sibling issues
✅ PR #16 — Add GPLv3 license merged → main
✅ Main clone fast-forwarded: Hutchfinity main clone updated after merge
✅ next-N follow-ups: none — scope complete
⏭️ Kickoff marker wiped: N/A — Codex worktree session; teardown is external

## Verdict

✅ Safe to close

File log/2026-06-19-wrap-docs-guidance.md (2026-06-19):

---
type: log
sensitivity: public
date: 2026-06-19
session: docs-guidance
---

# Wrap - docs-guidance - 2026-06-19

## Summary

Completed a public-safe repository-readiness cleanup for Hutchfinity. Added concise agent guidance, simplified Claude-specific repository instructions, and appended a short README map for the directories that were safe to advertise from the project overview. Geometry, generated models, license policy, and issue frontmatter were left untouched. The README map intentionally does not advertise directories that need a separate public-safety review before being promoted from the project overview.

## Knowledge enumeration

| # | Category | Item | Artifact |
|---|---|---|---|
| 1 | public-safety pattern | Repository maps should only advertise directories whose contents are safe to surface from a public overview. | README map includes only vetted directories. |
| 2 | agent guidance | Public repo guidance should apply to files, branch names, commit messages, and PR text, not just source files. | `AGENTS.md` and `CLAUDE.md` encode the rule. |
| 3 | workflow friction | Tooling and session-flow frictions found during wrap were filed to the workflow tracker. | Friction judge filed 5 issues. |

## V&V

Verification: refreshed branch state, checked the changed-file set, ran `git diff --check`, scanned added public text for unsafe local or domain-specific strings, opened PR #15, and captured an evidence package for the wrap breaker. The breaker initially failed because it could not access the target repository or PR from its sandbox; after evidence capture, the breaker verified the branch, PR, changed files, public-safety posture, and no-geometry/no-license scope.

Validation: user directed wrap after the local commit and explicitly approved the external wrap judges plus issue filing. The final breaker review returned PASS with no blocker or major findings.
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

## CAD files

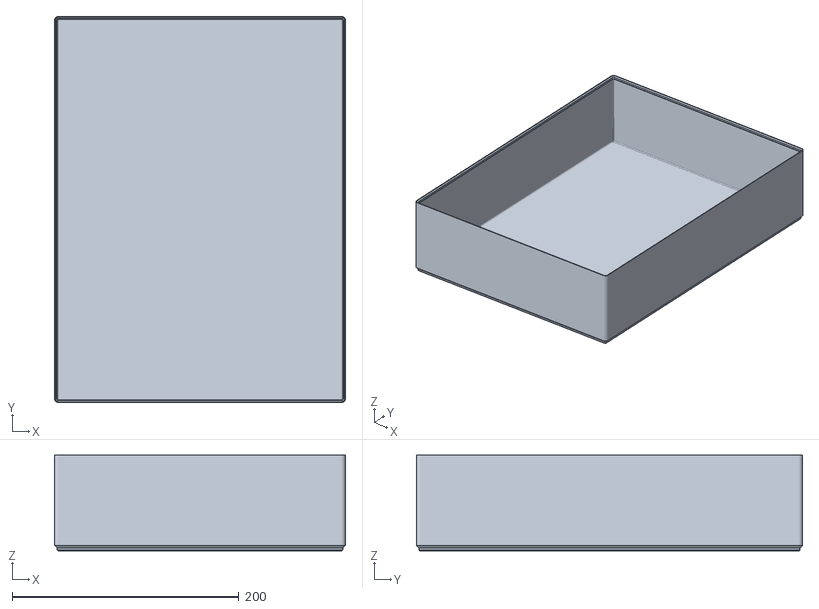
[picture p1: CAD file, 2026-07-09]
scad/gridfinity/stl/tub-regular.stl
256.4 x 340.4 x 84.2

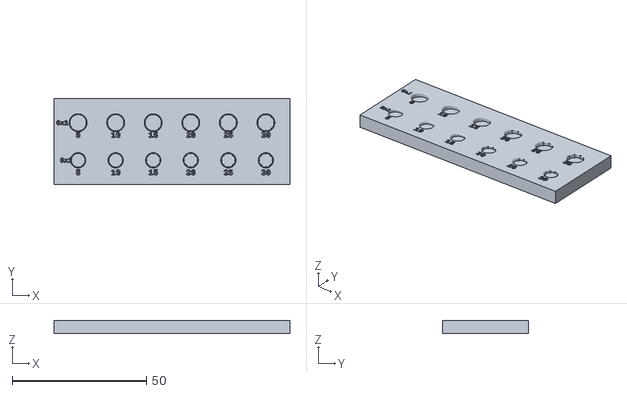
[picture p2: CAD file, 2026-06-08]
scad/testbed/magnet_crush_rib_testbed.stl
88.0 x 32.0 x 5.00

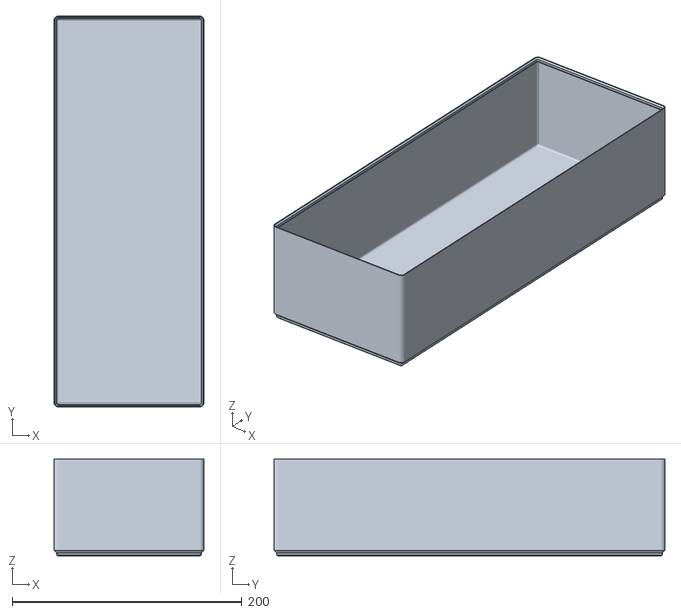
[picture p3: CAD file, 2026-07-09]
scad/gridfinity/stl/tub-mini.stl
130.4 x 340.4 x 84.2

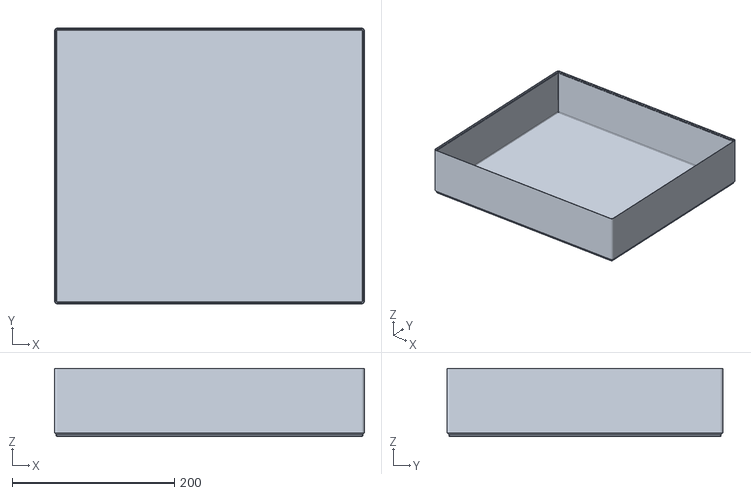
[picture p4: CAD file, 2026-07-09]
scad/gridfinity/stl/tub-mega.stl
382.4 x 340.4 x 84.2

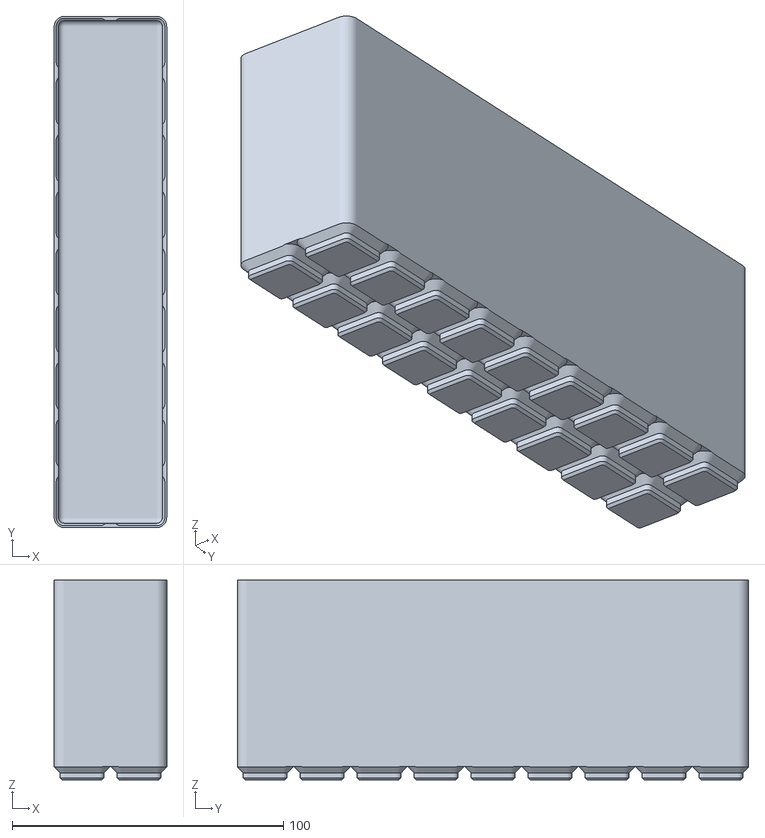
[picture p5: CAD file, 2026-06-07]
scad/gridfinity/stl/bin-2x9x20h.stl
41.5 x 188.5 x 73.7

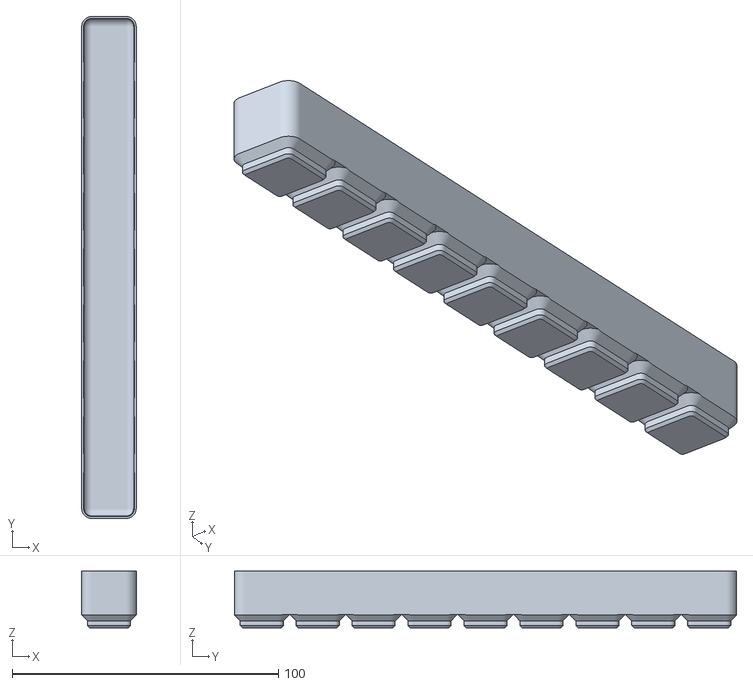
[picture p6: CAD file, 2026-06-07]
scad/gridfinity/stl/bin-1x9x5h.stl
20.5 x 188.5 x 21.2

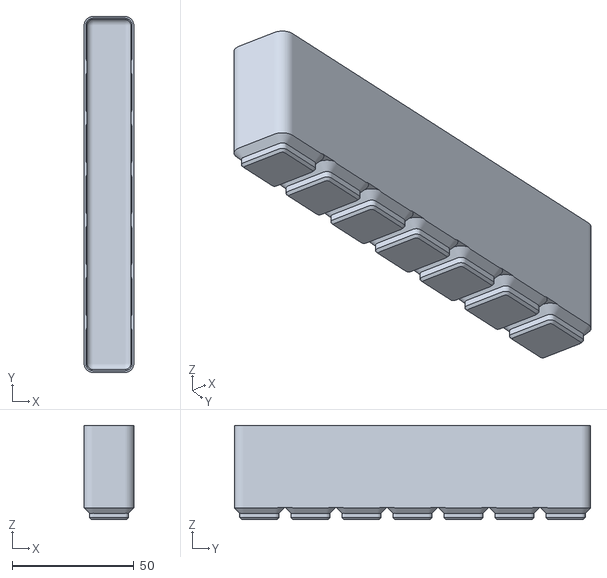
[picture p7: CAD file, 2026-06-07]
scad/gridfinity/stl/bin-1x7x10h.stl
20.5 x 146.5 x 38.7

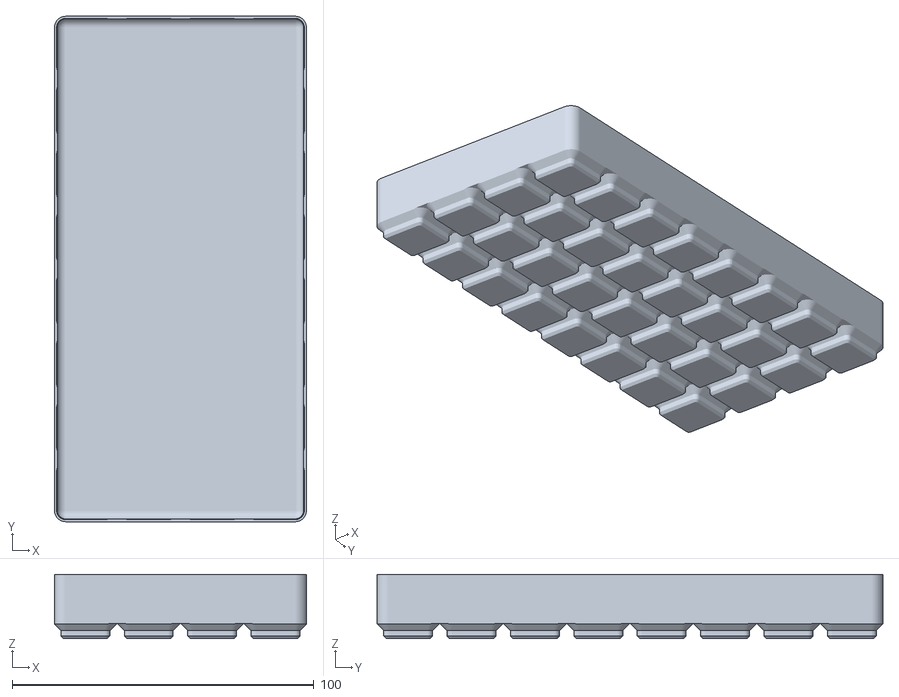
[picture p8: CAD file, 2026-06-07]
scad/gridfinity/stl/bin-4x8x5h.stl
83.5 x 167.5 x 21.2

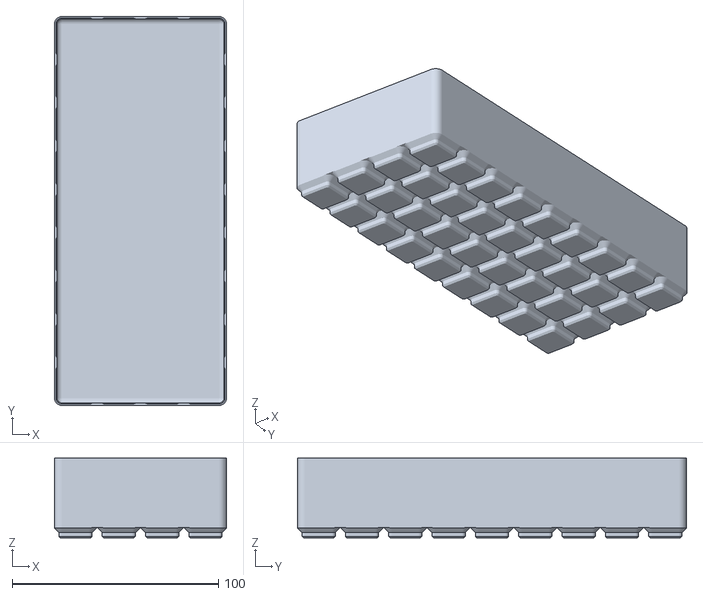
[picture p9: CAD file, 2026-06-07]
scad/gridfinity/stl/bin-4x9x10h.stl
83.5 x 188.5 x 38.7

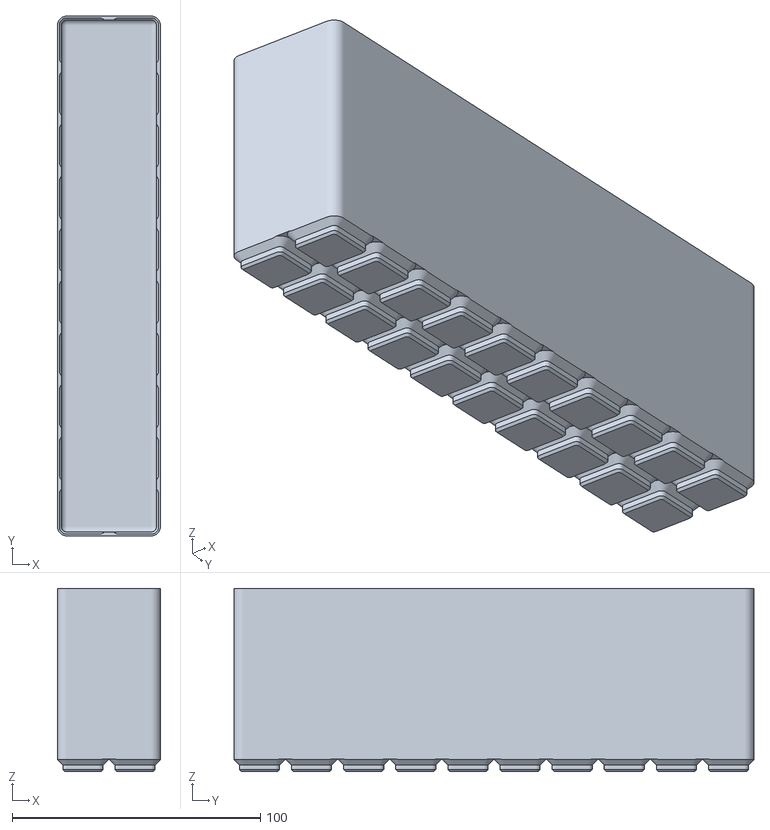
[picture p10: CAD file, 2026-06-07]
scad/gridfinity/stl/bin-2x10x20h.stl
41.5 x 209.5 x 73.7

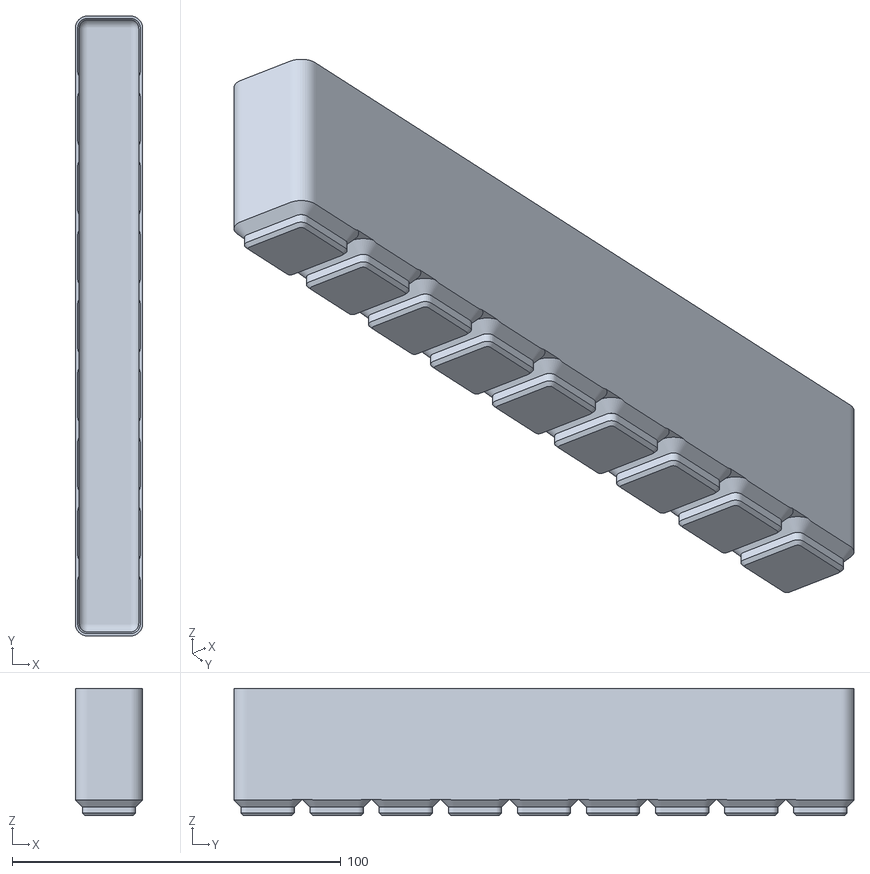
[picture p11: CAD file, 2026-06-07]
scad/gridfinity/stl/bin-1x9x10h.stl
20.5 x 188.5 x 38.7

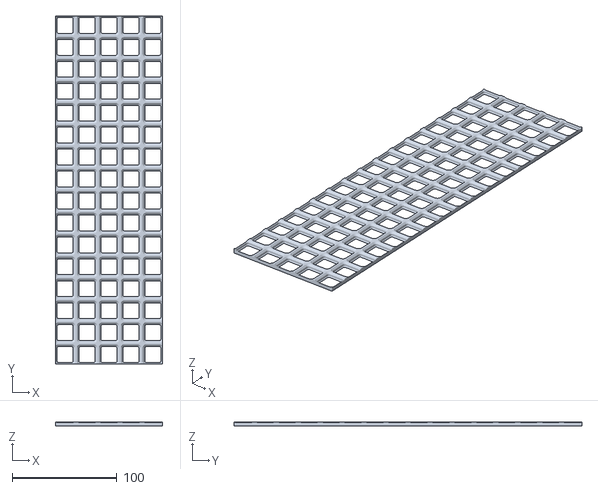
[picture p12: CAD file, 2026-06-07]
scad/gridfinity/stl/baseplate-mini-cropped.stl
102.0 x 333.0 x 4.00

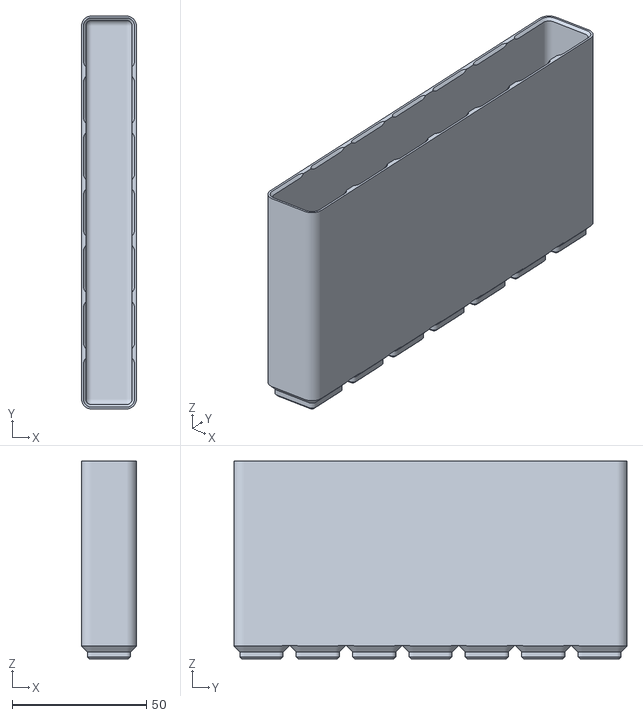
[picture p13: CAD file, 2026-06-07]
scad/gridfinity/stl/bin-1x7x20h.stl
20.5 x 146.5 x 73.7

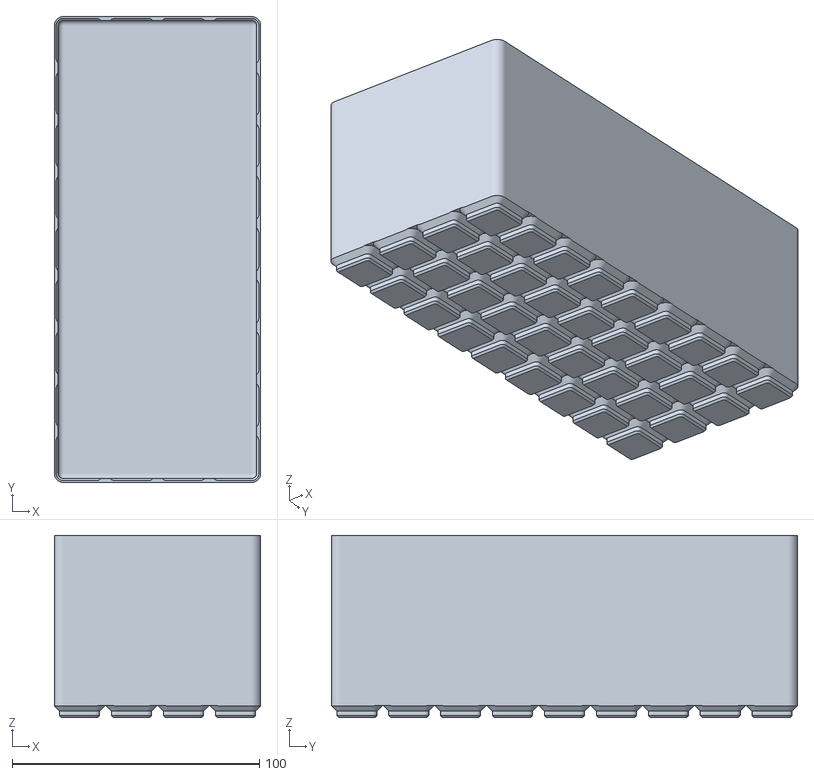
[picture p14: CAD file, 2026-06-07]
scad/gridfinity/stl/bin-4x9x20h.stl
83.5 x 188.5 x 73.7

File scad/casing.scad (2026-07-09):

// casing.scad
// version: 0.10.6
// First-pass Hutchfinity casing shell. Standalone slot geometry: no tub import,
// no front, no bottom. Installed-top and installed-bottom peg sockets are cut
// into the flat side/back wall footprints by default. Casing magnet wells are
// cut into the installed top surface for closed retention and an extended-warning
// detent.

use <magnet_well.scad>;

$fn = 64;
EPS = 0.01;

// Representative first-pass parameters. These describe the casing slot directly;
// hutchfinity-assembly.scad is responsible for choosing values that match a tub.
// Current default uses the tub's shared 16-cell front-to-back dimension as
// drawer travel depth; casing width follows tub width.
// The default height tracks the current 23h tub source total: 23 * 3.5 + 3.74.
SLOT_WIDTH = 256.4;
SLOT_DEPTH = 340.4;
SLOT_HEIGHT = 84.24;
SIDE_THICKNESS = 25;
BACK_THICKNESS = 25;
TOP_THICKNESS = 10;
PEG_SPACING = 190.0;
PEG_DIAMETER = 8.0;
PEG_CLEARANCE = 0.45;
PEG_SOCKET_DEPTH = TOP_THICKNESS;
PEG_CHAMFER = 2.5;
PEG_SOCKET_EDGE_LAND = 4.0;
ENABLE_PEG_HOLES = true;
ENABLE_MAGNET_HOLES = true;
CASING_MAGNET_BORE_DIAMETER = 6.40;
CASING_MAGNET_RIB_TIP_DIAMETER = 6.10;
CASING_MAGNET_WELL_DEPTH = 1.60;
CASING_MAGNET_CHAMFER = 0.30;
CASING_MAGNET_FORE_AFT_INSET = 8.0;
CASING_MAGNET_PARAMEDIAN_OFFSET = 21.0;
EXTENDED_WARNING_TRAVEL_FRACTION = 0.75;
SHOW_DEBUG_MARKERS = false;

DEBUG_MARKER_D = 3.0;

function casing_outer_x(slot_width, side_thickness) = slot_width + 2 * side_thickness;
function casing_outer_y(slot_depth, back_thickness) = slot_depth + back_thickness;
function casing_print_z(slot_height, top_thickness) = top_thickness + slot_height;
function peg_socket_diameter(peg_diameter, peg_clearance) = peg_diameter + peg_clearance;
function peg_socket_opening_radius(peg_diameter, peg_clearance, peg_chamfer) =
    peg_socket_diameter(peg_diameter, peg_clearance) / 2 + peg_chamfer;
function peg_socket_inset(peg_diameter, peg_clearance, peg_chamfer, edge_land=PEG_SOCKET_EDGE_LAND) =
    peg_socket_opening_radius(peg_diameter, peg_clearance, peg_chamfer) + edge_land;
function peg_socket_end_inset(side_thickness, back_thickness, peg_diameter, peg_clearance, peg_chamfer, edge_land) =
    max(
        max(side_thickness, back_thickness),
        peg_socket_inset(peg_diameter, peg_clearance, peg_chamfer, edge_land)
    );

// Peg reference points are derived from one spacing target. Centers sit on the
// side/back wall centerlines so stack sockets do not require exterior lands.
function peg_axis_intervals_between(start, end, peg_spacing) =
    max(1, ceil((end - start) / peg_spacing));
function peg_axis_positions_between(start, end, peg_spacing) =
    let(intervals = peg_axis_intervals_between(start, end, peg_spacing), usable = end - start)
    [for (i = [0 : intervals]) start + i * usable / intervals];
function peg_axis_middle_positions_between(start, end, peg_spacing) =
    let(intervals = peg_axis_intervals_between(start, end, peg_spacing), usable = end - start)
    intervals <= 1 ? [] : [for (i = [1 : intervals - 1]) start + i * usable / intervals];
function peg_side_y_positions(depth, peg_spacing, end_inset) =
    peg_axis_positions_between(end_inset, depth - end_inset, peg_spacing);
function peg_back_x_positions(width, peg_spacing, end_inset) =
    peg_axis_middle_positions_between(end_inset, width - end_inset, peg_spacing);
function peg_reference_positions(width, depth, side_thickness, back_thickness, peg_spacing, end_inset) = concat(
    [for (y = peg_side_y_positions(depth, peg_spacing, end_inset))
        [side_thickness / 2, y]],
    [for (y = peg_side_y_positions(depth, peg_spacing, end_inset))
        [width - side_thickness / 2, y]],
    [for (x = peg_back_x_positions(width, peg_spacing, end_inset))
        [x, depth - back_thickness / 2]]
);
function peg_count(width, depth, side_thickness, back_thickness, peg_spacing, end_inset) =
    len(peg_reference_positions(width, depth, side_thickness, back_thickness, peg_spacing, end_inset));
function magnet_column_offsets(paramedian_offset) =
    paramedian_offset == 0 ? [0] : [-paramedian_offset, 0, paramedian_offset];
function casing_magnet_x_positions(slot_width, side_thickness, magnet_paramedian_offset) =
    [for (x = magnet_column_offsets(magnet_paramedian_offset))
        side_thickness + slot_width / 2 + x];
function casing_closed_magnet_positions(slot_width, slot_depth, side_thickness, magnet_fore_aft_inset, magnet_paramedian_offset) =
    [for (x = casing_magnet_x_positions(slot_width, side_thickness, magnet_paramedian_offset))
        for (y = [magnet_fore_aft_inset, slot_depth - magnet_fore_aft_inset])
            [x, y]];
function casing_extended_warning_magnet_y(slot_depth, magnet_fore_aft_inset, travel_fraction) =
    slot_depth - magnet_fore_aft_inset - slot_depth * travel_fraction;
function casing_extended_warning_magnet_positions(slot_width, slot_depth, side_thickness, magnet_fore_aft_inset, magnet_paramedian_offset, travel_fraction) =
    [for (x = casing_magnet_x_positions(slot_width, side_thickness, magnet_paramedian_offset))
        [x, casing_extended_warning_magnet_y(slot_depth, magnet_fore_aft_inset, travel_fraction)]];
function casing_magnet_positions(slot_width, slot_depth, side_thickness, magnet_fore_aft_inset, magnet_paramedian_offset, travel_fraction) =
    concat(
        casing_closed_magnet_positions(slot_width, slot_depth, side_thickness, magnet_fore_aft_inset, magnet_paramedian_offset),
        casing_extended_warning_magnet_positions(slot_width, slot_depth, side_thickness, magnet_fore_aft_inset, magnet_paramedian_offset, travel_fraction)
    );

module casing_shell(outer_x, outer_y, print_z, side_thickness, back_thickness, top_thickness) {
    union() {
        // Top slab: bed-facing in print, upper riding surface in installed use.
        cube([outer_x, outer_y, top_thickness]);

        // Side and back walls rise from the top slab in print orientation.
        cube([side_thickness, outer_y, print_z]);
        translate([outer_x - side_thickness, 0, 0]) cube([side_thickness, outer_y, print_z]);
        translate([0, outer_y - back_thickness, 0]) cube([outer_x, back_thickness, print_z]);
    }
}

module chamfered_peg_socket_cut(position, socket_diameter, socket_depth, socket_chamfer, z=0) {
    chamfer = min(socket_chamfer, socket_depth / 2);
    translate([position[0], position[1], z - EPS])
    union() {
        cylinder(d=socket_diameter, h=socket_depth + 2 * EPS);
        cylinder(d1=socket_diameter + 2 * chamfer, d2=socket_diameter, h=chamfer + EPS);
        translate([0, 0, socket_depth - chamfer])
            cylinder(d1=socket_diameter, d2=socket_diameter + 2 * chamfer, h=chamfer + 2 * EPS);
    }
}

module chamfered_peg_socket_cuts(positions, socket_diameter, socket_depth, socket_chamfer) {
    for (p = positions)
        chamfered_peg_socket_cut(p, socket_diameter, socket_depth, socket_chamfer);
}

module chamfered_peg_foot_socket_cuts(positions, socket_diameter, socket_depth, socket_chamfer, print_z) {
    for (p = positions)
        chamfered_peg_socket_cut(
            p,
            socket_diameter,
            socket_depth,
            socket_chamfer,
            print_z - socket_depth
        );
}

module peg_debug_markers(positions) {
    color([0.1, 0.35, 0.9, 0.35])
    for (p = positions)
        translate([p[0], p[1], 0.15]) cylinder(d=DEBUG_MARKER_D, h=0.4);
}
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

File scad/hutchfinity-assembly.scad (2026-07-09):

// hutchfinity-assembly.scad
// version: 0.6.2
// Assembly caller for fit previews. Casing stays tub-agnostic; tub geometry
// belongs here once an authored tub module exists.

use <casing.scad>;
use <tub.scad>;
use <peg.scad>;
use <knob.scad>;

REGULAR_TUB_EXTERIOR_X = 256.4;
REGULAR_TUB_EXTERIOR_Y = 340.4;
REGULAR_TUB_SOURCE_HEIGHT_U = 23;
REGULAR_TUB_MAX_BIN_HEIGHT_U = 20;
PITCH_Z = 3.5;
MINIMUM_LIP_Z = 3.74;
REGULAR_TUB_EXTERIOR_Z = REGULAR_TUB_SOURCE_HEIGHT_U * PITCH_Z + MINIMUM_LIP_Z;
SIDE_CLEARANCE = 1.0;
BACK_CLEARANCE = 0.5;
TOP_CLEARANCE = 1.0;
SHOW_OPTIONAL_PARTS = true;

hutchfinity_casing(
    slot_width=REGULAR_TUB_EXTERIOR_X + 2 * SIDE_CLEARANCE,
    slot_depth=REGULAR_TUB_EXTERIOR_Y + BACK_CLEARANCE,
    slot_height=REGULAR_TUB_EXTERIOR_Z + TOP_CLEARANCE,
    side_thickness=25,
    back_thickness=25,
    top_thickness=10,
    peg_spacing=190,
    casing_magnet_drawer_depth=REGULAR_TUB_EXTERIOR_Y
);

if (SHOW_OPTIONAL_PARTS) {
    translate([0, REGULAR_TUB_EXTERIOR_Y + 70, 0])
        hutchfinity_regular_tub();
    translate([REGULAR_TUB_EXTERIOR_X + 110, 0, 0]) hutchfinity_peg();
    translate([REGULAR_TUB_EXTERIOR_X + 110, 65, 0]) hutchfinity_knob();
}

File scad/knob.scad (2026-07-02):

// Hutchfinity optional glue-on knob prototype.
// Version: 0.2.0

$fn = 64;
EPS = 0.01;

BASE_WIDTH = 90.0;
BASE_DEPTH = 34.0;
BASE_THICKNESS = 2.0;
BASE_CORNER_RADIUS = 5.0;

FLARE_WIDTH = 62.0;
FLARE_DEPTH = 28.0;
FLARE_HEIGHT = 3.0;

NECK_WIDTH = 36.0;
NECK_DEPTH = 18.0;
END_BULGE_WIDTH = 56.0;
END_BULGE_DEPTH = 30.0;
GRIP_HEIGHT = 14.0;
GRIP_CORNER_RADIUS = 6.0;

module rounded_box(size, radius) {
    width = size[0];
    depth = size[1];
    height = size[2];
    linear_extrude(height = height)
        offset(r = radius)
            square([max(width - 2 * radius, EPS), max(depth - 2 * radius, EPS)], center = true);
}

module tapered_slug(bottom_size, top_size, height, radius) {
    hull() {
        translate([0, 0, 0])
            rounded_box([bottom_size[0], bottom_size[1], EPS], min(radius, bottom_size[0] / 2 - EPS, bottom_size[1] / 2 - EPS));
        translate([0, 0, height - EPS])
            rounded_box([top_size[0], top_size[1], EPS], min(radius, top_size[0] / 2 - EPS, top_size[1] / 2 - EPS));
    }
}

module hutchfinity_knob(
    base_width = BASE_WIDTH,
    base_depth = BASE_DEPTH,
    base_thickness = BASE_THICKNESS,
    base_corner_radius = BASE_CORNER_RADIUS,
    flare_width = FLARE_WIDTH,
    flare_depth = FLARE_DEPTH,
    flare_height = FLARE_HEIGHT,
    neck_width = NECK_WIDTH,
    neck_depth = NECK_DEPTH,
    end_bulge_width = END_BULGE_WIDTH,
    end_bulge_depth = END_BULGE_DEPTH,
    grip_height = GRIP_HEIGHT,
    grip_corner_radius = GRIP_CORNER_RADIUS
) {
    assert(base_width > end_bulge_width, "base_width must exceed end_bulge_width for a glue flange");
    assert(base_depth > end_bulge_depth, "base_depth must exceed end_bulge_depth for a glue flange");
    assert(end_bulge_width > neck_width, "end_bulge_width should exceed neck_width");
    assert(end_bulge_depth > neck_depth, "end_bulge_depth should exceed neck_depth");

    union() {
        rounded_box([base_width, base_depth, base_thickness], base_corner_radius);

        translate([0, 0, base_thickness - EPS])
            tapered_slug(
                [flare_width, flare_depth],
                [neck_width, neck_depth],
                flare_height + EPS,
                min(grip_corner_radius, flare_depth / 2 - EPS)
            );

        translate([0, 0, base_thickness + flare_height - EPS])
            tapered_slug(
                [neck_width, neck_depth],
                [end_bulge_width, end_bulge_depth],
                grip_height + EPS,
                grip_corner_radius
            );
    }
}

hutchfinity_knob();

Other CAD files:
scad/gridfinity/stl/bin-5x7x5h.stl
scad/gridfinity/stl/bin-2x10x5h.stl
scad/gridfinity/stl/bin-2x8x20h.stl
scad/gridfinity/stl/bin-2x3x5h.stl
scad/magnet_well.scad
scad/casing-fit-test.scad
scad/gridfinity/stl/baseplate-mega-cropped.stl
scad/gridfinity/stl/baseplate-mini.stl
scad/gridfinity/stl/baseplate-regular-cropped.stl
scad/gridfinity/stl/bin-1x10x10h.stl
scad/gridfinity/stl/bin-1x10x20h.stl
scad/gridfinity/stl/bin-1x10x5h.stl
scad/gridfinity/stl/bin-1x1x10h.stl
scad/gridfinity/stl/bin-1x1x20h.stl
scad/gridfinity/stl/bin-1x1x5h.stl
scad/gridfinity/stl/bin-1x2x10h.stl
scad/gridfinity/stl/bin-1x2x20h.stl
scad/gridfinity/stl/bin-1x2x5h.stl
scad/gridfinity/stl/bin-1x3x10h.stl
scad/gridfinity/stl/bin-1x3x20h.stl
scad/gridfinity/stl/bin-1x3x5h.stl
scad/gridfinity/stl/bin-1x4x10h.stl
scad/gridfinity/stl/bin-1x4x20h.stl
scad/gridfinity/stl/bin-1x4x5h.stl
scad/gridfinity/stl/bin-1x5x10h.stl
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

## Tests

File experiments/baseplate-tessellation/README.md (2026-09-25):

---
sensitivity: public
version: 1.3.0
---

# Baseplate tessellation experiment

This directory contains a baseplate-only experiment. It does not alter the normal tub, bin, or baseplate build and does not establish physical or production fit.

## Effective current control

The pinned combined vendor source declares `fa=6`, `fs=0.1`, and `fn=0`, then assigns those values to `$fa`, `$fs`, and `$fn` before the top-level baseplate call. The pocket chamfers and corner radii in `frame_cavity`, `pad_oversize`, and `outer_baseplate` inherit the special variables. Positive `$fn` overrides the adaptive controls. With `$fn=0`, a full circle uses `ceil(max(min(360/$fa, 2*pi*r/$fs), 5))` fragments, so changing `$fa` alone is not a complete contract: either the angle or segment-length term can be active for a given radius. Some optional/debug helpers force 64 or 128 fragments; the experiment records that they are not evidence of a single global effective value.

## Predeclared matrix and limits

`matrix.tsv` is fixed before render measurement:

| ID | `fn` | `fa` (degrees) | `fs` (mm) |
|---|---:|---:|---:|
| current | 0 | 6 | 0.10 |
| fine | 0 | 8 | 0.15 |
| medium | 0 | 12 | 0.20 |
| coarse | 0 | 16 | 0.30 |

The matrix keeps `fn=0` so both adaptive constraints remain active and varies both limiting inputs. A candidate clears the narrow sampled contact/datum check only when all three classes satisfy:

- component count, watertight edge incidence, consistent orientation, Euler characteristic, and genus unchanged;
- exact overall bounds differ by no more than 0.01mm on any exterior datum;
- observed pocket-wall maximum plus one 0.025mm sample spacing no more than 0.05mm;
- symmetric sampled p99 pocket-wall deviation no more than 0.025mm; and
- no cross-section datum difference over 0.01mm among any pocket placements.

The 0.05mm maximum budget reserves 80% of the nominal 0.25mm per-side foot clearance for manufacturing and process effects. It is a conservative experiment budget, not a claim about printer capability. The 0.025mm p99 limit prevents a candidate from consuming the entire synthetic budget across most of the interface. Sloped and vertical `pad_oversize` pocket walls are isolated by cell-relative extent and inward face orientation, then measured independently of overall bounds. Four fixed cross-sections measure pocket pitch, depth range, opening, and land thickness across every placement. A second diagnostic samples inside every Z slab with no spacing above 0.1mm, and a separately clipped diagnostic samples interface-adjacent horizontal lands. Repetition analysis checks every wall placement by cross-section datums and vertex/centroid surface distance while explicitly leaving exact identity unproved.

The local comparator samples every unique mating-wall edge contour at 0.025mm spacing plus triangle centroids. Adding one spacing to the observed maximum is a conservative diagnostic threshold, not a certified geometric upper bound. The finite horizontal samples and adaptive Z sections improve coverage but do not prove the unsampled continuum or a volumetric minimum wall/land. Consequently `bounded_surface_check_pass` remains false, `surface_acceptance` remains `INCONCLUSIVE`, and volumetric acceptance remains `UNKNOWN` even when the narrower diagnostics pass. A production candidate needs a valid full-surface and volumetric oracle in addition to the physical gate.

## Run

Use an OpenSCAD snapshot compatible with the pinned vendor source and write results outside the repository:

```sh
OUTPUT_DIRECTORY=baseplate-tessellation-run
OPENSCAD_BIN=openscad experiments/baseplate-tessellation/run.sh "$OUTPUT_DIRECTORY"
```

The runner renders Mini, Regular, and Mega for every row from one commit and toolchain, records hashes and mesh audits, then compares each candidate with `current`. It explicitly selects the `Manifold` backend for every row and records that choice in the manifest; `OPENSCAD_BACKEND` may select another backend only for a separate complete run. The output directory must be empty. It exits before producing evidence if OpenSCAD is unavailable, preserves every attempted case and exit code in `cases.tsv`, and does not create `run.json` for an incomplete matrix. Each render defaults to a 900-second limit and each audit/comparison to 300 seconds; override them with `RENDER_TIMEOUT_SECONDS` and `COMPARE_TIMEOUT_SECONDS`. The pinned vendor source requires an OpenSCAD 2023-or-newer snapshot, as recorded in its vendor metadata. `render_seconds` is OpenSCAD's own reported rendering duration; `process_wall_seconds` is a secondary process observation and becomes `null` if the host clock yields an impossible negative value. Timing should be repeated on the same host before drawing performance conclusions.

The comparison reports the observed symmetric contour maximum and p99, plus a clearly named `sampled_max_plus_spacing_diagnostic_mm`. It hashes contact triangulations for diagnostic purposes and measures cross-section datums and sampled geometry across every pocket placement; triangulation hashes may differ when a CSG exporter splits the same surface differently. The stronger topology result also checks orientation, Euler characteristic, and genus. These remain synthetic sampled diagnostics and deliberately do not claim exact repeated-pocket identity, continuous full-surface equivalence, volumetric equivalence, or physical fit.

## Acceptance boundary

Do not copy a matrix row into the production build merely because this experiment passes. Selection requires complete numerical output, review of the representative pocket sections, and the existing representative physical-engagement gate. Production use remains separately gated by the exact artifact and printer/profile validation lane.

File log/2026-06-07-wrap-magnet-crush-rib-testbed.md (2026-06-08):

---
type: log
sensitivity: public
date: 2026-06-07
session: magnet-crush-rib-testbed
issue: hutchfinity#3
pr: hutchfinity#6
---

# Wrap — magnet-crush-rib-testbed — 2026-06-07

## Summary

Built `scad/testbed/magnet_crush_rib_testbed.scad` v1.3.0 — a parametric OpenSCAD testbed for crush-rib press-fit validation for 5×1mm and 6×1.5mm disc magnets, sweeping rib protrusion 0.05–0.30mm in 6 columns. Core geometry uses a bore-minus-notch approach: 8 axial ribs at 45° spacing (FDM-validated from gridfinity-rebuilt-openscad community data), retained by subtracting rib-notch polygons from the bore cylinder. Testbed was printed on the Sovol SV08 MAX with PHATTY settings. Trial-01 results: 5×1mm bores closed by PHATTY over-extrusion (only col 0, zero-engagement baseline, insertable); 6×1.5mm holds at 0.25–0.30mm but all magnets sat proud (WELL_D_ADD too small). Successor issue #7 filed for iteration 2 (deeper wells, standard settings, 5×1mm bore fix). Code review (`/code-review --fix`) applied 7 fixes targeting label positioning, redundant union, stale header comments, $fn reduction, CHAMFER_R assert guard, and col-0 zero-engagement documentation.

## Knowledge enumeration

| # | Category | Item | Artifact |
|---|---|---|---|
| 1 | tool/pattern | PHATTY profile (0.59mm layer, 1.4mm line width, 1 wall loop, 1.13 flow ratio) is unsuitable for features <2mm: bore geometry collapses at small scale; use standard 0.4mm nozzle / 0.2mm layer for characterization | second-brain#2242 |
| 2 | tool/pattern | OpenSCAD `col_label` row-hardcoding pattern: `well_r(0)` vs `well_r(row)` — always use the row parameter, not a literal index, in row-dependent label geometry | second-brain#2243 |
| 3 | tool/pattern | OpenSCAD `union()` is implicit in module bodies — wrapping children in explicit `union()` is a no-op | second-brain#2244 |
| 4 | naming | crush-rib col-0 is a **zero-engagement baseline**: when protrusion == WELL_R_ADD, net interference = 0, not a low-friction test | second-brain#2249 |
| 5 | tool/pattern | WELL_D_ADD ≥ 0.5mm design rule for 6×1.5mm magnets to sit shy with PHATTY settings; first-layer over-extrusion raises well floor | second-brain#2248 |
| 6 | friction | SSH auth failed mid-session to OrcaSlicer host (key mismatch) — operator had to paste profile JSON manually | second-brain#2246 |
| 7 | friction | tmpfs exhausted during STL render loop, cascading into unrelated SSH failures | second-brain#2247 |
| 8 | friction | `/code-review` invoked after commits rather than pre-commit — all 7 fixes landed as a separate commit | second-brain#2245 |

## V&V

**Verification:** SCAD parses without errors in OpenSCAD (confirmed during render); STL exported manifold (`Simple: yes`). Code review ran 8 verifiers (1-vote per candidate): 7 confirmed/plausible findings applied, 1 refuted (rib epsilon into chamfer zone — chamfer subtraction cancels the overlap). Geometry-affecting fix: col_label row hardcoding (labels were shifted for row 1).

**Validation:** N=1 physical print on Sovol SV08 MAX. Trial-01 results recorded in `scad/testbed/trial-log-01.md` and accepted by Andrew. Results characterize the parameter space at PHATTY settings. Design implications documented; successor issue #7 filed for iteration 2. Validation accepted.

## Step matrix

| Step | Status |
|---|---|
| Wiki | ⏭️ N/A — no new wiki pages; hutchfinity has no wiki; knowledge banked as second-brain issues #2242–#2251 |
| Friction issues filed | ✅ second-brain#2242–#2251 — 10 filed, 0 skipped |
| Friction judge | ✅ 10 filed, 0 skipped |
| Opus judge | ✅ 1 finding (v1.2.0 vs v1.3.0 provenance) — addressed with note in trial log |
| Wrap log | ✅ `log/2026-06-07-wrap-magnet-crush-rib-testbed.md` |
| Closure comment on #3 | ✅ posted |
| claude-picked removed from #3 | ✅ |
| Family pickup | ⏭️ N/A — no siblings absorbed at kickoff |
| PR #6 merged | ✅ `claude/magnet-crush-rib-testbed` → `main` |
| Main clone fast-forwarded | ✅ |
| next-N follow-ups | ✅ #7 — Crush-rib testbed iteration 2 |
| Kickoff marker wiped | ✅ (worktree self-teardown) |

## Verdict

✅ Safe to close — scope complete, V&V accepted, Opus judge finding addressed.

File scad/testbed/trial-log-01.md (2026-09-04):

---
sensitivity: public
type: log
date: 2026-06-07
date_modified: 2026-09-04
testbed: magnet_crush_rib_testbed v1.2.0
sources:
  - https://github.com/karyandrew/second-brain/issues/2249
  - magnet_crush_rib_testbed.scad
---

# Crush-rib trial 01 — 2026-06-07

## Setup

| | |
|---|---|
| Printer | Sovol SV08 MAX |
| Process profile | PHATTY MAX 0.6 nozzle - 0.5.0 (see below) |
| Filament profile | Sunlu PETG PHAT MAX - .6 1.1.1 (see below) |
| Testbed | `magnet_crush_rib_testbed.scad` v1.2.0 (v1.3.0 in this PR corrects label positioning, reduces $fn, and adds an assert guard — no well or rib geometry changes; trial data is valid for both) |
| Rib count | 8 @ 45° spacing |
| Chamfer | 0.3mm lead-in |

## Measurement convention — nominal net radial interference

The source parameter `PROTRUSIONS[col]` is the rib-tip protrusion inward from the
nominal well wall. It is not, by itself, the interference against the magnet,
because the well already includes radial clearance:

```text
nominal well radius = magnet radius + WELL_R_ADD
rib-tip radius = nominal well radius - protrusion
nominal net radial interference = protrusion - WELL_R_ADD
```

For this testbed, `WELL_R_ADD = 0.05 mm`. Therefore column 0's `0.05 mm`
protrusion produces **0.00 mm nominal net interference**. It is the
zero-engagement baseline, not a light interference-fit condition. Columns 1–5
produce 0.05–0.25 mm nominal net radial interference.

“Nominal” matters: extrusion width, flow, shrinkage, polygonization, first-layer
behavior, and print orientation can move the printed bore and rib-tip dimensions.
The physical result tests the complete printed system. The derived value below
states the intended geometry so clearance, zero-fit, and true interference are
not conflated.

### Process profile — PHATTY MAX 0.6 nozzle - 0.5.0

```json
{
    "bottom_shell_layers": "2",
    "bottom_surface_pattern": "monotonic",
    "brim_type": "no_brim",
    "detect_thin_wall": "1",
    "elefant_foot_compensation": "1",
    "first_layer_flow_ratio": "1.3",
    "from": "User",
    "infill_direction": "90",
    "infill_wall_overlap": "35%",
    "inherits": "0.30mm Standard @Sovol SV08 MAX 0.6 nozzle",
    "initial_layer_infill_speed": "140",
    "initial_layer_line_width": "1.4",
    "initial_layer_print_height": "0.6",
    "initial_layer_speed": "120",
    "inner_wall_acceleration": "2500",
    "inner_wall_line_width": "1.4",
    "inner_wall_speed": "140",
    "internal_solid_infill_line_width": "1.4",
    "internal_solid_infill_speed": "180",
    "layer_height": "0.59",
    "line_width": "1.2",
    "name": "PHATTY MAX 0.6 nozzle - 0.5.0",
    "outer_wall_acceleration": "1000",
    "outer_wall_line_width": "1.4",
    "print_extruder_id": ["1"],
    "print_extruder_variant": ["Direct Drive Standard"],
    "reduce_crossing_wall": "1",
    "seam_gap": "-0.01",
    "seam_position": "nearest",
    "set_other_flow_ratios": "1",
    "skirt_loops": "0",
    "sparse_infill_density": "28%",
    "sparse_infill_line_width": "0.8",
    "sparse_infill_pattern": "tpmsd",
    "sparse_infill_speed": "220",
    "staggered_inner_seams": "1",
    "top_shell_layers": "2",
    "top_shell_thickness": "0",
    "top_surface_line_width": "1.4",
    "top_surface_speed": "120",
    "version": "2.3.2.60",
    "wall_direction": "cw",
    "wall_loops": "1"
}
```

### Filament profile — Sunlu PETG PHAT MAX - .6 1.1.1

```json
{
    "chamber_temperature": ["40"],
    "fan_cooling_layer_time": ["0"],
    "fan_max_speed": ["100"],
    "fan_min_speed": ["25"],
    "filament_extruder_variant": ["Direct Drive Standard"],
    "filament_flow_ratio": ["1.13"],
    "filament_max_volumetric_speed": ["50"],
    "filament_settings_id": ["Sunlu PETG PHAT MAX - .6 1.1.1"],
    "filament_vendor": ["Sunlu"],
    "from": "User",
    "full_fan_speed_layer": ["5"],
    "hot_plate_temp": ["85"],
    "inherits": "Generic PETG @Sovol SV08 MAX",
    "name": "Sunlu PETG PHAT MAX - .6 1.1.1",
    "nozzle_temperature": ["260"],
    "slow_down_layer_time": ["0"],
    "version": "2.3.2.60"
}
```

## Why PHATTY is marginal for this feature

| Setting | Value | Effect on wells |
|---|---|---|
| `layer_height` | 0.59mm | 1.1mm well = ~2 layers total; bore barely resolves |
| `outer_wall_line_width` | 1.4mm | Fat single wall; bore narrower than nominal |
| `wall_loops` | 1 | One perimeter — no redundancy, bore geometry is coarse |
| `filament_flow_ratio` | 1.13 | 13% over-extrusion narrows bore further |
| `first_layer_flow_ratio` | 1.3 | 130% first-layer flow raises well floor, reduces effective depth |
| `slow_down_layer_time` | 0 | No cooling on small features; top layers may fuse |

## Results

### Row A — 5×1mm magnets (nominal well-Ø 5.1mm, well-depth 1.1mm)

| Col | Rib protrusion | Nominal net radial interference | Result |
|---|---:|---:|---|
| 0 | 0.05mm | **0.00mm — zero-engagement baseline** | Inserted (only one that went in) |
| 1 | 0.10mm | 0.05mm | Would not insert |
| 2 | 0.15mm | 0.10mm | Would not insert |
| 3 | 0.20mm | 0.15mm | Would not insert |
| 4 | 0.25mm | 0.20mm | Would not insert |
| 5 | 0.30mm | 0.25mm | Would not insert |

Over-extrusion + coarse layer geometry effectively closed the bore. The nominal
0.1mm bore clearance is insufficient at PHATTY settings — the bore is already
undersize before ribs are considered. The baseline's successful insertion does
not establish that a positive nominal interference fit worked.

### Row B — 6×1.5mm magnets (nominal well-Ø 6.1mm, well-depth 1.6mm)

| Col | Rib protrusion | Nominal net radial interference | Result |
|---|---:|---:|---|
| 0 | 0.05mm | **0.00mm — zero-engagement baseline** | Inserted, pulls right back out |
| 1 | 0.10mm | 0.05mm | Inserted, pulls right back out |
| 2 | 0.15mm | 0.10mm | Inserted, pulls right back out |
| 3 | 0.20mm | 0.15mm | Inserted, pulls right back out |
| 4 | 0.25mm | 0.20mm | ✅ Holds |
| 5 | 0.30mm | 0.25mm | ✅ Holds |

**All 6×1.5mm magnets sit proud of the plate surface.** Effective well depth less
than nominal 1.6mm due to first-layer over-extrusion raising the floor.

**Preference: shy is better than proud** for this use case — magnets in tub foot
wells and casing arrays must not protrude above their surface or they interfere
with mating geometry.

## Design implications for next iteration

1. **Well depth**: increase extra depth from +0.10mm to +0.5mm minimum. Needs
   physical validation at target print settings.

2. **5×1mm bore**: nominal Ø + 0.1mm is insufficient at PHATTY settings. Either:
   (a) increase bore clearance to +0.3–0.4mm for PHATTY, or (b) reprint at
   standard settings (0.4mm nozzle / 0.2mm layer) to characterize rib geometry
   cleanly before adding extrusion-width compensation.

3. **6×1.5mm recipe (tentative)**: 0.25mm rib protrusion, equal to **0.20mm
   nominal net radial interference**, holds at PHATTY. Pending flush/shy well
   depth confirmation and validation at standard settings before locking for
   `casing.scad`.

4. **Print settings for next testbed**: standard (0.4mm nozzle / 0.2mm layer
   height) — PHATTY is too coarse for features this small.

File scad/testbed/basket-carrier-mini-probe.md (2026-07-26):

---
sensitivity: public
type: experiment
date: 2026-07-25
issue: hutchfinity#26
status: CAD probe complete; physical Mini trial pending
---

# Mini Basket/Carrier CAD probe

## Scope

This probe tests whether the pinned Gridfinity Basket source can support a
Hutchfinity Basket/Carrier without replacing the current Tub implementation.
It is a general parameterized testbed instantiated only at Mini size. It does
not add a fifth production module, fan out Regular/Mega variants, change the
Gridfinity system PRD, or claim physical validation.

The reproducible packet is built with:

```bash
scad/testbed/build-basket-carrier-mini-probe.sh
```

Generated STLs and `metrics.tsv` are written under
`preview/issue-26/basket-carrier-mini-probe/`.

## Source and parameter map

The probe retains Gridfinity Basket at pinned revision
`549dc4015e4511daeb7b942de96d2531101701db`. The source and MIT notice are
preserved under `scad/gridfinity/vendor/basket/`; the adapter includes the
unchanged source inside a parameterized testbed module.

The Mini instance uses:

| Parameter | Value |
|---|---:|
| Hutchfinity cells | `6 x 16 x 23` |
| Hutchfinity pitch | `21mm XY / 3.5mm Z` |
| Upstream `GridSize` | `[6, 16, 10.5]` |
| Wall thickness | `2.2mm` |
| Additional floor height | `1.29mm` |
| Standoff | `1.75mm` |
| Top padding | `1.25mm` |
| XY / Z tolerance | `0.50 / 0.25mm` |
| Generator magnet holes | disabled |

The upstream source calculates height in 7mm units. The adapter maps the
current Hutchfinity target explicitly rather than treating `10.5` as an
unexplained constant:

```text
target height = 23 * 3.5 + 3.74 = 84.24mm
upstream Z = (84.24 - 4.4 - 1.29 - 1.75 - 0.25 - (2.2 - 0.4) - 1.25) / 7
           = 10.5
```

The matched `2.2mm` wall exceeds the upstream Customizer's advertised `2.0mm`
range, but the pinned source accepts it and all probe renders are manifold.
A non-catalog `4 x 5 x 12` parameterization smoke render was also manifold at
the expected `88.4 x 109.4 x 45.74mm`, confirming the adapter is not a
Mini-only geometry wrapper.

## Floor contracts

The module boundary exposes three modes:

| Mode | Probe geometry | Result |
|---|---|---|
| `plain` | Solid flat floor, no internal grid | Reproduces the pinned matched mesh. |
| `integral` | Upstream internal Gridfinity pockets | Manifold; same outer envelope. |
| `removable` | Plain floor plus an explicit `126 x 336 x 4mm` removable-grid seat check | Contract defined, but zero-clearance fit remains unresolved. |

`plain` and `removable` intentionally share basket geometry in this slice. The
distinction is the removable mode's requirement to accept the committed Mini
baseplate.

A `1 x 1mm` center-floor intersection probe measures the rendered cavity with
the same endpoints in both meshes:

| Mesh | Center floor Z | Lip-top Z | Center floor-to-lip span |
|---|---:|---:|---:|
| Current Mini | `4.703059mm` | `84.240000mm` | `79.536941mm` |
| Candidate plain | `4.700000mm` | `84.240000mm` | `79.540000mm` |

The candidate is therefore about `0.003059mm` deeper at the center floor, not
materially different at this datum. The PRD's separate nominal `79.30mm`
cavity term uses a different body/floor convention and is not used for this
like-for-like mesh comparison. Both designs use the same nominal
`126 x 336mm` cavity XY.

At exact seating height, the committed `126 x 336 x 4mm` Mini baseplate and
candidate produce `6.370681mm³` of Boolean intersection. Lifting the baseplate
`0.01mm` preserves the same residual, so it is an XY zero-clearance boundary
problem rather than floor-plane contact alone. The residual is thin and spread
across the seat boundary; it is CAD evidence that an explicit clearance/corner
contract is still needed, not a physical binding measurement.

## Magnet and casing datums

Generator magnet holes are disabled. When requested, the probe cuts the same
provisional Hutchfinity tub-side interface used by `tub.scad`:

- six wells at X `-21 / 0 / +21mm` and Y `-162.2 / +162.2mm`;
- `5.40mm` bore and `5.25mm` rib-tip diameter;
- `1.10mm` depth and `0.30mm` chamfer;
- shared `hutchfinity_magnet_well_cuts()` geometry.

The candidate's exact `130.4 x 340.4 x 84.24mm` envelope fits the existing
Mini CAD slot datum of `132.4 x 340.9 x 85.24mm`. The overflow witness contains
only its isolated `1mm³` reference cube, so there is no candidate material
outside that slot after the comparison's `0.01mm` Boolean epsilon. This is a
CAD containment check, not drawer-slide validation.

## Mesh comparison

All figures below come from OpenSCAD `2026.04.26` and the generated
`metrics.tsv`.

| Configuration | Current volume | Candidate volume | Shared | Current-only | Candidate-only | Union | IoU |
|---|---:|---:|---:|---:|---:|---:|---:|
| Both magnet-free | `362496.793898` | `360318.767490` | `358712.075338` | `3784.718559` | `1606.692152` | `364103.486050` | `98.519%` |
| Current magnetic, candidate plain | `362351.516706` | `360318.767490` | `358566.798146` | `3784.718559` | `1751.969344` | `364103.486050` | `98.479%` |
| Both use shared magnet wells | `362351.516706` | `360162.816282` | `358556.123146` | `3795.393560` | `1606.693136` | `363958.209842` | `98.516%` |

The middle row reproduces the issue's original comparison configuration.
The candidate-only volume matches the recorded value within `0.001mm³`; the
shared and current-only figures differ by about `0.4mm³`, within the mesh
Boolean/export variation observed during reproduction.

The shared cutter removes `145.277192mm³` from the current Tub and
`155.951208mm³` from the candidate. The positions and cutter parameters match;
the approximately `10.67mm³` difference comes from the different lower
floor/stacking profiles intersected by those cuts.

## Stack check

The upstream nesting offset is:

```text
84.24 - 1.75 - 0.25 = 82.24mm
```

The two-candidate intersection at that offset is empty. The generated
self-stack witness therefore contains only its isolated `1mm³`, 12-facet
reference cube. This verifies non-interference for the CAD pair; it does not
verify printed stack feel, stability, or retention.

## CAD recommendation

Keep the Basket/Carrier as a parallel experimental candidate for the next
physical gate; do not subsume Tub yet.

The probe is too close to reject: it reproduces the target envelope, reaches
about `98.5%` volumetric IoU, uses authored parametric source, maps the shared
magnet interface, and self-stacks without CAD overlap. It is also too early to
replace Tub: the floor/rim residuals are material, the removable-grid contract
has unresolved zero-clearance boundaries, and no physical Mini trial has
checked casing slide, stack feel, or print behavior.

The final disposition remains gated:

- **Subsume Tub** only if the physical Mini preserves casing fit, stacking,
  ordinary tub use, and the selected floor contract without SKU-specific
  patches.
- **Remain parallel** if the Basket/Carrier options are useful but its floor,
  rim, or removable-grid behavior should not redefine the current Tub.
- **Reject** if resolving fit or print behavior breaks the matched envelope,
  stack datum, or general parameterization.

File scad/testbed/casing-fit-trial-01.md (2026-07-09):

---
sensitivity: public
type: log
date: 2026-07-04
testbed: casing-fit-test v0.4.2, casing.scad v0.10.6, tub.scad v0.2.2, magnet_well.scad v0.1.0, and peg_socket_fit_testbed v0.4.0
status: magnetic print set regenerated with 2.2mm tub walls, 1.0mm side clearance, and 1.0mm top clearance; peg/socket coupon printed 2026-07-08; casing/tub physical validation pending
---

# Casing fit trial 01 — magnetic print set pending physical validation

## Purpose

Validate the representative regular-tub casing interface from hutchfinity#20 without conflating tub-process compensation, casing slot clearance, or peg/socket press-fit.

2026-07-05 correction: the external stack-land casing is no longer the physical target. The PRD now requires flat casing side and back exterior faces, so external stack lands/pads/bosses are invalid even though they move peg holes away from thin edges. `casing.scad` v0.9.0 restores the flat casing and cuts stack sockets into the side/back wall footprints by default.

2026-07-08 correction: the observed `+0.6mm` slicer contour compensation improvement was from printed tubs, not casings. The regenerated casing set uses `25 / 25 / 10mm` side/back/top material, `1.0mm` side clearance per side, `1.0mm` top clearance, midline/paramedian casing magnet wells, and a `2.2mm` wall regular tub source via `tub.scad` v0.2.2.

2026-07-08 orientation correction: width means left/right across the drawer opening; depth/length means front-to-back drawer travel. The mini/regular/mega casing set varies in width with tub width (`6/12/18` cells), while all three share the `16`-cell front-to-back tub length.

2026-07-09 magnet alignment correction: tub bottom wells use the same median and paramedian X columns as casing wells, with front/back rows along Y. In the regular aligned assembly, both parts use X columns `133.2 / 154.2 / 175.2mm` and Y rows `8.0 / 332.4mm`.

## Print artifacts

| Artifact | Source | Export command |
|---|---|---|
| Mouth fit gauge | `scad/testbed/casing_mouth_fit_gauge.scad` | `openscad -o preview/casing-fit-trial-01/casing-mouth-fit-gauge.stl scad/testbed/casing_mouth_fit_gauge.scad` |
| Regular 23u casing fit target | `scad/casing-fit-test.scad` | `openscad -o preview/casing-fit-trial-01/casing-fit-regular-23u.stl scad/casing-fit-test.scad` |
| Regular magnetic tub | `scad/tub.scad` | `openscad -o preview/casing-fit-trial-01/tub-regular-magnetic.stl scad/tub.scad` |
| Aligned inspection set | `scad/testbed/full_magnetic_drawer_inspection_set.scad` | `openscad -o preview/casing-fit-trial-01/aligned-inspection/casing-installed.stl -D INSPECTION_PART=1 scad/testbed/full_magnetic_drawer_inspection_set.scad` |
| Magnet-well shape coupon | `scad/testbed/magnet_well_shape_inspection.scad` | `openscad -o preview/casing-fit-trial-01/magnet-well-shape-inspection.stl scad/testbed/magnet_well_shape_inspection.scad` |
| Peg/socket clearance coupon | `scad/testbed/peg_socket_fit_testbed.scad` | `openscad -o preview/casing-fit-trial-01/peg-socket-fit-testbed.stl scad/testbed/peg_socket_fit_testbed.scad` |
| Hex peg set | `scad/testbed/hex_peg_set.scad` | `openscad -o preview/casing-fit-trial-01/hex-peg-set-7.stl scad/testbed/hex_peg_set.scad` |
| Mini/regular/mega magnetic print set | `scad/testbed/mini_regular_mega_print_set.scad` | `scad/testbed/build-mini-regular-mega-print-set.sh` |

## Physical orientation

Print the casing and mouth-gauge artifacts in their OpenSCAD orientation: the top slab is on the build plate and the side/back walls rise upward. In that print view, installed-top sockets open on the bed-facing `Z=0` top slab and installed-bottom receiver sockets open on the wall-foot face at `Z=print_z`. For fit testing, flip the printed part into installed orientation: top slab above the tub, side walls down, open front at the drawer entrance. The upper casing's wall feet sit on the top of the casing below; there is no separate bottom drawer-support part. The tub should sit on a flat reference surface, tabletop, footer, or casing-below surrogate. Testing with the slab underneath the tub is invalid for drawer clearance.

## Design critique before print

| Artifact | What it actually proves | What it does not prove | CAD solid volume |
|---|---|---|---:|
| Mouth fit gauge | Tub can enter the representative width and immediate ceiling height without forced spreading or top rub. | Full-depth sliding friction, back clearance, long-wall bow, stack behavior, peg behavior, or magnetic retention. | Regenerated manifold STL |
| Regular 23u casing fit target | Full-depth slot behavior for the flat-side/back representative casing, including visible stack sockets and nine casing magnet wells. | Final clearance recipe unless tested against a real printed tub and recorded; validated peg/stack or magnet behavior. | Regenerated manifold STL |
| Regular magnetic tub | Bottom magnet-well printability and fit against the casing magnet pattern. | Casing slide behavior by itself; non-regular tub behavior. | Regenerated manifold STL |
| Peg/socket clearance coupon | First-pass insertion/retention feel across three socket clearances. | Actual casing pair behavior: top-slab socket plus wall-foot receiver, full slab stiffness, slicer infill, and stack loading. | Regenerated manifold STL |

The mouth gauge keeps full slot width and height because those are the dimensions being tested; it only reduces drawer-travel depth. Its CAD solid volume is about 21% of the full casing target before slicer infill. If it fails, change `SIDE_CLEARANCE` or `TOP_CLEARANCE` before spending plastic on the full casing.

2026-07-07 critique update: the ribbed peg profile was rejected because the ribs landed on the laid-down contact geometry and did not produce a clean printable/manifold peg. `scad/peg.scad` now uses a plain laid-down hex profile with an 8.45mm point-to-point diameter.

2026-07-05 rejected stack-land update: the side/back wall centerline model was treating the wall strip as the whole receiver, but the external `40 x 50mm` stack-land correction breaks the flat side/back requirement. Keep the lesson, not the geometry: peg sockets need more thoughtful placement without protruding from the casing sides/back.

2026-07-07 peg-print update: the printable peg artifact now lays a plain hex peg on one flat face. Assembly/test-fit semantics still use the peg as a vertical stack connector after printing.

## Pre-print render checks

| Artifact | Render status | Measured STL bounds | Expected bounds | Result |
|---|---|---:|---:|---|
| Mouth fit gauge | Manifold | `308.4 x 48.0 x 95.24mm` | `308.4 x 48.0 x 95.24mm` | Match |
| Regular 23u casing fit target | Manifold with stack sockets and casing magnet wells | `308.4 x 365.9 x 95.24mm` | `308.4 x 365.9 x 95.24mm` | Match |
| Regular magnetic tub | Manifold with bottom magnet wells | `256.395 x 340.397 x 84.24mm` | `256.4 x 340.4 x 84.24mm` | Match within imported STL tessellation |
| Peg/socket clearance coupon | Manifold | `122.0 x 46.225 x 10.6mm` | `122.0 x 46.225 x 10.6mm` including `0.6mm` index marks over `10mm` socket blocks | Match |
| Hex peg set | Manifold, 7 parts | `110.0 x 30.45 x 7.318mm` | `110.0 x 30.45 x 7.318mm` | Match |
| Magnet-well shape coupon | Manifold | `54.0 x 22.0 x 4.0mm` | Two face coupons showing tub and casing well profiles | Match |

### Mini/regular/mega print set

The committed generator is `scad/testbed/mini_regular_mega_print_set.scad`; the
committed packet builder is `scad/testbed/build-mini-regular-mega-print-set.sh`.
It exports the casing, magnetic tub, copied grid baseplate, glue-on knob, and
seven loose hex pegs to `preview/casing-fit-trial-01/mini-regular-mega-print-set/`.

| Artifact | Measured STL bounds |
|---|---:|
| `casing-mini-23u-magnetic.stl` | `182.400 x 365.900 x 95.240mm` |
| `casing-regular-23u-magnetic.stl` | `308.400 x 365.900 x 95.240mm` |
| `casing-mega-23u-magnetic.stl` | `434.400 x 365.900 x 95.240mm` |
| `tub-mini-magnetic.stl` | `130.395 x 340.397 x 84.240mm` |
| `tub-regular-magnetic.stl` | `256.395 x 340.397 x 84.240mm` |
| `tub-mega-magnetic.stl` | `382.395 x 340.397 x 84.240mm` |
| `grid-mini-baseplate.stl` | `126.000 x 336.000 x 4.000mm` |
| `grid-regular-baseplate.stl` | `252.000 x 336.000 x 4.000mm` |
| `grid-mega-baseplate.stl` | `378.000 x 336.000 x 4.000mm` |
| `knob-glue-on.stl` | `90.000 x 34.000 x 19.000mm` |
| `hex-peg-set-7.stl` | `110.000 x 30.450 x 7.318mm` |

The casing and tub front/back dimensions are intentionally constant across the
three sizes. Mini, regular, and mega vary left/right width only.

The peg/socket coupon Y envelope includes loose pegs placed in front of the coupon blocks. Coupon blocks occupy `Y=0..26mm`; laid-down peg centers are at `Y=-16mm`, so the full exported Y envelope is about `-20.225..26mm`. The laid-down pegs reduce the coupon's exported Z envelope from the old upright-peg `20mm` to `10.6mm`.

## Geometry under test

| Value | Trial setting |
|---|---:|
| Tub exterior XY target | `256.4 x 340.4mm` |
| Tub wall thickness | `2.2mm` |
| Casing slot, width x front/back depth x height | `258.4 x 340.9 x 85.24mm` |
| Side/back/top slot clearance | `1.0mm per side / 0.5mm closed back / 1.0mm top` |
| Side wall / back wall / top | `25 / 25 / 10mm` full casing; mouth gauge uses `8mm` back stop |
| Structural thickness change | No casing `+0.6mm`; tub source wall thickness is now `2.2mm` to absorb the printed-tub contour-compensation lesson in CAD. |
| Stack land width / length | Rejected; side/back exterior faces must remain flat |
| Mouth gauge slot depth | `40.0mm` |
| Casing magnet wells | Nine wells: three median/paramedian columns at closed front row, closed rear row, and 75% rear-magnet warning row; 8-rib bore-minus-notch profile, `6.40mm` bore, `6.10mm` rib-tip diameter, `1.60mm` deep, `0.30mm` chamfer |
| Tub magnet wells | Six bottom wells: two front/back rows by three median/paramedian columns; 8-rib bore-minus-notch profile, `5.40mm` bore, `5.25mm` rib-tip diameter, `1.10mm` deep, `0.30mm` chamfer |
| Magnet lateral columns | Median plus `+/-21.0mm` paramedian offsets for optional extra retention |
| Nominal tub-to-slot clearance | `1.0mm` per side, `0.5mm` closed back, `1.0mm` top in CAD |
| Aligned-STL side clearance | Tub is aligned to leave the full `1.0mm` per side clearance in the casing slot. |
| Aligned-STL back clearance | Tub front starts at the open front; the `0.5mm` depth clearance is at the closed back. |
| Aligned-STL top clearance | Tub top sits `1.0mm` below the installed casing ceiling. |
| Peg diameter | `8.45mm` point-to-point hex |
| Peg socket clearances | `0.30`, `0.45`, `0.60mm` around an `8.0mm` nominal socket diameter |
| Peg/socket chamfer | `2.5mm` |
| Peg socket placement | Enabled in `casing.scad` v0.10.4; sockets center in the flat side/back wall footprints |
| Peg profile | Plain laid-down hex peg; no crush ribs |
| Hex peg set count | `7`, matching the representative casing's socket count per stack interface |
| Casing socket faces | Installed-top sockets open on print `Z=0`; installed-bottom wall-foot receivers open on print `Z=print_z` |

## Setup to record

| Field | Value |
|---|---|
| Printer | TBD |
| Material | TBD |
| Nozzle | TBD |
| Layer height | TBD |
| Wall loops | TBD |
| Infill density/pattern | TBD |
| Slicer contour compensation | TBD |
| Elephant-foot compensation | TBD |

## Observations to record

| Check | Result |
|---|---|
| Mouth gauge accepts tub entrance without forced spreading | TBD |
| Mouth gauge top clearance avoids immediate rub | TBD |
| Casing prints inverted without supports | TBD |
| Top riding surface is flat enough for drawer slide | TBD |
| Tub enters slot without forced spreading | TBD |
| Tub slides full depth without binding | TBD |
| Mouth gauge result agrees with full casing mouth behavior | TBD |
| Closed position has acceptable side play | TBD |
| Back clearance is acceptable at full insertion | TBD |
| Top clearance avoids rubbing lip/items | TBD |
| Best peg coupon by insertion force | `0.30mm` and `0.45mm` socket clearances both felt about right; `0.60mm` was loose. |
| Best peg coupon by retention | `0.30mm` and `0.45mm` socket clearances both felt about right; `0.60mm` was loose. |
| Hex peg inserts without shaving or splitting socket walls | TBD |
| Any socket cracking, whitening, or delamination | TBD |
| Peg aligns top-slab socket to wall-foot receiver between two casing artifacts | TBD |
| Tub magnet wells accept 5mm magnets without cracking or loose fall-out | TBD |
| Casing magnet wells accept 6mm magnets without cracking or loose fall-out | TBD |
| Closed magnet alignment and retention are useful | TBD |
| 75% travel warning detent is noticeable without feeling like a hard stop | TBD |
| Tub wall-source CAD fix for the printed `+0.6mm` contour-compensation result | Implemented as `2.2mm` tub walls in CAD; physical print validation pending. |

2026-07-08 peg/socket coupon result: the rightmost coupon, `0.60mm` socket clearance, was loose. The other two inserts, `0.30mm` and `0.45mm`, both felt about right. Keep the current `0.45mm` prototype casing socket clearance unless actual casing-pair stack testing shows it needs the tighter `0.30mm` fit.

## Decision hooks

| Observation | Design response |
|---|---|
| Mouth gauge binds at side walls | Increase `SIDE_CLEARANCE` before spending a full casing print. |
| Tub binds at side walls | Measure printed tub exterior first, then increase `SIDE_CLEARANCE` in `casing-fit-test.scad` if CAD clearance is insufficient. |
| Tub bottoms against back before front is acceptable | Increase `BACK_CLEARANCE`. |
| Tub rubs top surface | Increase `TOP_CLEARANCE` or revisit tested tub height. |
| Tub rattles unacceptably | Keep clearance lower and inspect print/process variance first. |
| No peg coupon has acceptable insertion and retention | Keep peg/socket provisional and move to a peg-profile testbed. |
| Hex peg is too tight or shaves badly | Reduce point-to-point peg diameter, increase socket clearance, or add a dedicated peg-profile sweep. |
| Peg strategy requires external side/back protrusions | Reject the geometry and redesign around flat exterior casing faces. |
| One coupon is clearly best | Confirm against the actual casing sockets before updating prototype `PEG_CLEARANCE`. |
| Tub magnets are loose | Increase the tub bore/tip fit or revisit the 5mm pocket recipe before changing casing magnet positions. |
| Casing magnets are loose | Move from the default 6mm pocket toward the stronger `6mm R20/P20` candidate before changing magnet count. |
| Magnet wells are too tight or split walls | Loosen the bore/tip fit or reduce chamfer before changing the midline/paramedian array layout. |
| Tub source remains weaker than tubs printed with `+0.6mm` contour compensation | Revisit tub wall/pathing source; do not thicken the casing or rely on slicer contour compensation. |

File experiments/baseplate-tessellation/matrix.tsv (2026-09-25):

id | fn | fa | fs
current | 0 | 6 | 0.1
fine | 0 | 8 | 0.15
medium | 0 | 12 | 0.2
coarse | 0 | 16 | 0.3

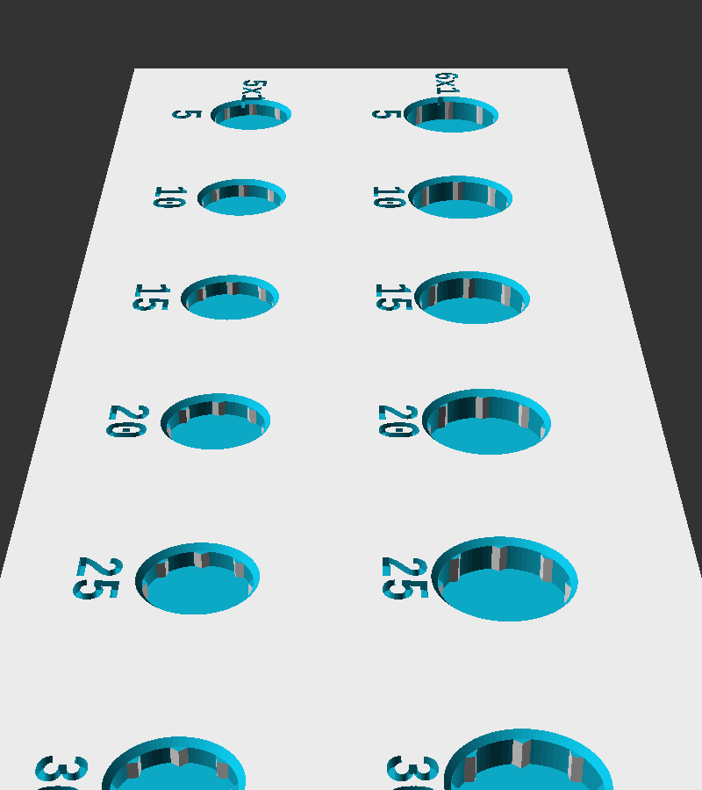
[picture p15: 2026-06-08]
scad/testbed/preview-side.png

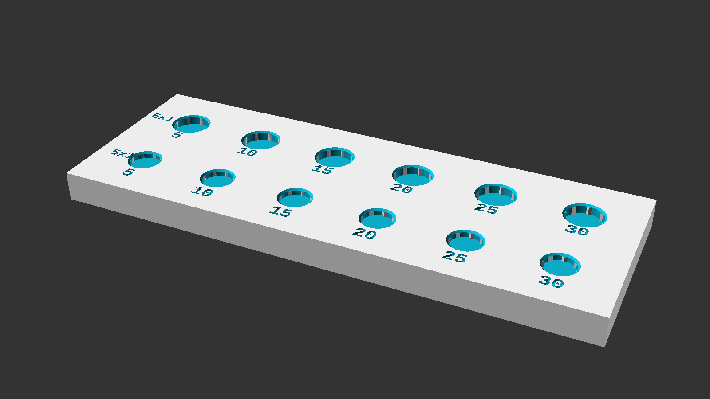
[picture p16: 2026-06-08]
scad/testbed/preview-iso.png

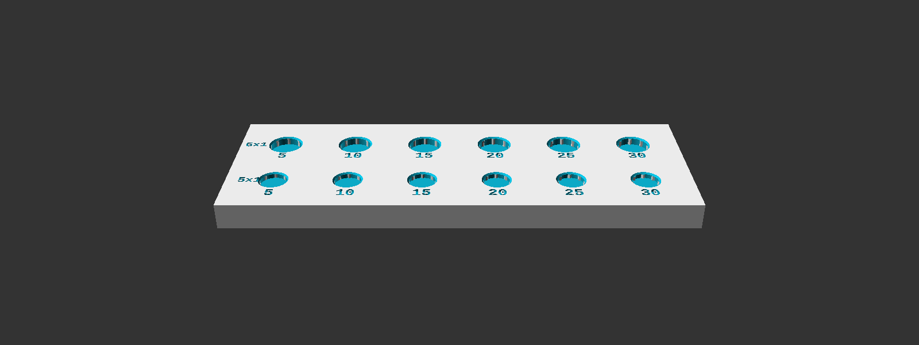
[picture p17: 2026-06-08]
scad/testbed/preview-front.png

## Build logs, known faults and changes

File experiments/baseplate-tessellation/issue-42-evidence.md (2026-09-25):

---
sensitivity: public
version: 1.2.0
---

# Baseplate tessellation investigation evidence

## Result boundary

The unchanged pinned vendor source was rendered for the declared 12-case matrix. The `fine` row passed the predeclared narrow sampled contact, topology, bounds, and cross-section datum checks for Mini, Regular, and Mega. Follow-up comparator diagnostics also cleared for sampled horizontal lands, adaptive Z sections, repeated-pocket samples, and stronger topology invariants. `bounded_surface_check_pass` nevertheless remains false. `fine` is **not accepted as a production contract**: the comparator is not an exact full-surface Hausdorff oracle, no volumetric minimum-wall analysis was performed, and no physical engagement was attempted. The exact-artifact physical gate in issue #37 remains required.

`medium` and `coarse` failed the predeclared contact and functional-datum limits for every artifact. File-size reduction did not override those failures.

## Immutable inputs

- Source commit: `fcd783e7a937c09fb32e1d5e248e91fe3092c481`
- Pinned vendor revision: `8b3a6c570c40ec1501ed61bc958835c06ffb7b8c`
- Pinned vendor source SHA-256: `675d73a6af4fe53d8e4c2de3c700d065698ff29b54f73fa671f6d5beab157fad`
- Current production build script SHA-256: `b081030822c869457d6239b13059f6f949b830f35cc3fcebd4d8db2a7e0fdb39`
- Matrix SHA-256: `b632d308fd2aa5a3be93e09667426285ed4268f27bae43f4846eebf334daae3a`
- OpenSCAD: `2026.09.23`, `x86_64`, explicit `Manifold` backend for all 12 renders
- OpenSCAD command wrapper SHA-256: `a8bd71cc2eb4c8a0d2a42c6735953d97c6f9f57b6e8275c798ad208e3a9191f1`
- OpenSCAD executable SHA-256: `cb643638df94177e50c5c6e2749f986a03395f503b3a0512448f5478ed9c194d`
- Complete run-manifest SHA-256: `b7d11bc9b0bdff7f50091591c49e5dc60891ac66d77c006e5245d31d2c7fdde6`

The manifest records `render_source_matches_vendor: true`; no assertion was disabled and no source substitution or syntax rewrite was used. Raw meshes and the complete manifest remain outside the repository.

## Effective tessellation trace

The active path is the top-level call through `set_environment` → `gridfinity_baseplate` → `baseplate` → `baseplate_regular` → `frame_plain`/`frame_cavity`. The combined source assigns `fa=6`, `fs=0.1`, and `fn=0` to `$fa`, `$fs`, and `$fn` before that call. `frame_cavity` invokes `pad_oversize`; its mating-pocket tapers and radii use inherited-fragment cylinders. `outer_baseplate` also uses inherited-fragment cylinders.

Because `$fn=0`, OpenSCAD derives fragment counts from both `$fa` and `$fs`; `$fa` alone is not the control. The render readback confirmed the exact `fs`, `fa`, and `fn` tuple for every matrix row. Fixed 64/128-fragment assignments exist in debug, optional, and unrelated helper paths, but the regular baseplate render left those paths disabled.

## Predeclared matrix and limits

The matrix was fixed before these renders:

| ID | `fn` | `fa` degrees | `fs` mm |
|---|---:|---:|---:|
| current | 0 | 6 | 0.10 |
| fine | 0 | 8 | 0.15 |
| medium | 0 | 12 | 0.20 |
| coarse | 0 | 16 | 0.30 |

The predeclared limits were: topology and component count preserved; exterior-datum delta at most 0.01mm; the observed contact maximum plus one 0.025mm sample spacing at most 0.05mm; sampled symmetric p99 at most 0.025mm; and functional/cross-section datum delta at most 0.01mm. The maximum-plus-spacing value is a conservative diagnostic, not a proven upper bound. Four cross-sections at Z 0.4, 1.4, 2.7, and 3.5mm measured opening, center, adjacent-pocket land, pitch, and contact depth for every pocket placement.

## Reproducible current baseline

`render_seconds` is OpenSCAD's reported rendering duration. It is a single-run observation, not a performance benchmark.

| Artifact | SHA-256 | Bytes | Facets | Components | Watertight | Bounds mm | Render seconds |
|---|---|---:|---:|---:|---|---|---:|
| Mini | `3e73db9a247e331dac00b8ed3bd12f8a4a08f1916224bea6a59b4fff65f1a058` | 12,747,945 | 49,788 | 1 | yes | `[-63,-168,0]` to `[63,168,4]` | 0.425 |
| Regular | `2a6efe8ee9eed103c07361514c66d14a1d781f2b2d4ac1d46cdbca32162b0f7c` | 25,422,483 | 99,324 | 1 | yes | `[-126,-168,0]` to `[126,168,4]` | 0.665 |
| Mega | `1428ac306badba381ab640b987584cc82319fe858cc9e9d1c2684f449880ce14` | 38,187,081 | 148,860 | 1 | yes | `[-189,-168,0]` to `[189,168,4]` | 0.957 |

The baseline facet counts and bounds match the tracked repository artifacts. Their byte hashes differ because those tracked files do not carry recoverable renderer provenance; only this run is the reproducible experiment baseline.

## Candidate measurements

All candidate meshes were one component and watertight. Reductions are measured against the same-class current baseline.

| Candidate | Artifact | SHA-256 | Bytes | Byte reduction | Facets | Facet reduction | Render seconds |
|---|---|---|---:|---:|---:|---:|---:|
| fine | Mini | `856964e9c2879198317086fceba871012b00b24deecd204b48496c29c89b0b52` | 11,915,398 | 6.53% | 45,884 | 7.84% | 0.326 |
| fine | Regular | `b931f1f9cc9c91c45a76408012cee3be635b222d107c79b09d777c04def8324a` | 23,757,144 | 6.55% | 91,580 | 7.80% | 0.647 |
| fine | Mega | `3b8dda3a7c0205b6ba606934b691df33d21acdf862705c3b91ea4c55a5203ad8` | 35,652,157 | 6.64% | 137,276 | 7.78% | 0.863 |
| medium | Mini | `0d99eb8bbcf1f6b6384853a59e13abada96854a1853624b92ac7c4f6bfbb7f6e` | 6,403,307 | 49.77% | 25,084 | 49.62% | 0.267 |
| medium | Regular | `86d1ef623b66fd249f4d7cfc3078dd04974d222a78ef515a84bf19185f963381` | 12,745,526 | 49.87% | 50,044 | 49.62% | 0.500 |
| medium | Mega | `b83e4ecc495b73cdc0b5f24f59856a46296700d55e63c39c5e1e30285c719505` | 19,131,654 | 49.90% | 75,004 | 49.61% | 0.704 |
| coarse | Mini | `3bc029ec89a762b5a47f9f9688c43eac1a1371afd1d449c1b0d3680d034bd904` | 6,249,485 | 50.98% | 24,292 | 51.21% | 0.289 |
| coarse | Regular | `ae11e421142be5d00a1485a7b9b767b7c0814edf445ed2465d2164aeed037edd` | 12,471,158 | 50.94% | 48,484 | 51.19% | 0.446 |
| coarse | Mega | `069103e0ae648bbd0b01e4932d59bc986da9cee71a7a3f8f78ab0ebb271d652f` | 18,728,921 | 50.95% | 72,676 | 51.18% | 0.688 |

## Sampled contact and functional results

Values were identical across Mini, Regular, and Mega to displayed precision. Placement cross-section datum variation was below `6.4e-14`mm in every baseline/candidate class, so no size-dependent datum corruption was observed by this oracle.

| Candidate | Sampled max mm | Max + spacing diagnostic mm | Symmetric p99 mm | Max functional datum delta mm | Max exterior bound delta mm | Narrow sampled/datum result |
|---|---:|---:|---:|---:|---:|---|
| fine | 0.0173514 | 0.0423514 | 0.0108395 | 0.00913481 | 0.00913481 | clears for all three classes |
| medium | 0.0384015 | 0.0634015 | 0.0384015 | 0.0356625 | 0.0205429 | does not clear for any class |
| coarse | 0.0657476 | 0.0907476 | 0.0452389 | 0.0349277 | 0.0349277 | does not clear for any class |

The baseline adjacent-pocket land widths at the four sections were 5.08, 4.30, 4.08, and 2.48mm. The `fine` section openings/lands differed by no more than the 0.00913481mm aggregate functional-datum limit, preserved the 0–4mm contact-depth range, and had maximum computed pitch error below `1.5e-14`mm. These are cross-section measurements, not a volumetric minimum-wall guarantee.

The original comparator isolates inward-facing, non-horizontal `pad_oversize` walls, samples every unique edge contour at 0.025mm spacing plus triangle centroids for one canonical pocket, and evaluates section datums at every placement. This is actual but finite mating-surface evidence. It remains inconclusive for full-surface equivalence because it is neither an exact Hausdorff computation nor an independently validated volumetric oracle.

### Follow-up comparator diagnostics

The unchanged canonical meshes were reanalyzed without altering the canonical render manifest. The repaired comparator:

- samples horizontal interface-adjacent lands in a clipped pocket-local window;
- samples 45 sections inside every wall Z slab, with no adjacent section spacing above 0.1mm;
- checks every repeated wall placement by fixed-section datums and vertex/centroid distance while retaining `identity_proved: false`; and
- strengthens topology preservation from component/watertight booleans to consistent orientation, Euler characteristic, and genus.

| Candidate | Horizontal sampled max mm | Adaptive-Z sampled datum max mm | Enhanced sampled diagnostics |
|---|---:|---:|---|
| fine | 0.00794120 | 0.00913481 | clears for all three classes |
| medium | 0.0178586 | 0.0381440 | does not clear for any class |
| coarse | 0.0303638 | 0.0349277 | does not clear for any class |

For `fine`, maximum within-row repeated-pocket vertex/centroid deviation was below `7e-10`mm across all placements. This supports “no sampled size-dependent corruption observed,” not exact pocket identity. The full meshes preserve genus 96, 192, and 288 for Mini, Regular, and Mega respectively across every row. These follow-up diagnostics are implementation evidence only: continuous all-Z/full-surface and volumetric equivalence remain unknown.

## Exact checks

| Check | Result |
|---|---|
| Kickoff packet validator | PASS — operator-stated requirement, full body receipt, `comments_state: none`, learned/applied governing records |
| `bash -n experiments/baseplate-tessellation/run.sh` | PASS |
| `PYTHONDONTWRITEBYTECODE=1 python3 -m unittest experiments/baseplate-tessellation/test_mesh_audit.py` | PASS — 9 tests, including known pass/fail comparison, contact partition, horizontal sampling, all-Z spacing, repeated pockets, topology orientation, manifest assembly, and timing rejection |
| Complete matrix | PASS — 12/12 renders and audits; 9/9 comparisons; all exit 0 |
| Enhanced retained-mesh comparison | PASS — 9/9 executed; `fine` clears the enhanced sampled diagnostics, `medium`/`coarse` do not, and all retain `bounded_surface_check_pass: false` |
| Vendor immutability | PASS — render-source hash equals pinned source hash |
| Backend consistency | PASS — explicit Manifold backend for every baseline/candidate render |
| OpenSCAD diagnostics | PASS — all 12 report manifold `Status: NoError`; no assertion was disabled |
| Second clean rerun | PASS — all 12 output hashes matched the first complete run |
| Production build isolation | PASS — production SCAD, STL, and build script are unchanged |

## Acceptance reconciliation

| Criterion | Status | Evidence or residue |
|---|---|---|
| Current baseline records all three classes reproducibly | MET | Version, architecture, backend, source/tool hashes, artifact hashes, bytes, facets, components, watertightness, exact bounds, and render durations are recorded. |
| Effective tessellation control established | MET | Active inherited `$fn/$fa/$fs` path is traced and read back; fixed-fragment exceptions are bounded. |
| Matrix and tolerances declared before selection | MET | Four rows and numerical limits predated the official render run. |
| Accepted candidate preserves topology, datums, and contact surface | PARTIAL | `fine` clears the narrow and enhanced sampled diagnostics, including stronger topology invariants. Full-surface and volumetric equivalence remain unknown, so no candidate is accepted. |
| Baseplate-only build flags explicit; tub/bin fidelity unchanged | PARTIAL | The isolated runner provides an explicit baseplate-only contract. Production flags remain unchanged pending acceptance, so tub/bin behavior is untouched. |
| Measured reductions reported without a precommitted claim | MET | Per-artifact byte, facet, and single-run render measurements are recorded for all candidates. |
| Current documentation records the per-class contract | PARTIAL | The experiment contract and results are current; no candidate has cleared the gates required for a production contract. |
| Representative physical engagement passes and #37 gate remains | NOT MET | No physical operation occurred. Exact-artifact representative engagement and production validation remain in issue #37. |

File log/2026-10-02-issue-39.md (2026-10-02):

# Issue 39 evidence consumer

Delivered the general, fail-closed lane/physical-fit admission consumer in the existing catalog module. Fixed repository-governed registries are separate from evidence submissions. Production admission is explicitly unconfigured with no profiles, lanes, or enrolled evidence. Synthetic admission is isolated, labeled test-only, and runs through the same consumer, mapping validator, and demand builder. Caller-selected paths, signer labels, PASS claims, and matching hashes confer no trust. Registry/code protection and independent enrollment review are prerequisites for any future real deployment; a writable checkout alone is not an authentication mechanism.

Added closed admission, decision, lane, and physical-fit v2 contracts; retained legacy receipt diagnostics. Exact class revision, selected SKU/orientation, current source revision/content, output bytes, current profile identity/revision/digest, lane and receipt identities must match. Admission, profile, and lane revocation/staleness refuse. Both functional checks and all bin/cup representative checks must pass; smallest thin-wall, multi-cell, and tallest representatives must bind exact outputs. Physical evidence requires all six checks, adequate sample count and quantity, complete dimensions and uncertainty coverage, and no workaround. Failed, inconclusive, not-run, stale, unknown, malformed, duplicate, or unconfigured state refuses. Component evidence never satisfies integrated-system acceptance. Decision and demand outputs retain provenance and false production/integrated authorization.

Validation: 22 tests passed with bytecode writes disabled, including baseline catalog/source-revision/CLI regressions. The public CLI negative matrix exercises deliberately synthetic-enrolled invalid evidence with refreshed admission digests: revoked/stale admission, lane and profile; absent/unknown lane or profile; profile revision/digest mismatch; unknown/duplicate/malformed registry; receipt identity/scope mismatch; failed/inconclusive/not-run/stale gates; every missing physical or lane check; non-passing checks; wrong class/revision/SKU/orientation; source revision/content and output identity/digest mismatches; missing/unbound representatives; unverified source/output linkage; insufficient samples, quantity and uncertainty coverage; excess quantity; and workarounds. Separate controls reject caller trust arguments, unknown admissions and unadmitted tampered bytes. A second isolated synthetic class/SKU enrollment proves generality and minimum-quantity enforcement. Synthetic mapping/demand tests prove scope separation and non-authorizing provenance. No real test receipts or real enrollment were created.

Direct CLI checks: actual provisional mappings validate (exit 0); synthetic admission and synthetic demand succeed (exit 0); default real admission and unknown synthetic admission refuse (exit 2). Synthetic demand preserves `production_authorized: false`, `integrated_system_accepted: false`, and test-only scope. Schema definitions validate and `git diff --check` passes. Reproduction commands are in `catalog/README.md`.

Original acceptance remains partial overall. Software consumer and negative controls are implemented. Existing inventory, closed neutral contracts, selection calculations, public boundary, and non-authorizing demand interface are retained. All four actual mappings remain `PROVISIONAL/not_run`; no catalog, class, mapping, geometry, STL, render or printer artifact was changed. The 126-output inventory retains 22 build-managed and 104 unmanaged outputs, and no actual source/output reproduction or physical acceptance is claimed.

Residual gates: independently governed real evidence enrollment; actual current profile/lane functional and representative physical runs; source/output reproduction for exact candidates; representative class samples with quantity/uncertainty and all physical fit/handling checks; resolution of unknown long-rod axes and the flat-object conservative-floor conflict; and the separate integrated artifact-set run after both component lanes pass, including transfer, stack, retrieval and neutral navigation checks. Actual accepted demand, physical completion, production readiness, and full issue closure remain unmet. No publication or issue mutation was performed.

Narrow shared-lane correction: separate class/SKU admissions may reuse a lane receipt identity only with identical path and digest bindings. A conflicting path or digest refuses the registry for either admission. Physical receipt identities remain unique, and all per-admission semantic bindings remain enforced.

Regression validation: 24 tests passed, including the unchanged external negative matrix and original quantity controls. New isolated synthetic controls retain both square-stack and short-roll admissions simultaneously, consume each, and build combined demand with distinct class-fit receipts and one exact lane receipt. They also reject a different lane path containing identical bytes, a different digest at the same lane path, and physical receipt reuse through the public consumer CLI. Combined demand preserves exact class/SKU/quantity/receipt provenance, test-only scope, and false production/integrated authorization. The initial demand regression invocation omitted a required CLI argument; the corrected invocation and full suite pass. Bytecode writes were disabled, temporary fixtures used a designated writable directory, and `git diff --check` passed.

Only consumer, regression tests, catalog documentation, and this log changed. Real trust remains empty and unconfigured; the four actual mappings remain `PROVISIONAL/not_run`. No actual evidence enrollment, geometry or generated-output changes, physical work, commits, publication, or issue mutation occurred. All residual acceptance gates above remain open.

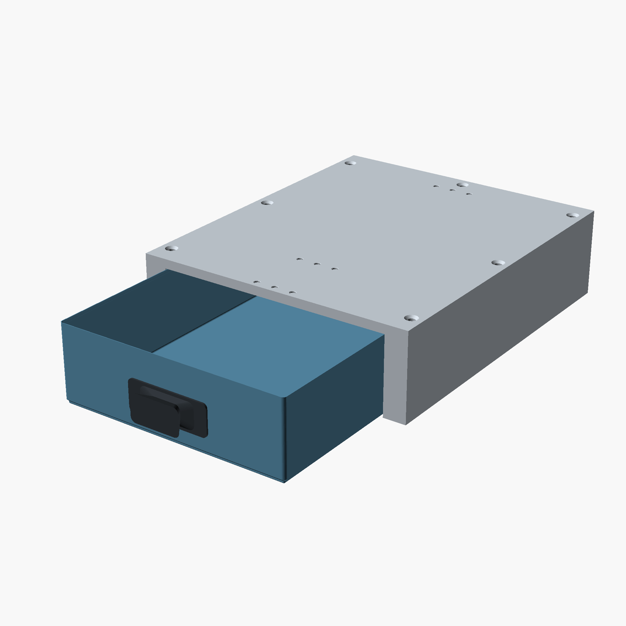
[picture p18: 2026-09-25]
preview/issue-32/single-slot-hero.png

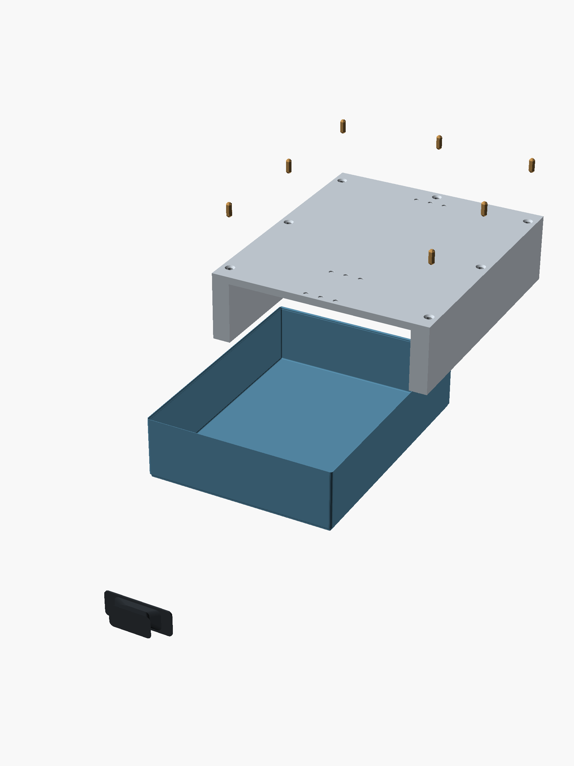
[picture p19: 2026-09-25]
preview/issue-32/single-slot-exploded.png

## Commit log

2026-05-24 Initial commit: bootstrap hutchfinity
    Scaffold the parametric modular drawer chest repo:
    - CLAUDE.md — repo blurb + second-brain inheritance pointer
    - .claude/hooks/ — canonical second-brain inheritance stubs
    - .claude/settings.json — hook registrations + permissions baseline
    - README.md — public-facing project intro, half-pitch principle, gridfinity credit
    - .gitignore — cache, build artifacts, OS noise
    - Scaffold dirs: scad/ docs/ log/ wiki/ adr/
    LICENSE deferred to hutchfinity#1 (will land via follow-up PR).
    Public-repo decision: karyandrew/second-brain ADR 0011.
2026-06-07 Migrate gridfinity design artifacts from karyandrew/3d-printing
    Moved from 3d-printing where they accumulated; hutchfinity is the
    correct home for gridfinity design, STLs, vendor SCAD, and the PRD.
    Added:
    - docs/gridfinity-system-prd.md (system PRD, currently v3.2.0)
    - scad/gridfinity/ (tub/baseplate/bin STLs, vendor extended library,
    dental build script)
    Removed placeholder .gitkeep files from docs/ and scad/.
    [baseplate-mini.stl, bin-1x1x10h.stl, bin-1x1x20h.stl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]
2026-06-07 Add remaining 113 gridfinity STLs migrated from karyandrew/3d-printing
    First migration PR (#4) only captured 28 STLs from the local worktree
    (which was behind origin/main). This commit adds the full catalog:
    bin 1×N, bin N×M variants, and cropped baseplate variants that were
    committed to 3d-printing via batch STL PRs but missed in the initial copy.
    [baseplate-mega-cropped.stl, baseplate-mini-cropped.stl, baseplate-regular-cropped.stl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]
2026-06-08 Add magnet crush-rib testbed SCAD + STL + previews (#3)
    Plate: 88 × 32 × 5mm PETG. 6×2 grid: 6 rib-protrusion levels (0.05–0.30mm)
    × 2 magnet sizes (5×1mm row A, 6×1.5mm row B). 3 axial ribs at 120° spacing,
    bore-minus-notch approach so rib material protrudes inward from bore wall.
    Labels embossed on top face (×100 integer: 5, 10, 15, 20, 25, 30).
    Manifold check: Simple=yes, Volumes=2 (NoError). Rendered at $fn=72.
    Bounding box: 88.0 × 32.0 × 5.0mm.
    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
    [magnet_crush_rib_testbed.scad, magnet_crush_rib_testbed.stl]
2026-06-08 Fix crush-rib testbed: 8 ribs, add lead-in chamfer (v1.1.0)
    3-rib spec was agent-generated without research. Community data from
    gridfinity-rebuilt-openscad: ≤5 ribs produce a polygon bore on FDM;
    8 ribs is the experimentally validated count for disc-magnet wells.
    Also adds 0.6mm lead-in chamfer at well opening for magnet centering.
    Manifold check: Simple=yes. Bounding box unchanged (88×32×5mm).
    [magnet_crush_rib_testbed.scad, magnet_crush_rib_testbed.stl]
2026-06-08 Fix preview camera: center on plate, fill frame
2026-06-08 Fix chamfer depth + rib zone (v1.2.0)
    Chamfer 0.6→0.3mm: was consuming 55% of well depth on 5×1 magnets.
    Rib notches capped at d−CHAMFER_R so ribs don't extend into chamfer zone.
    Engagement depth: 0.8mm (5×1) / 1.3mm (6×1.5).
    [magnet_crush_rib_testbed.scad, magnet_crush_rib_testbed.stl]
2026-06-08 Add crush-rib trial-01 log entry (2026-06-07)
    SV08 PHATTY / Sunlu Clear PETG. 5×1mm bore too tight — only 0.05mm
    protrusion insertable. 6×1.5mm: 0.25–0.30mm holds; all sit proud.
    Next iter: deeper wells (+0.5mm), wider 5×1mm bore, standard settings.
2026-06-08 Update trial-01 log: add full OrcaSlicer profiles + PHATTY analysis
    Captures why PHATTY (0.59mm layer / 1.4mm wall / 1.13 flow) is marginal
    for these features. 5×1mm bore effectively closed by over-extrusion.
    6×1.5mm 0.25mm protrusion holds but all sit proud — well depth +0.5mm needed.
2026-06-08 Fixed: col_label row hardcoding, row_label bore overlap, redundant union, stale header comments; Added: $fn reduction, CHAMFER_R assert, col-0 zero-engagement note (code-review --fix)
    [magnet_crush_rib_testbed.scad]
2026-06-08 Add wrap log: magnet-crush-rib-testbed session 2026-06-07
2026-06-08 Add wiki: seed magnet-press-fit.md with crush-rib recipe from trial-01
2026-06-28 Add first-pass Hutchfinity casing
    Refs #18
    [casing.scad]
2026-06-28 Clarify casing thicknesses and peg placeholders
    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
    [casing.scad]
2026-06-28 Scale reserved peg positions by footprint
    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
    [casing.scad]
2026-06-28 Remove speculative casing scaling rules
    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
    [casing.scad]
2026-06-28 Parameterize preview peg count and spacing
    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
    [casing.scad]
2026-06-28 Make casing slot-based and tub-agnostic
    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
    [casing.scad, hutchfinity-assembly.scad]
2026-06-28 Size casing for regular 20u tub
    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
    [casing.scad, hutchfinity-assembly.scad]
2026-06-28 Add width-wise peg holes and knob part
    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
    [casing.scad, hutchfinity-assembly.scad, knob.scad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]
2026-06-28 Bulge optional knob pull end
    [knob.scad]
2026-07-04 Add casing fit validation target
    [casing-fit-test.scad, casing.scad, hutchfinity-assembly.scad]
2026-07-05 Add peg socket fit testbed
    [peg_socket_fit_testbed.scad]
2026-07-05 Record casing fit STL bounds
2026-07-05 Add casing mouth fit gauge
    [casing_mouth_fit_gauge.scad]
2026-07-05 Document casing fit test critique
    [casing_mouth_fit_gauge.scad]
2026-07-05 Fix casing peg socket mating interface
    [casing.scad]
2026-07-05 Add peg stack interface testbed
    [peg_stack_interface_testbed.scad]
2026-07-05 Revise stack peg coupon for side-wall edge
    [peg_stack_interface_testbed.scad]
2026-07-05 Add ribbed peg fit geometry
    [casing.scad, peg.scad, peg_socket_fit_testbed.scad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]
2026-07-05 Move casing sockets off wall edges
    [casing.scad, peg_stack_interface_testbed.scad]
2026-07-05 Lay pegs down and center casing sockets
    [casing.scad, peg.scad, peg_socket_fit_testbed.scad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]
2026-07-05 Move stack sockets onto external lands
    [casing.scad, peg_stack_interface_testbed.scad]
2026-07-06 Restore flat casing validation target
    [casing.scad]
2026-07-06 Restore flat casing stack sockets
    [casing.scad]
2026-07-09 Validate casing fit print set geometry
    [casing-fit-test.scad, casing.scad, casing_mouth_fit_gauge.scad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]
2026-07-26 Add Mini basket carrier comparison probe
    [basket_carrier_comparison.scad, basket_carrier_probe.scad]
2026-07-26 Archive Mini basket carrier probe wrap
2026-09-10 Archive Hutchfinity fit and low-floor prototype results (#36)
    Preserve the session's physical fit results, magnet-test pivot, low-floor floor-mode direction, and explicit physical reopen gates without promoting prototype geometry into production source.
2026-09-18 Fix stale bin parameters and printer lane
2026-09-25 docs: Bind production approval to the exact artifact lane
    Require the current validation receipt for the exact artifact, printer,
    profile and material tuple, including invalidation rules. Keep large-part
    and bin/cup production approvals independent.
    Refs #41
2026-09-25 feat: add deterministic source presentation packet
    [single-slot-exploded.scad, single-slot-hero.scad]
2026-09-25 experiment: measure baseplate tessellation with explicit fit limits
    [matrix.tsv]
2026-11-01 Changed: parametric tubs and a small generator app replace the STL tubs
    Port the thin-floor design to scad/tub.scad with the corrected height rule
    (0.50 mm air gap plus the measured 4.30 mm stack overlap, replacing 2.01 mm of
    leftover rounding). Add scad/hutchfinity.scad and hutchfinity.py to build a
    matched tub, grid insert, casing, pegs, pull, bin, or baseplate at any size.
    Removed: the nine old tub STLs and the two testbeds that only served them.
    Corrected: casing default slot height now tracks the 20h tub.
    Bin and baseplate STLs stay because the bin catalog pins them by hash.
    Claude-Session: https://claude.ai/code/session_01LYkrG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
2026-11-01 Added: Orca-ready module builds, a clickable shortcut, and every option as an argument
    The generator now writes one 3MF per print job plus a manifest, exposes every
    dimension and quantity on the command line and in the app, and can install a
    Mac Desktop app that updates itself from main.
    Changed: one 90 x 32.9 mm pull that scales down uniformly, with its guide, on
    smaller tubs. Lighter default mesh: a Regular tub is about 56k facets, down
    from about 88k.
    Fixed: the catalog's source revision now follows the bin STLs and their build
    inputs only. Removing the old tubs had moved that revision and failed its
    tests. The catalog is repinned to the last commit that touched those files; a
    rebuild r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
2026-11-01 Changed: one pull per tub, tubs start at 5h, and every argument has a range
    Each tub now comes with exactly one pull; the pull count is no longer an
    option. Tub, casing, peg and pull targets reject a tallest bin under 5h. Bins
    and baseplates keep their own 1 to 40 range.
    Added: a lowest and highest value for every count and design option, enforced
    in the command line and the app, shown in --help and on the form. A test builds
    every option at both ends of its range. A module too big for the stated bed is
    refused.
    Claude-Session: https://claude.ai/code/session_01LYkrGgT38EJdCoNrka7jQN
2026-11-01 Removed: generated STLs and the old build script
    Removes all 126 bin and 3 baseplate STLs and build-stl.sh, and ignores
    generated meshes from now on.
    Changed: a catalog bin is now its generator recipe, not a stored file. Physical
    evidence applies to the model generated from that recipe. Receipts name tested
    SKUs instead of output hashes. The 104 bins outside the build list leave the
    catalog.
    Added: a test that builds all 22 catalog bins and checks their dimensions.
    Fixed: the basket comparison testbed renders its own baseplate.
    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
2026-11-01 Fixed: restore the grid height option
    The range change dropped this option by accident. It returns with a range of
    5 to 8 mm.
    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
2026-11-02 Changed: every run builds one complete module, with fewer options
    The generator now takes only a size and builds one tub, one casing, its pegs,
    one pull and one bin. Choosing a target, the quantity options, the bed size and
    the mesh-density options are gone. Baseplates are gone because the separate grid
    does that job.
    Changed: the floor choice is integral-grid or separate-grid. A separate grid
    always comes with its grid file. Both floors now use one 1.30 mm thickness, so
    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
2026-11-02 Fixed: Orca reported open edges on generated bins
    Tiny slivers in the bin source collapsed when written at 3MF precision, leaving
    2 open edges. Vertices are now welded at 0.001 mm and collapsed triangles are
    dropped before the closed-solid check.
    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
2026-11-02 Added: a cup generator
    `hutchfinity.py cup` and a Cup form in the app build one cup from cells wide,
    cells deep, height, compartments and wall, each with its own range. A height of
    1 is refused because the source breaks into separate pieces there.
    Removed: the sample bin from each module, now that cups have their own generator.
    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
